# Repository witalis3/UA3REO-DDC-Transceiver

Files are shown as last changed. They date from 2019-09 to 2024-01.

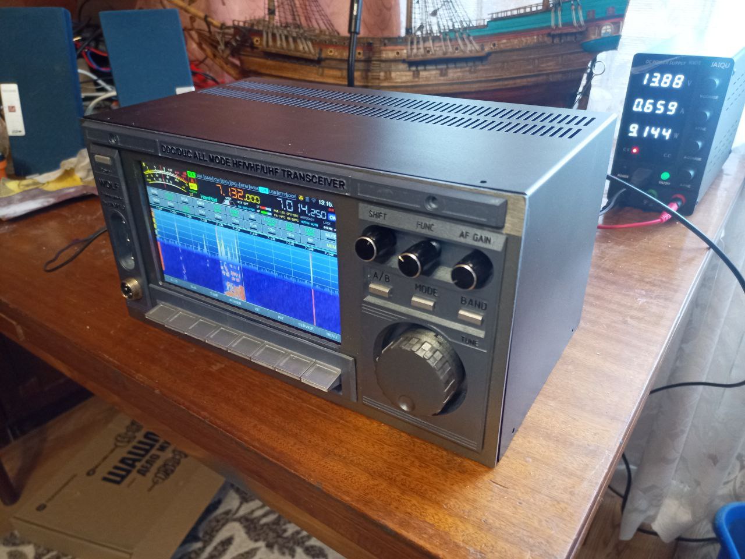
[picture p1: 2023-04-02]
Schematic/Wolf/CASE/7/Panel/photo_2023-04-01_13-19-56.jpg

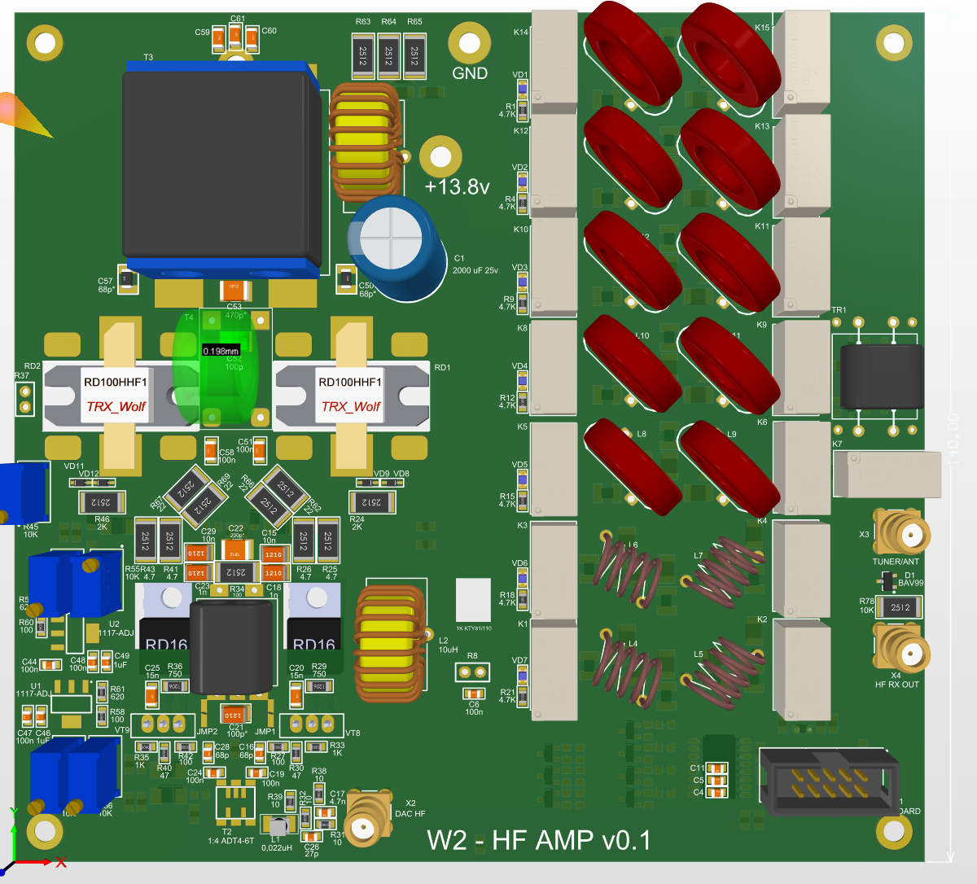
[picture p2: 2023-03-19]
Schematic/Wolf-2/Altium_Designer/W2-HF_AMP/HFAmp_UP_v01.png

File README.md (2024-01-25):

# Transceiver "Wolf"
DDC-DUC SDR Tranceiver project https://ua3reo.ru/tag/transiver-ua3reo/

* Community telegram channel: https://t.me/TRX_Wolf
* На русском https://github.com/XGudron/UA3REO-DDC-Transceiver/blob/master/README.ru-RU.md

## Principle of operation

The RF signal is digitized by a high-speed ADC chip and fed to an FPGA processor. <br>
It performs DDC / DUC conversion (digital frequency shift down or up the spectrum) - by analogy with a direct conversion receiver. <br>
The I and Q quadrature signals from the conversions are fed to the STM32 microprocessor. <br>
It filters, (de) modulates and outputs audio to an audio codec / USB. It also handles the entire user interface. <br>
When transmitting, the process occurs in the opposite order, only at the end of the chain there is a DAC, which converts the digital signal back to analog RF. <br>

## Specifications

* Receiving frequencies: 0 MHz - 750 MHz with fading each 61.44 MHz (above 145 MHz - without input filters)
* Transmission frequencies: 0 MHz - 150 MHz with fading on 110 MHz
* TX power (QRP version): 7W+ (HF), 5W (VHF)
* TX power (QRP++ DB5AT version): 20W (HF), 7W (VHF)
* TX power (RU4PN/WF-100D version): 100W (HF), 50W+ (VHF)
* Two antenna inputs
* Modulation types (TX / RX): CW, LSB, USB, AM, FM, WFM, DIGI
* LNA, Preamplifier
* Adjustable attenuator 0-31dB
* Band pass filters
* ADC dynamic range (16 bit) ~100dB
* Supply voltage: 13.8V (overvoltage and polarity reversal protection)
* Consumption current when receiving: ~0.7А (3'2 QRP), 0.9A (7' BIG)
* Current consumption during transmission: ~2.5А+ (QRP), 15A+ (BIG)
* Support for different displays: RA8875/HX8357B/HX8357C/ST7789/ST7796S/ST7735S/ILI9341/ILI9481/ILI9486

## Transceiver Features

* Panorama (spectrum + waterfall) up to 384 kHz wide
* Panorama tweaks and themes
* Dual receiver (mixing A + B or A&B audio in stereo)
* Adjustable bandwidth: HPF from 0Hz to 2700Hz, LPF from 100Hz to 20kHz
* Integrated SWR/power meter (HF)
* Automatic and manual Notch filter
* Switchable AGC (AGC) with adjustable attack rate
* Range map, with the ability to automatically switch modes
* Digital Noise Reduction (DNR), Pulse Noise Reduction (NB)
* CAT virtual COM port (FT-450 / TS-2000 emulation, RTS - PTT, DTR - CW)
* USB operation (audio transmission, IQ, CAT, KEY, PTT)
* RDS/CW/RTTY decoder, self-control, gauss filter
* SWR Graphs
* Spectrum analyzer
* FT8 receiver/transmitter
* Automatic send FT8 qso to log https://allqso.ru/
* WSPR Beacon
* VOX
* Equalizer TX/RX, reverber
* SSB/FM Scanner mode
* Support SDHC/SDSC/SDXC memory cards up to 16Gb
* WAV files radio recording and playback, fast broadcast recorded CQ message
* AGC takes into account the characteristics of human hearing (K-Weighting)
* TCXO frequency stabilization (it is possible to use an external clock source, such as GPS)
* WiFi operation: Time synchronization, virtual CAT interface (see Scheme/WIFI-CAT-instruction.txt)
* Tangent support Yaesu MH-36 и MH-48
* Hardware self-testing
* Firmware update over USB, SD, WiFi
* Digital pre-distortion
* And other.. (see menu)

### RF Parameters

Sensitivity at 10 dB SNR, LNA enabled:

* <150 MHz | -131 dBm | 63.0 nV
* 435 MHz | -121 dBm | 0.2 uV

Out-of-band emissions:

* 14 MHz -69 dBc
* 28 MHz -63 dBc
* 145 MHz -48 dBc -55 dBc

## Build

I ordered the boards in the Chinese service JLCPCB, they and their schemes are in the Scheme folder. <br>
After assembly, you need to flash FPGA and STM32 chips. <br>
If necessary, calibrate the transceiver through the appropriate menu <br>
WiFi module ESP-01 must have fresh firmware with SDK 3.0.4 and higher, and AT commands 1.7.4 and higher <br>

## Management

* **AF GAIN** - Volume
* **RIT / GAIN** - When the RIT function is active - smooth offset from the selected transceiver frequency. Inactive - IF gain control
* **ENC MAIN** - Main encoder for frequency control and menu settings
* **ENC 2** - Auxiliary encoder for menu operation. In normal mode, quickly switches the frequency, in CW fast change WPM
* **ENC 2[click]** - In CW mode, toggles between fast step and WPM selection, in other modes it opens the bandwidth properties.
* **BAND -** - Switch to the band below
* **BAND +** - Switch to higher band
* **MODE -** - Mode group switching SSB-> CW-> DIGI-> FM-> AM
* **MODE +** - Switching subgroup mod LSB-> USB, CW_L-> CW_U, DIGI_U-> DIGI_L, NFM-> WFM, AM-> IQ-> LOOP
* **FAST** - Mode of fast x10 rewinding of the frequency by the main encoder (configurable)
* **FAST [clamp]** - Frequency step settings
* **PRE** - Turn on the preamplifier (LNA)
* **PRE [clamp]** - Turn on the driver and / or amplifier ADC
* **ATT** - Turn on the attenuator
* **REC** - Save audio to SD card
* **CQ** - Play recorded CQ-message from SD card
* **MUTE** - Mute the sound
* **MUTE [clamp]** - Scanner mode
* **AGC** - Turn on AGC (automatic gain control)
* **AGC [clamp]** - AGC settings
* **A = B** - Setting the second bank of the receiver equal to the current
* **BW** - Switch to bandwidth selection menu (LPF)
* **BW [clamp]** - Switch to bandwidth selection menu (HPF)
* **TUNE** - Turn on the carrier for tuning the antenna
* **RF POWER** - Transmitter power selection
* **RF POWER [clamp]** - Squelch setting
* **A / B** - Switches between VFO-A / VFO-B receiver settings banks
* **A / B [clamp]** - Enable automatic mode change by bendmap
* **DOUBLE** - Turn on the dual receiver
* **DOUBLE [clamp]** - Switching between the modes of the dual receiver A&B (each channel of the headphones has its own path) or A + B (mixing signals of 2 receivers)
* **DNR** - Enable digital noise reduction
* **DNR [clamp]** - Turn on the impulse noise suppressor (NB)
* **NOTCH** - Turn on the automatic Notch filter to eliminate narrowband interference
* **NOTCH [clamp]** - Turn on the manual Notch filter to eliminate narrowband interference
* **SPLIT** - Allows you to split transmission and reception to different VFO banks
* **RIT [clamp]** - Enables RIT control from the front panel
* **WPM** - Switch to key speed selection menu (WPM)
* **WPM [clamp]** - Automatic key enable
* **MENU** - Go to the menu
* **MENU [clamp]** - Enable key lock LOCK
* **MENU [at power on]** - Reset transceiver settings
* **MENU [at power on+PRE]** - Reset transceiver settings and calibration
* **RIT** - Offset of the receiving frequency relative to the current frequency (TX without offset)
* **XIT** - Offset of the transmission frequency relative to the current frequency (RX without offset)

## Settings

### TRX Settings

* **Band Map** - Band Map, automatically switches mode depending on the frequency
* **Beeper** - Beep on key press
* **Callsign** - User callsign
* **Channel Mode** - Channel frequency mode (for LPD/PMR and etc.)
* **Custom Transverter** - Enable external transverter on non-ham band (just offset display frequency)
* **DEBUG Type** - Output of debug and service information to USB / UART ports
* **Encoder Accelerate** - Accelerate encoder on fast rates
* **Fine RIT Tune** - Fine or coarse tuning for RIT/XIT (encoder or resistor)
* **Freq Step xxx** - Frequency step by main encoder in each mode, Hz
* **FAST Step Multiplier** - Frequency step multiplier for FAST mode
* **ENC2 Step Mult** - Frequency step multiplier for ENC2 rotation (for CW/SSB)
* **Notch Step** - Frequency step of manual notch filter
* **Full Duplex** - Full duplex RX+TX mode
* **Locator** - User QTH locator
* **RIT Interval** - Offset range RIT (+ -)
* **XIT Interval** - Offset range XIT (+ -)
* **Split freq sync** - Synchronous VFO frequency change in SPLIT mode
* **Transverter XXcm** - Enable external ham band transverter support
* **URSI Code** - Ionogramm URSI Code https://digisonde.com/index.html#stationmap-section
* **Tropo Region** - Region for tropospheric forecast https://www.dxinfocentre.com/tropo.html 
* **Wolf Cluster** - Display Wolf TRX users on spectrum and send self data

### FILTERS Settings

* **AM/FM/CW/SSB LPF Stages** - Adjusting the slopes of the LPF filters in defferent modes
* **CW LPF Pass** - LPF cutoff frequency when working in CW
* **CW Gauss filter** - Gauss responce LPF filter
* **DIGI LPF Pass** - LPF cutoff frequency when working in DIGI
* **FM LPF Pass** - LPF cutoff frequency when working in FM
* **SSB HPF Pass** - HPF cutoff frequency when operating in SSB
* **SSB LPF Pass** - LPF cutoff frequency when operating in SSB
* **NOTCH Filter width** - Cutting width of Manual Notch filter

### RX Settings

* **ADC Dither** - Enable ADC dither for receiving weak signals
* **ADC Driver** - Turn on the preamplifier-ADC driver
* **ADC Preamp** - Turn on the preamplifier built into the ADC
* **ADC Randomizer** - Enables ADC digital line encryption
* **ADC Shutdown** - Turn off the ADC
* **AGC Gain target, LKFS** - Maximum AGC gain (Maximum volume with AGC on)
* **AGC Spectral** - Enable FFT-based AGC
* **AGC Threshold** - Enabling the AGC opening threshold
* **Att step, dB** - Attenuator tuning step
* **Attenuation, dB** - Current attenuation
* **Auto Snap** - Automaticly track and snap to near signal frequency (CW mode)
* **AutoGainer** - Automatic ATT / PREAMP control depending on the signal level on the ADC
* **A/B Balance** - Channels balance in dual RX modes A+B and A&B
* **CODEC Gain** - Adjusting AF gain in audio codec
* **DNR xxx** - Digital squelch adjustment
* **Squelch** - Enable SSB/AM/CW/FM Squelch
* **FM Squelch level** - FM squelch level
* **IF Gain, dB** - IF gain
* **NB Threshold** - Threshold of Noise blanker
* **Free tune** - Allows you to move the reception frequency across the spectrum without changing the center frequency of the spectrum itself
* **Center After Idle** - Center the spectrum with Free Tune active after 20 seconds of inactivity
* **Noise Blanker** - Activating the Surge Suppressor
* **RX AUDIO Mode** - Audio lines control: Stereo\Left\Right
* **RX AGC Hold time** - Time before release of AGC gain in signal peaks, ms
* **RX AGC Hold limit** - Burst limit for AGC delay time
* **RX AGC Hold step up** - AGC Delay Time Step on Peaks
* **RX AGC Hold step down** - AGC Delay Falloff Step at Peaks
* **RX AGC Max gain** - Limit of AGC gain, dB
* **RX AGC Speed** - AGC (automatic signal level control) response speed for reception (more-faster)
* **RX EQ xxx** - Receiver equalizer levels
* **TRX Samplerate** - Max FFT/samplerate on CW/SSB/NFM/DIGI/etc modes
* **FM Samplerate** - Max FFT/samplerate on NFM/WFM mode
* **VAD Threshold** - VAD voice detector threshold (noise suppressor for SSB mode and SCAN mode)
* **Volume step** - AF gain step by ENC2 (X1, Lite)
* **Volume** - AF gain
* **WFM Stereo** - select WFM stereo or mono decoder
* **WFM Stereo Modulation** - Stereo FM sub-carrier level

### TX Settings

* **ATU Cap** - Tuner Capacitance Combination
* **ATU Enabled** - Turning on the automatic antenna tuner
* **ATU Ind** - Combination of tuner inductances
* **ATU T** - Tuner capacitive arm position
* **ATU Mem step, kHz** - Step of saving tuner values for frequencies into memory
* **Auto Input Switch** - Auto input switch (PTT - mix, CAT - USB)
* **CESSB** - Enable controlled-envelope single-sideband modulation
* **CESSB Compress, dB** - Signal pre-amplification level before compression in CESSB
* **Compressor MaxGain** - Maximum comressor gain
* **Compressor Speed** - TX compressor response speed for transmission (more-faster)
* **CTCSS Frequency** - Transmit FM CTCSS sub-tone frequency
* **FT8 Auto CQ** - Automatic transition to CQ mode after FT8 communication
* **Input Type** - Select audio input (microphone, line in, USB)
* **LINE Gain** - Line input codec gain
* **MIC Boost** - +20db hardware mic amplifier
* **MIC EQ xxx** - Microphone equalizer levels
* **MIC Gain** - Microphone gain
* **MIC Noise Gate** - The level below which the microphone signal is muted, dbFS
* **MIC Reverber** - Microphone reverberator level
* **Power for each band** - Save power settings for each band individually
* **Power for each mode** - Save power settings for each mode individually
* **RF Power** - Transmission power,%
* **Repeater Mode"** -  Operation mode via repeater
* **Repeater offset, kHz"** -  Transmission frequency offset in repeater mode
* **SelfHear Volume** - Self Hearing (CW/DIGI) volume relative to the overall transceiver volume
* **TUNER Enabled** - Turning on the antenna tuner
* **Two Signal tune** - Two-signal generator in TUNE mode (1.0 + 2.2kHz)
* **VOX Threshold, dbFS** - VOX Threshold, dbFS
* **VOX Timeout, ms** - VOX transmission delay after silence, milliseconds
* **VOX** - TX Voice activation

### CW Settings

* **Auto CW Mode** - Automatic transition to CW mode when the key is pressed
* **CW In SSB** - Allow CW TX manipulation in SSB mode
* **DotToDash Rate** - Keyer dash to dot length rate
* **Edges smooth, ms** - Smoothing signal edges
* **Iambic Keyer** - Enable Iambic mode keyer
* **Iambic Type** - Type of Iambic keyer (A/B)
* **Key Invert** - Invert dash/dot on key
* **Key timeout** - Time before stopping the transmission mode after releasing the key
* **Keyer WPM** - Key Speed, WPM
* **Keyer** - Automatic Key
* **One symbol memory** - Keyer memory for one symbol for transmit
* **PTT Type** - RX/TX switch type for CW: by key or external PTT (tangent, etc.)
* **Pitch** - Detuning the receive generator from the transmit frequency
* **Self Hear** - Self-control CW (key press is heard)
* **Macros x** - Setting up macros for CW transmission
* **Macros x name** - Setting the macro name to be displayed in the interface

### SCREEN Settings

* **Bottom navi buttons** - Show bottm menu navigation buttons (for 7 inch displays)
* **Color Theme** - Select colors theme (0 - black, 1 - white, 2 - black with colored frequency)
* **Layout Theme** - Select interface theme (0 - default)
* **DX Cluster Type** - Selecting a Data Source for a DX Cluster
* **FFT 3D Mode** - Enable FFT 3D mode (0 - disabled, 1 - lines, 2 - pixels)
* **FFT Automatic** - Automatic FFT scale
* **FFT Averaging** - FFT burst averaging level. Full - automatic selection of upper and lower boundaries, Half - auto lower and manual upper, No - manual setting of the range of spectrum levels. (Remember to select the correct FFT Scale Type so that your range will fit on the screen)
* **FFT BW Style** - FFT bandwidth style: high opacity, low opacity, lines
* **FFT BW Position** - Position of the receiving band on FFT/WTF (everywhere \ at the top \ at the top + lines \ top + bottom with time delay)
* **FFT Background** - Gradient FFT background
* **FFT Color** - FFT colors: 1(blue -> yellow -> red), 2(black -> yellow -> red), 3(black -> yellow -> green), 4(black -> red), 5(black -> green), 6(black -> blue), 7(black -> white)
* **FFT Compressor** - Enable FFT peak comressor
* **FFT DXCluster Azimuth** - Add azimuth data to DX-cluster
* **FFT DXCluster Timeout** - Timeout of DX-cluser spots in minutes
* **FFT DXCluster** - Show DXCluster info over FFT
* **FFT Enabled** - Enable waterfall and FFT
* **FFT Freq Grid** - FFT and waterfall grids: 1(no grid), 2(fft grid), 3(fft+wtf grids), 4(wtf grid)
* **FFT Height** - FFT and waterfall proportional height
* **FFT Hold Peaks** - Show peaks on FFT spectrum
* **FFT Lens** - Enable FFT lens mode (magnify center of spectrum)
* **FFT Manual Bottom, dBm** - Bottom FFT threshold in manual mode
* **FFT Manual Top, dBm** - Top FFT threshold in manual mode
* **FFT Scale Type** - Y-axis style on FFT between signal amplitude and dBm to fit more dynamic range on screen (Useful when manually adjusting FFT range).
* **FFT Sensitivity** - Top threshold of FFT sensitivity in automatic mode (30 - scale to strongest signal)
* **FFT Speed** - FFT and waterfall speed
* **FFT Style** - FFT style: 1(gradient), 2(fill), 3(dots), 4(contour), 5(gradient + contour)
* **FFT Window** - Select FFT window (1-Dolph–Chebyshev 2-Blackman-Harris 3-Nutall 4-Blackman-Nutall 5-Hann 6-Hamming 7-No window)
* **FFT Zoom CW** - FFT spectrum zooming for CW Mode
* **FFT Zoom** - FFT spectrum zooming
* **FFT dBm Grid** - FFT signal power grid
* **LCD Brightness** - Set LCD brightness (not all lcd support)
* **LCD Sleep Timeout** - Idle time before the screen brightness decreases, sec (0 - disabled)
* **Show Sec VFO** - Show secondary VFO position on spectrum
* **WTF Color** - Waterfall colors: 1(blue -> yellow -> red), 2(black -> yellow -> red), 3(black -> yellow -> green), 4(black -> red), 5(black -> green), 6(black -> blue), 7(black -> white)
* **WTF Moving** - Mowe waterfall with frequency changing

### Decoders
* **CW Decoder** - Software CW receive decoder
* **CW Decoder Threshold** - CW receive decoder sensivity
* **RDS Decoder** - Enable RDS Decoder for WFM mode
* **RTTY Freq** - Central frequency of RTTY decoding
* **RTTY InvertBits** - RTTY invert 0 and 1 bits
* **RTTY Shift** - RTTY carrier shifts
* **RTTY Speed** - Speed of RTTY data
* **RTTY StopBits** - RTTY Stop bits

### WIFI Settings

* **WIFI Enabled** - Enable WiFi module (need restart after enable)
* **WIFI Network** - WiFi hotspot selection
* **WIFI Network Pass** - Set password for WiFi hotspot
* **WIFI Timezone** - Time zone (for updating the time via the Internet)
* **WIFI CAT Server** - Server for receiving CAT commands via WIFI
* **WIFI Update ESP firmware** - Start cloud autoupdate firmware for ESP-01 (if present)
* **ALLQSO.RU Token/LogId** - Token и LogID from https://allqso.ru/ web-log

### SD Card

* **File Manager** - Show SD Card file manager, support WAV playback and deleteing files, listening and broadcasting recordings, as well as updating firmware from a memory card
* **Record CQ message** - Record a short message for quick broadcast
* **USB SD Card Reader** - Enable USB SD Card reader
* **Export Settings** - Export settings and calibration data to SD card
* **Import Settings** - Import settings and calibration data from SD card
* **Format SD card** - Format media drive

### Satellites

* **SAT Mode** - Enable satellite mode
* **Download TLE** - Download current satellite data
* **Select SAT** - Select a satellite from the downloaded TLE file
* **QTH xxx** - Setting the Latitude\Longitude\Altitude of your location

### Calibration [appears by long pressing the MENU button in the settings menu]

* **ALC Port Enabled** - Activation of transceiver power control by an external amplifier via the ALC line: up to 1 volt - ALC is disabled and the power set in the transceiver is used. from 1.0v to 3.0v - power adjustment from 0 to 100%
* **ALC Inverted** - Invert ALC logic (3.0v - 0%, 1.0v - 100%)
* **AM Modulation Index** - Set TX AM Modulation Scale
* **ATU Averaging** - The number of steps of averaging SWR values during measurements in the operation of an automatic tuner
* **BPF x** - Bandpass filter parameters
* **CAT Type** - Type of CAT subsystem (FT-450 / TS-2000)
* **COM CAT DTR/RTS** - Configuring the functions of the DTR/RTS control lines of the CAT port
* **COM DEBUG DTR/RTS** - Configuring the functions of the DTR/RTS control lines of the Debug port
* **CICCOMP Shift** - Bit shift after CIC compensator
* **Calibrate reset** - Reset all calibrations to defaults
* **DAC Driver Mode** - DAC Driver OPA2673 bias mode (2 = 100% bias, 1 = 75% bias, 0 = 50% bias)
* **DAC Shift** - Bit shift of the output to the DAC
* **ENABLE 2200m/60m/6m/4m/FM/2m/AIR/Marine Band/70cm** - Enable hidden bands
* **EXT xxx** - External port control by band (EXT3, EXT2, EXT1, EXT0) - open drain
* **Encoder acceleration** - The encoder acceleration on faster rotation speeds
* **Encoder debounce** - Time of debouncing contacts of the main encoder
* **Encoder invert** - Invert the rotation of the main encoder
* **Encoder on falling** - The encoder is triggered only when level A falls
* **Encoder slow rate** - Deceleration rate of the main encoder
* **Encoder2 debounce** - Time of debouncing contacts of the additional encoder
* **Encoder2 invert** - Invert the rotation of the additional encoder
* **Encoder2 on fall** - Mode of operation of the secondary encoder (some encoders skip a step or make an extra one)
* **FAN Full start** - Temperature of the PA for starting the fan at full speed
* **FAN Medium start** - Temperature of the PA for starting the fan at medium speed
* **FAN Medium stop** - Temperature of the PA for stopping the fan
* **FAN Medium PWM** - Adjusting the duty cycle of a PWM fan in Medium mode
* **FM Deviation Scale** - Set TX FM Deviation Scale
* **Flash GT911** - Starting the touchpad update procedure according to LCD screen resolution
* **HPF START** - HPF filter parameters
* **IF Gain MIN/MAX** - IF Gain adjusting limits
* **INA226** - Activation and calibration of the INA226 voltage/current sensor on the I2C bus
* **KTY81 Calibration** - Calibration of the KTY81 sensor (setting the resistance of the divider arm)
* **LCD Rotate** - Rotate screen at 180 degrees
* **LNA Compensation** - Compensates the S-meter value when the LNA is turned on, dBm
* **ATT Compensation** - Compensates the S-meter value when the ATT is turned on
* **LPF END** - LPF filter parameters
* **Linear Pwr Control** - Sets a linear way to change the signal amplitude when adjusting the power (if disabled - logarithmic)
* **MAX ChargePump, kHz** - Maximum PWM frequency for ChargePump circuit
* **MAX PWR on Meter** - Maximim RF power (for indication)
* **MAX Power in TUNE** - Maximum RF power in Tune mode
* **MAX RF Temp** - Maximum temperature of the PA before the protection operation
* **MAX SWR** - Maximum VSWR before protection operation
* **NOTX xxx** - Disable TX on selected bands
* **OTA Update** - Enable OTA firmware update over WiFi
* **RF GAIN xxx** - Calibration of the maximum TX output power for each range
* **RF-Unit Type** - RF-Unit Type (QRP / BIG)
* **RTC COARSE CALIBR** - Very coarse clock crystal calibration
* **RTC FINE CALIBR** - Clock crystal calibration, one division is 0.954 ppm
* **S METER** - S-meter calibration
* **SSB Power addition** - Addition of RF power in SSB power, %
* **SWR FWD/BWD RATE** - Adjustment of the transformation ratio of the SWR meter (forward / return)
* **Swap USB IQ** - Swap USB IQ output
* **Settings reset** - Reset all settings to defaults
* **TCXO Frequency, kHz** - Frequency adjustment of the reference oscillator
* **VCXO Correction** - Correction for main generator frequency offset
* **Touchpad flip** - Flip the touchpad operation horizontally/vertically
* **Touchpad timeout** - Minimum time between taps (protection against false trigger), ms
* **Touchpad click threshold** - Minimum time for triggering a short click, ms
* **Touchpad click timeout** - Maximum time for triggering a short click, ms
* **Touchpad hold timeout** - Time before a long press is triggered, ms
* **Touchpad swipe threshold** - Minimum distance to trigger a swipe, px
* **TSignal Balance** - Sets the power balance between signals in Two signal tune mode
* **TX CICCOMP Shift** - Bit shift after TX CIC compensator
* **TX Start Delay** - Delay before the RF signal is applied (ms), so that the relay has time to trigger
* **Tangent Type** - Select tangent type
* **Transverter Offset, MHz** - Offset frequency shown on the display (for custom transverters)
* **Transverter xxx IF, MHz** - Setting the IF frequency of the transverter
* **Transverter xxx RF, MHz** - Setting the RF frequency of the transceiver to match the IF

### Memory Channels

* Changing names for transceiver memory channels

### Set Clock Time

* Clock setting

### DFU Mode

* Launch STM32 USB firmware update over DFU mode

### OTA Update

* Launch FPGA/STM32 firmware update over internet

### System info

* Show info about TRX

## Services

### Spectrum Analyzer

* **Spectrum START** - Start the spectrum analyzer
* **Begin, kHz** - Starting frequency of the analyzer with a step of 1 kHz
* **End, kHz** - End frequency of the analyzer in 1 kHz steps
* **Top, dBm** - Upper threshold of the graph
* **Bottom, dBm** - Lower threshold of the graph

### WSPR Beacon

* **WSPR Beacon START** - Start WSPR beacon
* **Freq offset** - Offset from center of WSPR band
* **WSPR Band xxx** - Select bands to WSPR beacon

### DX Cluster 

* Show DX Cluster info by current band (from internet)

### Propagation 

* Show propagation statistics (from internet)

### Tropo 

* Show tropospheric forecast

### DayNight Map 

* Displaying the day/night terminator on the map (from internet)

### Ionogram 

* Displaying the ionogram for the selected URSI Code (from internet)

### SWR Analyser

* Run SWR analizer (Band SWR - on current band, HF SWR - on all HF bands, Custom SWR - in selected range)

### RDA Statistics 

* Print statistics from RDA award (from internet)

### FT8

* FT8 Receiver / transmitter

### Locator Info

* Calculate distance and azimuth from QTH-locator

### Callsign Info

* Show callsign data

### Time Beacons

* List of beacons of the exact time (for adjusting the frequency of reception by carrier)

### Self Test

* Run hardware self diagnostic

### Auto calibration

* **Calibrate SWR** - Assistant in measuring SWR and power meter
* **Calibrate Power** - Assistant in adjusting RF Power output

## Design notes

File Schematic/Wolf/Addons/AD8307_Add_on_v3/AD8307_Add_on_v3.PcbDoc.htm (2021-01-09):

Altium Reporting Options

# File in Newer Format

Date | : | 04-Dec-20
Time | : | 18:56:06
Filename | : | C:\Tisho\MyProjects\SDR_Transciever\UA3REO-DDC\Tisho_Files\Boards\AD8307_Add_on_v2\AD8307_Add_on_v2.PcbDoc

Version | Warning
Release 10 | CAUTION - New Custom Grids and Guides were introduced. Be aware that your design might contain Custom Grids and Guides that cannot be read in previous versions.
Release 10 | CAUTION - New Structured Clusters were introduced. Be aware that your design might contain Structured Clusters that cannot be read in previous versions.
Release 10 | CAUTION - New PCB 3D Movie Manager was introduced. Be aware that your design might contain 3D PCB movie that cannot be read in previous versions.
Release 10 update 1 | CAUTION - New Clearance Rule subscopes targeting differential pairs were introduced. Be aware that your design might contain Clearance Rules using those subscopes that cannot be read in previous versions.
Release 10 update 15 | CAUTION - Support of Solder Mask and Paste Mask expansions for Tracks, Arcs, Fills and Regions was introduced. Be aware that your design might contain Solder Mask and Paste Mask expansions for these types of primitives that cannot be read in the version of Altium Designer you are currently using.
Release 12 | CAUTION - Air Gap Width previously controlled by Clearance rule is now controlled by Polygon Connect Style rule's newly introduced Air Gap Width (set to default value). Suggest reviewing each Polygon Connect Style rule's Air Gap Width attribute for correctness.
Release 13 | CAUTION - Silk To Solder Mask Clearance Rules are converted to Silkscreen Over Component Pads Rules.
Release 14 | CAUTION - The Differential Pairs Routing rule added support for control of the width. Be aware that these widths must be manually entered as Width rules in this version.
Release 15 | CAUTION - Support of separate solder masks for top & bottom of pads added.
Release 15.1 | CAUTION - Support Multi-line PCB Text added.
Release 16.0 | CAUTION - Pad/Via hole size tolerance value added.
Release 17.0 | CAUTION - Component parameters added.
Release 17.0 | CAUTION - Support of backdrilling
Release 17.1 | CAUTION - Support of waived violations
Release 17.1 | CAUTION - Support of object specific keepouts

This file was generated by a later version of the software

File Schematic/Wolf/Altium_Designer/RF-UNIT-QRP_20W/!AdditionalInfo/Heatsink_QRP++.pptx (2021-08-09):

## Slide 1

Used 2 heatsinks:
SK 81/100/SA (https://www.reichelt.de/kuehlkoerper-100-mm-alu-2-2-k-w-sk-81-100-sa-p227984.html?trstct=pos_0&nbc=1) – 100 x 100 mm, Alu, 2,2 K/W
SK 81/75/SA (https://www.reichelt.de/kuehlkoerper-75-mm-alu-2-5-k-w-sk-81-75-sa-p227987.html?&trstct=pos_0&nbc=1) – 100 x 75 mm, Alu, 2,5 K/W

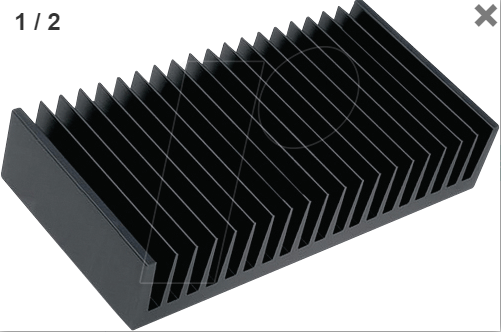
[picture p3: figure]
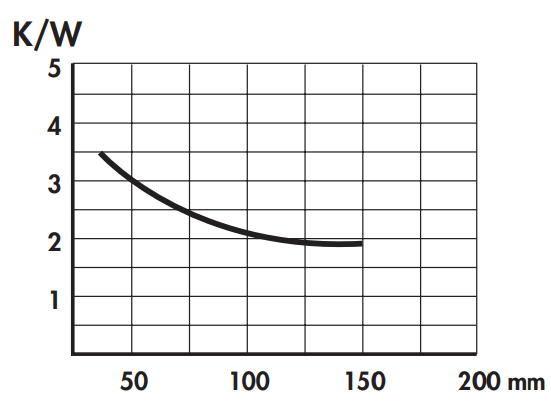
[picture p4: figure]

SK 81/100/SA drill dimensions

100

100

7x M3

9,5

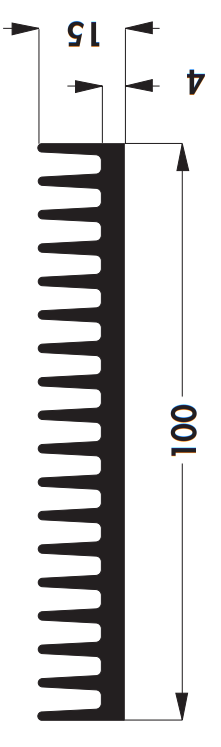
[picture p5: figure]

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
26,5

Dimensions 1

Dimensions 2

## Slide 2

SK 81/75/SA drill dimensions

75

9,5

10

10

100

9,5

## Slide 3

Bottom cover
(Dimensions 1)

11,1

17,6

17,6

103,2

11,1

97,6

117,6

190,2

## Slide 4

Bottom cover
(Dimensions 2)

115

103,2

9,5

62

190,2

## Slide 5

Copper block 1 (TIM)
- Size 39x30x10

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
2 x Ф 3,5

15,4

35

6,1

12

7

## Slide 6

Copper block 1 (TIM)
- Size 39x20x8

8

39

15,4

2 x Ф 3,5

35

6,1

20

12

7

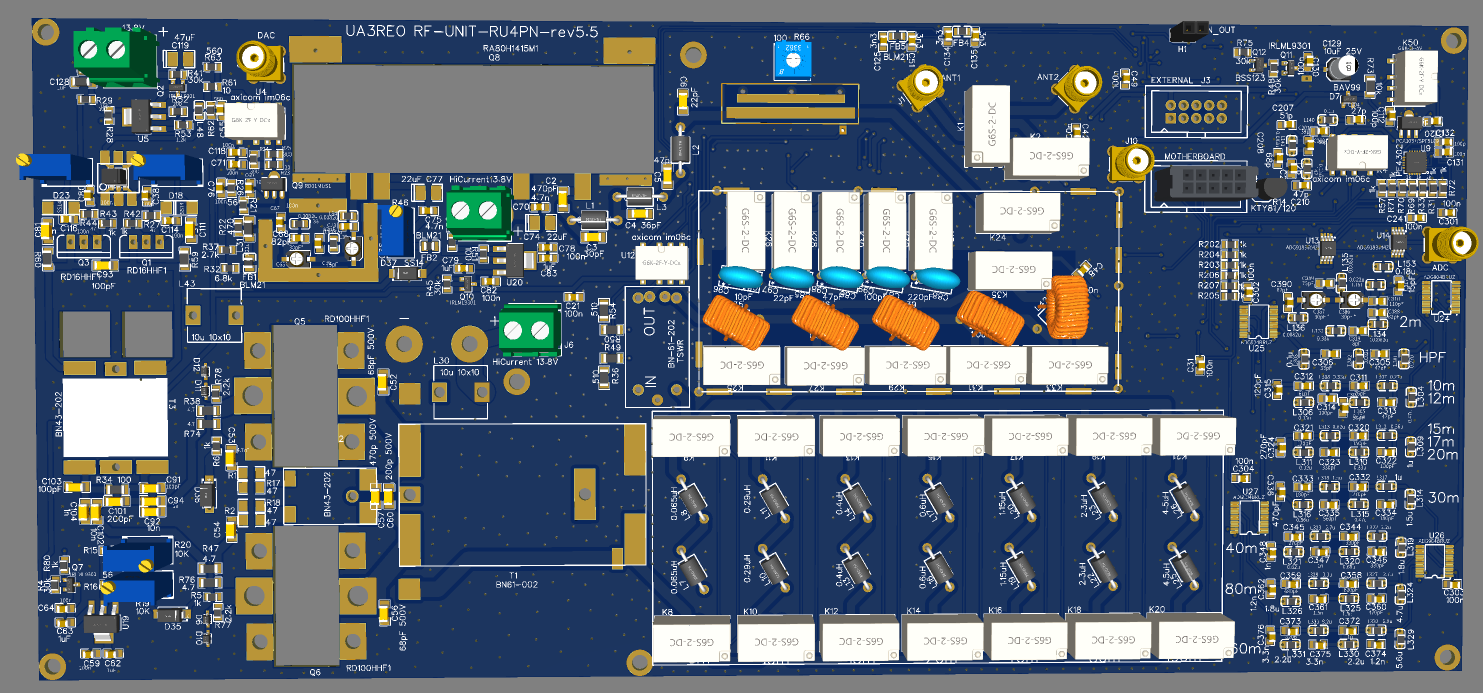
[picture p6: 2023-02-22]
Schematic/Wolf/Assembly/SCHEMATIC-RF-UNIT-BIG-RU4PN-rev5.5_UP.png

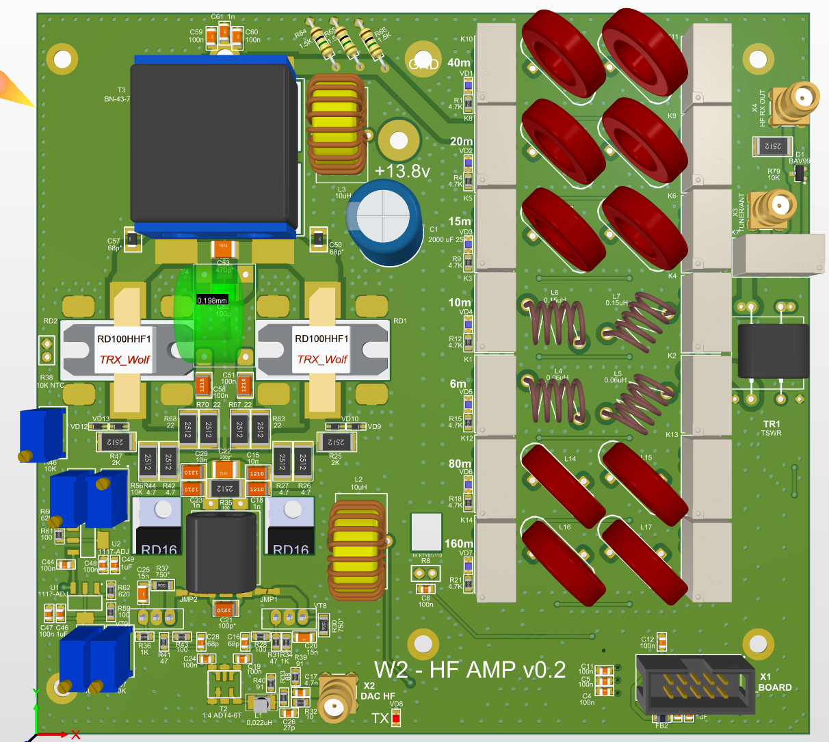
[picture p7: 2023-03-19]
Schematic/Wolf-2/Altium_Designer/W2-HF_AMP/HFAmp_UP_v02.png

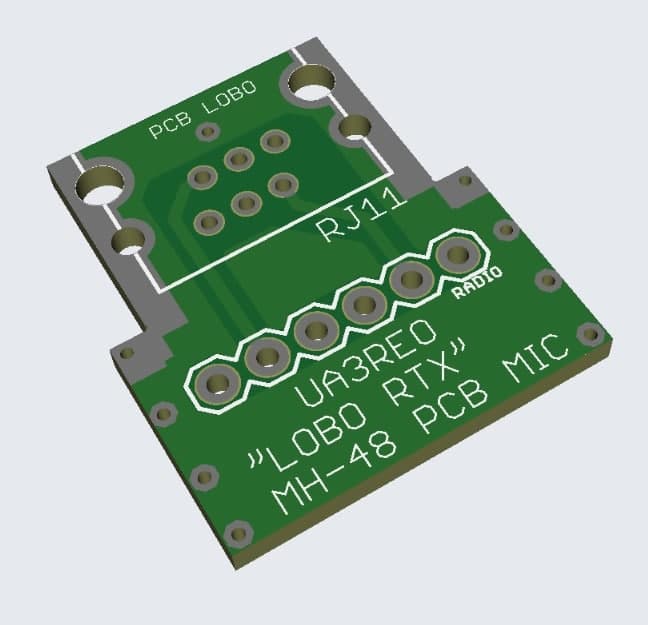
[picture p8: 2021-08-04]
Schematic/Wolf/Addons/PCB MIC MH-48/pcb2.jpg

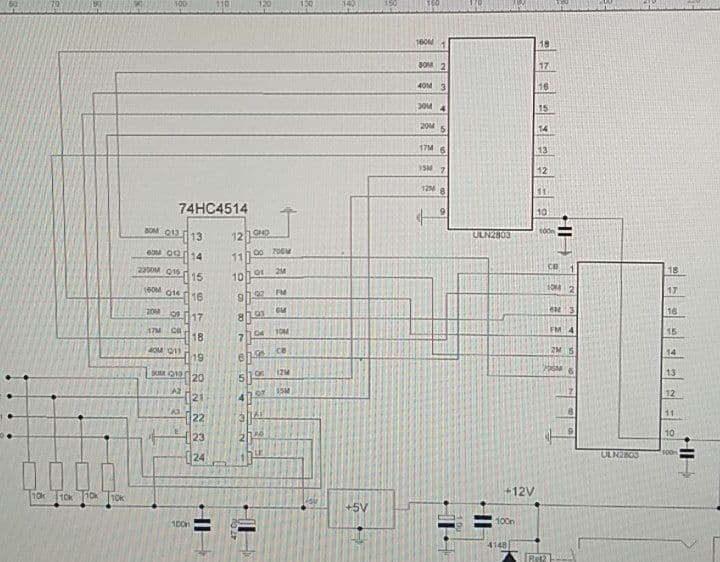
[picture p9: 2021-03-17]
Schematic/Wolf/Addons/LPF_switch.jpg

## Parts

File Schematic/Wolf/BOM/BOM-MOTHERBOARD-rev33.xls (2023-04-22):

Comment | Description | Designator | Footprint | LibRef | Quantity | LCSC Part #
JX2 | JX2 | 13.8V + | JX2 | JX2 | 1
51022-0300_1 | 51022-0300 | A_OUT, MIC_IN2 | 51022-0200 - duplicate | 51022-0300_1 | 2
CR1220 + | BR1632A/FA | B1 | KLS5-CR1220-01 | BR1632A/FA | 1
 | 2 Pin | BOOT | 51022-0200 | 51022-0200 | 1
4.7uF 16V | CAPAE_6.6x6.6h5.4 | C1 | SMC | CAPAE_6.6x6.6h5.4 | 1
22uF 10V | CAPAE_4.3x4.3h5.4 | C2, C125, C126 | CAPAE_4.3x4.3h5.4 | CAPAE_4.3x4.3h5.4 | 3
100n | CAP_0805 | C3, C4, C5, C6, C9, C16, C19, C21, C23, C31, C44, C45, C46, C47, C48, C49, C51, C53, C56, C57, C58, C59, C61, C62, C65, C67, C69, C70, C71, C72, C73, C74, C76, C78, C79, C81, C82, C83, C84, C86, C87, C88, C89, C91, C93, C94, C95, C96, C97, C98, C99, C100, C107, C109, C110, C112, C113, C114, C115, C117, C118, C120, C123, C124, C135 | CAP_0805 | CAP_0805 | 65
1uF | CAP_0805 | C7, C11, C12, C13, C14, C15, C35, C92, C119, C121, C122, C1003, C1004 | CAP_0805 | CAP_0805 | 13
10uF 10V | CAPAE_4.3x4.3h5.4 | C8, C20, C22, C24, C32, C54, C60, C75, C77, C80, C85, C1002 | CAPAE_4.3x4.3h5.4 | CAPAE_4.3x4.3h5.4 | 12
470p | CAP_0805 | C10, C90, C104, C116 | CAP_0805 | CAP_0805 | 4
10uF 10V | CAP_0805 | C17 | CAP_0805 | CAP_0805 | 1
1uF 10V | CAPAE_4.3x4.3h5.4 | C25, C26, C29 | CAPAE_4.3x4.3h5.4 | CAPAE_4.3x4.3h5.4 | 3
220p | CAP_0805 | C27, C28, C30 | CAP_0805 | CAP_0805 | 3
220uF 10V | CAPAE_4.3x4.3h5.4 | C33, C34 | EEEFC_size� | CAPAE_4.3x4.3h5.4 | 2
100pF | CAP_0805 | C36 | CAP_0805 | CAP_0805 | 1
10n | CAP_0805 | C37, C63, C137 | CAP_0805 | CAP_0805 | 3
6pF | CAP_0805 | C38, C39 | CAP_0805 | CAP_0805 | 2
10uF | CAP_0805 | C40, C41, C50, C52, C64, C66, C68 | CAP_0805 | CAP_0805 | 7
22p | CAP_0805 | C42, C43 | CAP_0805 | CAP_0805 | 2
7.5p | CAP_0805 | C55 | CAP_0805 | CAP_0805 | 1
10uF 20V | CAPAE_4.3x4.3h5.4 | C101, C108 | CAPAE_4.3x4.3h5.4 | CAPAE_4.3x4.3h5.4 | 2
1uF | CAP_1206 | C102, C103 | CAP_1206 | CAP_1206 | 2
680p | CAP_1206 | C105, C106 | CAP_1206 | CAP_1206 | 2
10p | CAP_0805 | C127 | CAP_0805 | CAP_0805 | 1
8.2n | CAP_0805 | C136 | CAP_0805 | CAP_0805 | 1
1n | CAP_0805 | C1001 | CAP_0805 | CAP_0805 | 1
SMAJ5.0A-TR | Diode | D1, D3, D29, D30, D31, D34, D35, D36, D37, D38, D39, D40 | SMBJ36CATR | SMLVT3V3 | 12 | [NoParam], test
SS34 | Schottky Diode | D1001 | SMB | D Schottky | 1
Diode | Default Diode | D1002 | C1206 | Diode | 1
SJ1-3525NG | SJ1-3525NG | J1, J2, J3, J5 | SJ1-3525NG | SJ1-3523N | 4
RF-UNIT | 2*5 Pin | J4 | 90131-0126 | 90131-0126 | 1
FPC-45P-0.5mm | Connector | J6 | FH12S45S05SH60 | FH12S-45S-0.5SH_55_ | 1
FAN | 51022-0200 | J7 | 51022-0200 | 51022-0200 | 1
USB | 2-1734035-3 | J8 | 2-1734035-3 | 2-1734035-3 | 1
DAC_OUT | SMA | J9 | 31-5431 | 31-5431 | 1
ADC | SMA | J10 | 31-5431 | 31-5431 | 1
 | 2*5 Pin | JTAG_FPGA, JTAG_STM32 | IDC10 | IDC10 | 2
3.3uH | IND_1812 | L1, L9 | IND_1812 | IND_1812 | 2
BLM21 | BLM21 | L3, L8 | CAP_0805 | IND_FERRITE_BEAD | 2
22uH | IND_1206 | L7 | IND_7x7 | IND_1206 | 1
10uH | Inductor | L37, L1001 | IND_7x7 | IND_FERRITE_CORE | 2
10uH | IND_1812 | L1002 | IND_1812 | IND_1812 | 1
PTT_IN | 51022-0200 | PTT_IN | 51022-0200 | 51022-0200 | 1
2SC5103TLP | Transistor BJT NPN | Q1 | 2SC5103TLQ | 2SC5103TLP | 1
7.5k | RES_0805 | R1 | RES_0805 | RES_0805 | 1
39k | RES_0805 | R2 | RES_0805 | RES_0805 | 1
0/NONE | By used crystal | R3 | RES_0805 | RES_0805 | 1
NONE / 0 | RES_0805 | R4, R1001, R1002 | RES_0805 | RES_0805 | 3
5.6k | RES_0805 | R5, R6, R7, R9, R51 | RES_0805 | RES_0805 | 5
30k | RES_0805 | R8, R55 | RES_0805 | RES_0805 | 2
10k | RES_0805 | R10, R13, R24, R27, R28, R30, R31, R32, R33, R36, R37, R38, R39, R46, R47, R48, R56, R57 | RES_0805 | RES_0805 | 18
680 | RES_0805 | R11 | RES_0805 | RES_0805 | 1
47k | RES_0805 | R12, R14, R15, R45 | RES_0805 | RES_0805 | 4
1.5k | RES_0805 | R16, R66 | RES_0805 | RES_0805 | 2
1k | RES_0805 | R17, R18, R19, R25, R26, R49, R50, R52 | RES_0805 | RES_0805 | 8
130 | RES_0805 | R20, R21 | RES_0805 | RES_0805 | 2
82 | RES_0805 | R22, R23 | RES_0805 | RES_0805 | 2
1m | RES_0805 | R29 | RES_0805 | RES_0805 | 1
100 | RES_0805 | R34, R35 | RES_0805 | RES_0805 | 2
22 | RES_0805 | R40, R53, R54, R58 | RES_0805 | RES_0805 | 4
24 | RES_0805 | R41, R42, R43, R64, R65 | RES_0805 | RES_0805 | 5
200 | RES_0805 | R44 | RES_0805 | RES_0805 | 1
 | RES_0805 | R59, R60 | RES_0805 | RES_0805 | 2
330 | RES_0805 | R61 | RES_0805 | RES_0805 | 1
5.6 | RES_1206 | R62, R63 | RES_1206 | RES_1206 | 2
56 | RES_0805 | R67 | RES_0805 | RES_0805 | 1
10 | RES_0603 | R68, R69 | RES_0603 | RES_0603 | 2
Thermistor 20k | Thermistor | R70 | MF52A103F3950A1 | MF52A103F3950_A1_ | 1
ADJ-5k | 306J | R71 | 306J | 306J | 1
0 | RES_0805 | R1003 | RES_0805 | RES_0805 | 1
1:1+1 | Transformer | T3 | TRANSF_ACORE2 | TRANSF_ACORE2 | 1
1:4 ADT4-6T | Transformer | T4 | TRANSF_ACORE2 | TRANSF_ACORE2 | 1
1:1 | Transformer | T6 | TRANSF_ACORE | TRANSF_ACORE | 1
PAM8406 | PAM8406 | U1 | PAM8403 | PAM8406 | 1
LD3985 | LD3985 | U2 | LD3985 | LD3985 | 1
ST1S10 | ST1S10 | U3 | ST1S10 | ST1S10 | 1
WM8731 | WM8731 | U4 | WM8731 | WM8731 | 1
STM32H743VIT6-rev.V | STM32H743VIT6 | U5 | STM32H743VIT6 | STM32H743VIT6 | 1
LM1084IS-3.3 | LM1084IS-3.3 | U6 | LM1085-3.3 | LM1085-3.3 | 1
W25Q16 | W25Q16 | U7 | W25Q16 | W25Q16 | 1
DAC5674 | Integrated Circuit | U8 | QFP50P900X900X100-49N | DAC5674IPHP | 1
25P80 | 25P80 | U9 | 25P80 | 25P80 | 1
EP4CE22E22C8N | EP4CE22E22C8N | U10 | QFP144-20-2222A | EP4CE22E22C8N | 1
1117DT-2.5 | LD1117DT-2.5 DPAK | U11 | TO228P991X238-3N | LM1117DT-ADJ | 1
1117DT-1.2 | LD1117DT-1.2 DPAK | U12 | TO228P991X238-3N | LM1117DT-ADJ | 1
1117-3.3 | LT1117CST-3.3 | U13 | LT1117CST-3.3 | LT1117CST-3.3 | 1
1117-1.8 | LT1117CST-1.8 | U14 | LT1117CST-3.3 | LT1117CST-3.3 | 1
SPEAKER | 4 pins conn | U15 | speaker conn | speaker conn | 1
LTC2208CUP | LTC2208CUP | U16 | LTC2208CUP | LTC2208CUP | 1
LTC6400IUD | Single Channel, Low Noise, Low Distortion Differential ADC Driver for 300 MHz IF, 1800 MHz Typical GBW, 4500 V/us Typical SR, 2.85 to 3.5 V, 16-Pin QFN (UD-16), Industrial, Pb-Free | U17 | LT-UD-16_N | CMP-0359-03855-2 | 1
1117DT-3.3 | LD1117DT33 DPAK | U18 | TO228P991X238-3N | LM1117DT-ADJ | 1
ADUM4160 | Integrated Circuit | U19 | SOIC127P1032X265-16N | ADUM4160BRWZ | 1
OPA2673 | Integrated Circuit | U20 | QFN65P400X400X100-17N-D | OPA2673IRGVT | 1
LM2940S-12/NOPB | 1-A, 26-V, high-PSRR, low-dropout voltage regulator | U21 | TO254P1524X483-4N | LM2940S-12/NOPB | 1
122.88Mhz | NV7050SA VG-4513CA-122.8800M-GGCT3 | XG1 | NV7050SA | NV7050SA | 1
12.288Mhz TCXO 3.3v TTL/CMOS (set other freq in fpga code) | Crystal or Oscillator | XG2 | 581L200X2ITT | 581L200X2ITT | 1
ABS25-32.768KHZ-6-T | Crystal or Oscillator | Y1 | ABS25 | ABS25-32.768KHZ-6-T | 1
8mhz | ECS-200-20-1 | Y2 | ECS-200-20-1 | ECS-200-20-1 | 1

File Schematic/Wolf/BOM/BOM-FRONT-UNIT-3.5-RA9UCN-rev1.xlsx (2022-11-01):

Comment | Description | Designator | Footprint | LibRef | Quantity
JX2 | JX2 | ACCUM, IN, MOTHERBOARD, RF-UNIT | JX2 | JX2 | 4
100n | CAP_0805 | C1, C2, C9, C14, C15, C16, C17, C18, C19, C20, C21, C22, C23, C24, C25, C26 | CAP_0805 | CAP_0805 | 16
1uF | CAP_1206 | C3 | CAP_1206 | CAP_1206 | 1
100n | CAP_1206 | C4 | CAP_1206 | CAP_1206 | 1
1n | CAP_1206 | C5 | CAP_1206 | CAP_1206 | 1
1000uF | CAP250RP | C6 | CAP250RP | CAP250RP | 1
470pF | CAP_1206 | C7 | CAP_1206 | CAP_1206 | 1
120pF | CAP_1206 | C8 | CAP_1206 | CAP_1206 | 1
22uF | EEEFC_sizeB | C10 | EEEFC_sizeB | EEEFC_sizeB | 1
8.2n | CAP_1206 | C11 | CAPC2013X94X50LL20T25 | CMP-2007-04444-1 | 1
10n | CAP_0805 | C12, C13 | CAP_0805 | CAP_0805 | 2
470uF | 10x7.7, 8.7, 10, 10.5, 12.5 | C1001, C1002 | SMD-G-10X10.2 | _SMD-G-10 | 2
1n4148w | Diode | D25, D27 | SOD3716X135N | 1n4148w | 2
SM6T15A | Diode | D28 | SMBJ36CATR | SM6T15A | 1
PEC12 | PEC12 | ENC2 | PEC12 | PEC12 | 1
OPTICAL ENCODER | OPTICAL ENCODER | ENCODER_MAIN | 644456-4 | 644456-4 | 1
ESP-01 ESP8266 | ESP-01 ESP8266 | ESP-8266 | ESP-01 ESP8266 | ESP-01 ESP8266 | 1
RUEF400 | Fuse | F1 | RUEF400 | RUEF400 | 1
MF-MSMF110_16-2 | Fuse | F2 | FUSC4632X85N | MF-MSMF110_16-2 | 1
PJ-050B | PJ-050B | IN_2 | PJ-050B | PJ-050B | 1
DM3AT-SF-PEJM5 | Connector | J2 | DM3ATSFPEJM5 | DM3AT-SF-PEJM5 | 1
FPC-45P-0.5mm | Connector | J7 | FH12S45S05SH60 | FH12S-45S-0.5SH_55_ | 1
 | LCD-MODULE_3'2_480�320 | LCD-MODULE | LCD-MODULE-3.2-480-320 | LCD-MODULE_3'2_480�320 | 1
ESP-07S |  | M1 | ESP-07S | ESP-07S | 1
IRFR9024NPBF | IRFR9024NPBF | Q1 | ONSC-DPAK-3-369C-01_V | CMP-1058-00387-1 | 1
BSS123 | N-Channel Logic Level Enhancement Mode Field Effect Transistor, 1.7 V, -55 to 150 degC, 3-Pin SOT-23, RoHS, Tape and Reel | Q2 | FAIR-SOT23-3_V | CMP-2000-04934-1 | 1
ptv09a-4225f-b102 | Adjustable Resistor PTV09 | R1, R2 | PTV09 | PTV09 | 2
4.7k | RES_0805 | R3, R4, R5, R6, R7, R8, R9, R10, R11, R12, R13, R14, R15, R16, R17, R18, R19, R29, R30, R31, R32, R33, R34, R35, R36 | RES_0805 | RES_0805 | 25
3.3k | RES_0805 | R20, R21, R22 | RES_0805 | RES_0805 | 3
0 | RES_0805 | R23, R24, R25 | RES_0805 | RES_0805 | 3
30k | RES_0805 | R26, R27, R28 | RESC2013X60X40NL20T25 | CMP-2001-00626-1 | 3
PTS645SK50LFS | PTS645SK50LFS | S1, S2, S3, S4, S5, S6, S7, S8, S9, S10, S11, S12, S13, S14, S15, S16, S17, S18, S19, S20, S21, S22, S23 | PTS645SK50LFS | PTS645SK50LFS | 23
BNX016-01 | BNX016-01 | T1 | TRANSF_ICORE | TRANSF_ICORE | 1
MCP3008-I/SL | MCP3008-I/SL | U1, U2, U3 | MCP3008-I/SL | MCP3008-I/SL | 3

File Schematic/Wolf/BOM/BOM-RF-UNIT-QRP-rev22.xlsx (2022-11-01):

Comment | Description | Designator | Footprint | Quantity
0 | RES_0805 | R49, R50 | RES_0805 | 2
0 | RES_1206 | R34, R38 | RES_1206 | 2
1:1 | 1:1 | T5 | TRANSF_ACORE2 | 1
1k | RES_0805 | R28, R29, R35, R42, R43 | RES_0805 | 5
1k | RES_0805 | R31, R65, R71, R72, R73, R74, R75, R76, R77, R78, R79, R80, R81, R82, R83, R84, R85 | RESC2013X60X40NL20T25 | 17
1n | CAP_0805 | C47, C112, C115, C120 | CAP_0805 | 4
1n | CAP_0805 | C122 | 6-0805_M | 1
1n8 | CAP_1206 | C105 | CAP_1206 | 1
1n8 100V | CAP_1206 | C92, C94 | CAP_1206 | 2
1N4148 | 1N4148 | D4 | 1N4148 | 1
1uF | CAP_0805 | C126, C128 | CAP_0805 | 2
1uH | IND_0805 | L17 | IND_0805 | 1
1.1n | CAP_0805 | C72, C74 | CAP_0805 | 2
1.2k | RES_0805 | R53 | RES_0805 | 1
1.2n | CAP_0805 | C62 | CAP_0805 | 1
1.3n | CAP_0805 | C61 | CAP_0805 | 1
1.3uH | IND_0805 | L18 | IND_0805 | 1
1.5uH | IND_0805 | L14, L25 | IND_0805 | 2
1.6uH | IND_0805 | L26 | IND_0805 | 1
2k | RES_0805 | R13 | RESC2013X60X40NL20T25 | 1
2uH | IND_0805 | L19, L22, L39, L47 | IND_0805 | 4
2.2uF | CAP_1206 | C95 | CAP_1206 | 1
2.2uF 100V | CAP_1206 | C91, C93 | CAP_1206 | 2
2.2uH | IND_0805 | L30 | IND_0805 | 1
2.4uH | IND_0805 | L31 | IND_0805 | 1
2.7uH | IND_0805 | L23, L27 | IND_0805 | 2
3n | CAP_0805 | C76 | CAP_0805 | 1
3.3n | CAP_0805 | C75 | CAP_0805 | 1
3.6uH | IND_0805 | L28 | IND_0805 | 1
4.3uH | IND_0805 | L24 | IND_0805 | 1
6.2uH | IND_0805 | L29 | IND_0805 | 1
6.5-30p | TZC3P300A110 | C86, C87 | 5025[2010] | 2
6.8uH | IND_0805 | L32 | IND_0805 | 1
8p | CAP_0805 | C16, C19 | CAP_0805 | 2
8T M2000HM 10*6*5 | Transformer | T1 | Rutrof 2 | 1
8T M2000HM 10*6*5 | Transformer | T3 | Rutrof | 1
8.2nH | IND_0805 | L34, L35, L36 | IND_0805 | 3
9.1uH | IND_0805 | L33 | IND_0805 | 1
10k | RES_0805 | R37 | RESC2013X60X40NL20T25 | 1
10k | RES_1206 | R1 | RES_1206 | 1
10n | CAP_0805 | C121 | 6-0805_M | 1
10uF 25V | CAPAE_5.3x5.3h6.1 | C129 | CAPAE_5.3x5.3h6.1 | 1
10uH | Inductor | L37, L38, L43 | IND_FERRITE_CORE | 3
11p | CAP_0805 | C103 | CAP_0805 | 1
15p | CAP_0805 | C18 | CAP_0805 | 1
15pF | CAP_0805 | C17 | CAP_0805 | 1
18 | RES_1206 | R39 | RES_1206 | 1
20p | CAP_1206 | C123, C125 | CAP_1206 | 2
22nH | IND_0805 | L48, L49, L51 | IND_0805 | 3
27nH | IND_0805 | L50 | IND_0805 | 1
27p | CAP_0805 | C55, C104 | CAP_0805 | 2
30k | RES_0805 | R33, R45, R70 | RESC2013X60X40NL20T25 | 3
30k | RES_0805 | R41, R57 | RES_0805 | 2
33p | CAP_0805 | C6 | CAP_0805 | 1
36p | CAP_1206 | C124 | CAP_1206 | 1
43p | CAP_0805 | C101 | CAP_0805 | 1
47p | CAP_0805 | C5, C13, C110 | CAP_0805 | 3
47uF 25V | CAPAE_6.6x6.6h5.4 | C119 | CAPAE_6.6x6.6h5.4 | 1
50 | RES_1206 | R55, R56 | RES_1206 | 2
56 | RES_0805 | R27, R44 | RES_0805 | 2
56p | CAP_0805 | C107 | CAP_0805 | 1
62p | CAP_0805 | C12, C102 | CAP_0805 | 2
68nH | Inductor | L44, L45 | IND_FERRITE_CORE_1 | 2
68p | CAP_0805 | C108 | CAP_0805 | 1
82p | CAP_0805 | C11 | CAP_0805 | 1
91nH | IND_0805 | L2, L41 | IND_0805 | 2
100n | CAP_0805 | C1, C2, C3, C4, C38, C80, C113, C114, C116, C117, C118, C130, C133, C134, C135, C136, C137, C139, C140, C141, C142 | CAP_0805 | 21
100n | CAP_0805 | C131 | 6-0805_M | 1
100n | CAP_1206 | C81, C111 | CAP_1206 | 2
100nH | IND_0805 | L3, L40 | IND_0805 | 2
100p | CAP_0805 | C9 | CAP_0805 | 1
100p | CAP_0805 | C127, C132 | 6-0805_M | 2
110p | CAP_0805 | C8, C10, C22, C89 | CAP_0805 | 4
120 | RES_0805 | R32, R46 | RES_0805 | 2
120p | CAP_0805 | C15, C21 | CAP_0805 | 2
130p | CAP_0805 | C14, C88, C90 | CAP_0805 | 3
160nH | IND_0805 | L5, L42 | IND_0805 | 2
160p | CAP_0805 | C20 | CAP_0805 | 1
180nH | IND_0805 | L6, L53, L54 | IND_0805 | 3
180p | CAP_0805 | C33, C34 | CAP_0805 | 2
200 | RES_0805 | R52 | RES_0805 | 1
220nH | IND_1206 | L46 | IND_1206 | 1
240p | CAP_0805 | C32 | CAP_0805 | 1
270nH | IND_0805 | L1, L7 | IND_0805 | 2
270p | CAP_0805 | C24, C45 | CAP_0805 | 2
300 | RES_1206 | R47, R48 | RES_1206 | 2
300p | CAP_0805 | C23 | CAP_0805 | 1
330nH | IND_0805 | L10, L52, L55 | IND_0805 | 3
330p | CAP_0805 | C44 | CAP_0805 | 1
360nH | IND_0805 | L8, L11 | IND_0805 | 2
360p | CAP_0805 | C46 | CAP_0805 | 1
470nH | IND_0805 | L4, L15 | IND_0805 | 2
470p | CAP_0805 | C36, C60 | CAP_0805 | 2
510 | RES_0805 | R36, R54 | RES_0805 | 2
510p | CAP_0805 | C35 | CAP_0805 | 1
560 | RES_0805 | R3, R7, R8, R9, R10, R11, R12 | RES_0805 | 7
560nH | IND_0805 | L16 | IND_0805 | 1
560p | CAP_0805 | C59 | CAP_0805 | 1
620nH | IND_0805 | L12 | IND_0805 | 1
680nH | IND_0805 | L20 | IND_0805 | 1
750nH | IND_0805 | L21 | IND_0805 | 1
750p | CAP_0805 | C58 | CAP_0805 | 1
820nH | IND_0805 | L13 | IND_0805 | 1
820p | CAP_0805 | C73 | CAP_0805 | 1
910nH | IND_0805 | L9 | IND_0805 | 1
910p | CAP_0805 | C48 | CAP_0805 | 1
2027-07-SM-RPLF | 2027-07-SM-RPLF | U18 | 200307SMRPLF | 1
51022-0200 | 51022-0200 | AMP1_PWR, AMP2_PWR, FAN_OUT | 51022-0200 | 3
ADC | SMA | J2 | 31-5431 | 1
ADG904BRUZ-R | Integrated Circuit | U4, U15, U16, U17 | SOP65P640X120-20N | 4
ADG918BRMZ | Integrated Circuit | U8, U10, U11, U12, U13, U14 | SOP65P490X110-8N | 6
ADJ-1k | 306J | R30, R40 | 306J | 2
ANT1 | SMA | J1 | 31-5431 | 1
ANT2 | SMA | J5 | 31-5431 | 1
Axicom V23079 | Axicom V23079 | K1 | V23079 | 1
BAT46JFILM | Diode | D1, D3 | SOD2513X117N | 2
BAV99 | BAV99 | D24 | SOT23 | 1
BSS123 | N-Channel Logic Level Enhancement Mode Field Effect Transistor, 1.7 V, -55 to 150 degC, 3-Pin SOT-23, RoHS, Tape and Reel | Q6, Q7, Q8 | FAIR-SOT23-3_V | 3
DAC | SMA | J9 | 31-5431 | 1
EXTERNAL | 2*5 PIN | J3 | 90131-0126 | 1
IRLML9301 | MOSFET | Q2, Q5 | SOT23 | 2
JX2 | JX2 | J8 | 1986717-2 | 1
KTY81/120 | Integrated Circuit | R14 | TO254P420X460X770-2P | 1
LM1117DT-5.0 | Integrated Circuit | U6 | TO228P991X238-3N | 1
LT1117IST-ADJ | LT1117IST-ADJ | U5 | LT1117IST-ADJ | 1
MOTHERBOARD | 2*5 PIN | J4 | 90131-0126 | 1
PE4312 | Integrated Circuit | U9 | QFN50P400X400X90-21N | 1
PGA-103+ / SPF5189Z | PGA-103+ / SPF5189Z | Q4 | SOT89 | 1
RD07MVS1 | RD07MVS1 | Q1, Q3 | RD07MVS1 | 2
SMAJ5.0A-TR | Diode | D2 | SMBJ36CATR | 1
SN74HC595D | 8-Bit Shift Registers With 3-State Output Registers, D0016A, TUBE | U1, U3, U7 | D0016A_L | 3
SS14 | SS14 | D18, D23 | SS14 | 2
SWR_TANDEM_MATCH | SWR_TANDEM_MATCH | TSWR | SWR_TANDEM_MATCH | 1
TRANSF_OUT | TRANSF_OUT | T4 | TRANSF_OUT | 1
ULN2003BDR | ULN2003BDR | U2 | ULN2003BDR | 1

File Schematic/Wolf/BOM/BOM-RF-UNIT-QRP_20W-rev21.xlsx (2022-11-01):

Comment | Description | Designator | Footprint | Quantity
0 | RES_0805 | R49, R50 | RES_0805 | 2
0 | RES_1206 | R34, R38 | RES_1206 | 2
1:1 | 1:1 | T5 | TRANSF_ACORE2 | 1
1k | RES_0805 | R28, R29, R35, R42, R43 | RES_0805 | 5
1k | RES_0805 | R31, R65, R71, R72, R73, R74, R75, R76, R77, R78, R79, R80, R81, R82, R83, R84, R85 | RESC2013X60X40NL20T25 | 17
1n | CAP_0805 | C47, C48, C72, C112, C115, C120 | CAP_0805 | 6
1n | CAP_0805 | C122 | 6-0805_M | 1
1n8 | CAP_1206 | C105 | CAP_1206 | 1
1n8 100V | CAP_1206 | C92, C94 | CAP_1206 | 2
1N4148 | 1N4148 | D4 | 1N4148 | 1
1uF | CAP_0805 | C126, C128 | CAP_0805 | 2
1uH | IND_0805 | L9, L17 | IND_0805 | 2
1.2k | RES_0805 | R53 | RES_0805 | 1
1.2n | CAP_0805 | C62, C74 | CAP_0805 | 2
1.5n | CAP_0805 | C61 | CAP_0805 | 1
1.5uH | IND_0805 | L14, L18, L25 | IND_0805 | 3
1.8uH | IND_0805 | L19, L26 | IND_0805 | 2
2k | RES_0805 | R13 | RESC2013X60X40NL20T25 | 1
2uH | IND_0805 | L39, L47 | IND_0805 | 2
2.2uF | CAP_1206 | C95 | CAP_1206 | 1
2.2uF 100V | CAP_1206 | C91, C93 | CAP_1206 | 2
2.2uH | IND_0805 | L22, L30, L31 | IND_0805 | 3
2.7uH | IND_0805 | L23, L27 | IND_0805 | 2
3.3n | CAP_0805 | C75, C76 | CAP_0805 | 2
3.3uH | IND_0805 | L28 | IND_0805 | 1
4.7uH | IND_0805 | L24 | IND_0805 | 1
5.6uH | IND_0805 | L29 | IND_0805 | 1
6.5-30p | TZC3P300A110 | C86, C87 | 5025[2010] | 2
6.8uH | IND_0805 | L32 | IND_0805 | 1
8p | CAP_0805 | C16, C19 | CAP_0805 | 2
8T M2000HM 10*6*5 | Transformer | T1 | Rutrof 2 | 1
8T M2000HM 10*6*5 | Transformer | T3 | Rutrof | 1
8.2nH | IND_0805 | L34, L35, L36 | IND_0805 | 3
8.2uH | IND_0805 | L33 | IND_0805 | 1
10k | RES_0805 | R37 | RESC2013X60X40NL20T25 | 1
10k | RES_1206 | R1 | RES_1206 | 1
10n | CAP_0805 | C121 | 6-0805_M | 1
10uF 25V | CAPAE_5.3x5.3h6.1 | C129 | CAPAE_5.3x5.3h6.1 | 1
10uH | Inductor | L37, L38, L43 | IND_FERRITE_CORE | 3
12p | CAP_0805 | C103 | CAP_0805 | 1
15p | CAP_0805 | C18 | CAP_0805 | 1
15pF | CAP_0805 | C17 | CAP_0805 | 1
18 | RES_1206 | R39 | RES_1206 | 1
18p | CAP_1206 | C123, C125 | CAP_1206 | 2
22nH | IND_0805 | L48, L49, L51 | IND_0805 | 3
27nH | IND_0805 | L50 | IND_0805 | 1
27p | CAP_0805 | C55, C104 | CAP_0805 | 2
30k | RES_0805 | R33, R45, R70 | RESC2013X60X40NL20T25 | 3
30k | RES_0805 | R41, R57 | RES_0805 | 2
33p | CAP_0805 | C6 | CAP_0805 | 1
33p | CAP_1206 | C124 | CAP_1206 | 1
39p | CAP_0805 | C7, C101 | CAP_0805 | 2
47p | CAP_0805 | C5, C13, C110 | CAP_0805 | 3
47uF 25V | CAPAE_6.6x6.6h5.4 | C119 | CAPAE_6.6x6.6h5.4 | 1
50 | RES_1206 | R55, R56 | RES_1206 | 2
51p | CAP_0805 | C107 | CAP_0805 | 1
56 | RES_0805 | R27, R44 | RES_0805 | 2
61p | CAP_0805 | C12 | CAP_0805 | 1
68nH | Inductor | L44, L45 | IND_FERRITE_CORE_1 | 2
68p | CAP_0805 | C102, C108 | CAP_0805 | 2
75p | CAP_0805 | C11 | CAP_0805 | 1
82nH | IND_0805 | L2, L41 | IND_0805 | 2
100n | CAP_0805 | C1, C2, C3, C4, C38, C80, C113, C114, C116, C117, C118, C130, C133, C134, C135, C136, C137, C139, C140, C141, C142 | CAP_0805 | 21
100n | CAP_0805 | C131 | 6-0805_M | 1
100n | CAP_1206 | C81, C111 | CAP_1206 | 2
100nH | IND_0805 | L3, L40 | IND_0805 | 2
100p | CAP_0805 | C9, C14, C22, C89 | CAP_0805 | 4
100p | CAP_0805 | C127, C132 | 6-0805_M | 2
110p | CAP_0805 | C8, C10 | CAP_0805 | 2
120p | CAP_0805 | C15, C21, C88, C90 | CAP_0805 | 4
150nH | IND_0805 | L5, L6, L42 | IND_0805 | 3
150p | CAP_0805 | C20 | CAP_0805 | 1
180nH | IND_0805 | L53, L54 | IND_0805 | 2
180p | CAP_0805 | C33, C34 | CAP_0805 | 2
200 | RES_0805 | R52 | RES_0805 | 1
220 | RES_0805 | R32, R46 | RES_0805 | 2
220nH | IND_1206 | L46 | IND_1206 | 1
270nH | IND_0805 | L1, L7 | IND_0805 | 2
270p | CAP_0805 | C24, C32, C45 | CAP_0805 | 3
300 | RES_1206 | R47, R48 | RES_1206 | 2
330nH | IND_0805 | L8, L10, L11, L52, L55 | IND_0805 | 5
330p | CAP_0805 | C23, C44, C46 | CAP_0805 | 3
470nH | IND_0805 | L4, L15 | IND_0805 | 2
470p | CAP_0805 | C36, C60 | CAP_0805 | 2
510 | RES_0805 | R36, R54 | RES_0805 | 2
560 | RES_0805 | R3, R7, R8, R9, R10, R11, R12 | RES_0805 | 7
560nH | IND_0805 | L12, L16 | IND_0805 | 2
560p | CAP_0805 | C35 | CAP_0805 | 1
680nH | IND_0805 | L20 | IND_0805 | 1
680p | CAP_0805 | C59 | CAP_0805 | 1
820nH | IND_0805 | L13, L21 | IND_0805 | 2
820p | CAP_0805 | C58, C73 | CAP_0805 | 2
2027-07-SM-RPLF | 2027-07-SM-RPLF | U18 | 200307SMRPLF | 1
51022-0200 | 51022-0200 | FAN_OUT | 51022-0200 | 1
ADC | SMA | J2 | 31-5431 | 1
ADG904BRUZ-R | Integrated Circuit | U4, U15, U16, U17 | SOP65P640X120-20N | 4
ADG918BRMZ | Integrated Circuit | U8, U10, U11, U12, U13, U14 | SOP65P490X110-8N | 6
ADJ-1k | 306J | R30, R40 | 306J | 2
AFT09MS015NT1 | AFT09MS015NT1 | Q1, Q3 | AFT09MS015NT1 | 2
ANT1 | SMA | J1 | 31-5431 | 1
ANT2 | SMA | J5 | 31-5431 | 1
Axicom V23079 | Axicom V23079 | K1 | V23079 | 1
BAT46JFILM | Diode | D1, D3 | SOD2513X117N | 2
BAV99 | BAV99 | D24 | SOT23 | 1
BSS123 | N-Channel Logic Level Enhancement Mode Field Effect Transistor, 1.7 V, -55 to 150 degC, 3-Pin SOT-23, RoHS, Tape and Reel | Q6, Q7, Q8 | FAIR-SOT23-3_V | 3
DAC | SMA | J9 | 31-5431 | 1
EXTERNAL | 2*5 PIN | J3 | 90131-0126 | 1
IRLML9301 | MOSFET | Q2, Q5 | SOT23 | 2
JX2 | JX2 | J8 | 1986717-2 | 1
KTY81/120 | Integrated Circuit | R14 | TO254P420X460X770-2P | 1
LM1117DT-5.0 | Integrated Circuit | U6 | TO228P991X238-3N | 1
LT1117IST-ADJ | LT1117IST-ADJ | U5 | LT1117IST-ADJ | 1
MOTHERBOARD | 2*5 PIN | J4 | 90131-0126 | 1
PE4312 | Integrated Circuit | U9 | QFN50P400X400X90-21N | 1
PGA-103+ / SPF5189Z | PGA-103+ / SPF5189Z | Q4 | SOT89 | 1
SMAJ5.0A-TR | Diode | D2 | SMBJ36CATR | 1
SN74HC595D | 8-Bit Shift Registers With 3-State Output Registers, D0016A, TUBE | U1, U3, U7 | D0016A_L | 3
SS14 | SS14 | D18, D23 | SS14 | 2
SWR_TANDEM_MATCH | SWR_TANDEM_MATCH | TSWR | SWR_TANDEM_MATCH | 1
TRANSF_OUT | TRANSF_OUT | T4 | TRANSF_OUT | 1
ULN2003BDR | ULN2003BDR | U2 | ULN2003BDR | 1

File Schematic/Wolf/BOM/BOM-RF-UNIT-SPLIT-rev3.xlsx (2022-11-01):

Comment | Description | Designator | Footprint | Quantity
1k | RES_0805 | R31, R33, R57, R69, R70, R71, R72 | RESC2013X60X40NL20T25 | 7
1k | RES_0805 | R35 | RES_0805 | 1
1n | CAP_0805 | C112, C120 | CAP_0805 | 2
1n | CAP_0805 | C122 | 6-0805_M | 1
1N4148 | 1N4148 | D1, D4, D5, D8, D31 | SS14 | 5
2k | RES_0805 | R13 | RES_0805 | 1
10k | RES_1206 | R73 | RES_1206 | 1
10n | CAP_0805 | C121 | 6-0805_M | 1
10uF 25V | CAPAE_5.3x5.3h6.1 | C129 | CAPAE_5.3x5.3h6.1 | 1
18 | RES_1206 | R39 | RES_1206 | 1
30k | RES_0805 | R48, R75 | RES_0805 | 2
100n | CAP_0805 | C1, C107, C108, C109, C110, C130, C133, C134, C135 | CAP_0805 | 9
100n | CAP_0805 | C131 | 6-0805_M | 1
100p | CAP_0805 | C127, C132 | 6-0805_M | 2
220nH | IND_1206 | L46 | IND_1206 | 1
560 | RES_0805 | R3, R7, R8, R9, R10, R11, R12 | RES_0805 | 7
51022-0200 | 51022-0200 | FAN_OUT | 51022-0200 | 1
ADC | SMA | J2 | 31-5431 | 1
ADG918BRMZ | Integrated Circuit | U8, U10 | SOP65P490X110-8N | 2
ANT1 | SMA | J1 | 31-5431 | 1
ANT2 | SMA | J5 | 31-5431 | 1
Axicom IM06 | Axicom IM06 | U4, U12 | IM06GR | 2
BAV99 | BAV99 | D7 | SOT23 | 1
BPF_IN | SMA | J16 | 31-5431 | 1
BPF_OUT | SMA | J18 | 31-5431 | 1
BSS123 | N-Channel Logic Level Enhancement Mode Field Effect Transistor, 1.7 V, -55 to 150 degC, 3-Pin SOT-23, RoHS, Tape and Reel | Q12 | FAIR-SOT23-3_V | 1
DAC | SMA | J9 | 31-5431 | 1
EXTERNAL | 2*5 PIN | J3 | 90131-0126 | 1
G6S-2-DC12 | Relay or Contactor | K1, K2, K3 | G6S2DC12 | 3
HF_AMP_IN | SMA | J7 | 31-5431 | 1
HF_LPF_OUT | SMA | J10 | 31-5431 | 1
IRLML9301 | MOSFET | Q11 | SOT23 | 1
KTY81/120 | Integrated Circuit | R14 | TO254P420X460X770-2P | 1
LM1117DT-5.0 | Integrated Circuit | U6 | TO228P991X238-3N | 1
MOTHERBOARD | 2*5 PIN | J4 | 90131-0126 | 1
OUT_AMPS | 2*5 PIN | J11 | 90131-0126 | 1
OUT_BPF | 2*5 PIN | J14 | 90131-0126 | 1
OUT_EXT | 2*5 PIN | J20 | 90131-0126 | 1
OUT_LPF | 2*5 PIN | J15 | 90131-0126 | 1
OUT_TUNER_C | 2*5 PIN | J13 | 90131-0126 | 1
OUT_TUNER_I | 2*5 PIN | J12 | 90131-0126 | 1
PE4312 | Integrated Circuit | U9 | QFN50P400X400X90-21N | 1
PGA-103+ / SPF5189Z | PGA-103+ / SPF5189Z | Q4 | SOT89 | 1
SMAJ5.0A-TR | Diode | D2 | SMBJ36CATR | 1
STPIC6C595TTR | Integrated Circuit | U1, U2, U3, U5, U7, U11 | SOP65P640X120-16N | 6
TUNER_IN | SMA | J17 | 31-5431 | 1
TUNER_OUT | SMA | J19 | 31-5431 | 1
VHF_AMP_IN | SMA | J6 | 31-5431 | 1
VHF_LPF_OUT | SMA | J8 | 31-5431 | 1

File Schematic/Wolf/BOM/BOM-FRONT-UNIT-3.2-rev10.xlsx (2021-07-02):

Comment | Description | Designator | Footprint | Quantity
0 | RES_0805 | R23, R24, R25 | RES_0805 | 3
1n | CAP_1206 | C5 | CAP_1206 | 1
1n4148w | Diode | D25, D27 | SOD3716X135N | 2
1uF | CAP_1206 | C3 | CAP_1206 | 1
3.3k | RES_0805 | R20, R21, R22 | RES_0805 | 3
4.7k | RES_0805 | R3, R4, R5, R6, R7, R8, R9, R10, R11, R12, R13, R14, R15, R16, R17, R18, R19, R29, R30, R31, R32, R33, R34, R35, R36 | RES_0805 | 25
8.2n | CAP_1206 | C11 | CAPC2013X94X50LL20T25 | 1
10n | CAP_0805 | C12, C13 | CAP_0805 | 2
22uF 10V | EEEFC_sizeB | C10 | EEEFC_sizeB | 1
30k | RES_0805 | R26, R27, R28 | RESC2013X60X40NL20T25 | 3
100n | CAP_0805 | C1, C2, C9 | CAP_0805 | 3
100n | CAP_1206 | C4 | CAP_1206 | 1
120p | CAP_1206 | C8 | CAP_1206 | 1
470p | CAP_1206 | C7 | CAP_1206 | 1
1000uF | CAP250RP | C6 | CAP250RP | 1
BNX016-01 | BNX016-01 | T1 | TRANSF_ICORE | 1
BSS123 | N-Channel Logic Level Enhancement Mode Field Effect Transistor, 1.7 V, -55 to 150 degC, 3-Pin SOT-23, RoHS, Tape and Reel | Q2 | FAIR-SOT23-3_V | 1
DM3AT-SF-PEJM5 | Connector | J2 | DM3ATSFPEJM5 | 1
ESP-01 ESP8266 | ESP-01 ESP8266 | ESP-8266 | ESP-01 ESP8266 | 1
FPC-45P-0.5mm | Connector | J7 | FH12S45S05SH60 | 1
ILI9481 480*320 3'2 | LCD-MODULE_3'2_480х320 | LCD-MODULE | LCD-MODULE-3.2-480-320 | 1
IRFR9024NPBF | IRFR9024NPBF, Транзистор, Р-канал 55В 11А | Q1 | ONSC-DPAK-3-369C-01_V | 1
JX2 | JX2 | ACCUM, IN, MOTHERBOARD, RF-UNIT | JX2 | 4
MCP3008-I/SL | MCP3008-I/SL | U1, U2, U3 | MCP3008-I/SL | 3
MF-MSMF110_16-2 | Fuse | F2 | FUSC4632X85N | 1
OPTICAL ENCODER | OPTICAL ENCODER | ENCODER_MAIN | 644456-4 | 1
PEC12 | PEC12 | ENC2 | PEC12 | 1
PJ-050B | PJ-050B | IN_2 | PJ-050B | 1
PTS645SK50LFS | PTS645SK50LFS | S1, S2, S3, S4, S5, S6, S7, S8, S9, S10, S11, S12, S13, S14, S15, S16, S17, S18, S19, S20, S21, S22, S23 | PTS645SK50LFS | 23
ptv09a-4225f-b102 | Adjustable Resistor PTV09 | R1, R2 | PTV09 | 2
RUEF400 | Fuse | F1 | RUEF400 | 1
SM6T15A | Diode | D28 | SMBJ36CATR | 1

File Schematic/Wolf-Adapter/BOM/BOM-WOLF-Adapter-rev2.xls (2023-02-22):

Comment | Description | Designator | Footprint | Quantity
"1.2Ghz" | RF | J8 | CON: SMA | 1
"5.6Ghz" | RF | J9 | CON: SMA | 1
"10Ghz" | RF | J10 | CON: SMA | 1
"144Mhz" | RF | J6 | CON: SMA | 1
"430Mhz" | RF | J7 | CON: SMA | 1
"OUTPUTS_1" |  | J3 | CON: PLD-10 | 1
"OUTPUTS_2" |  | J4 | CON: PLD-10 | 1
"PTT" |  | J5 | CON: PLD-10 | 1
"PTT" |  | X1 | CON: PLS-5 | 1
"TRX" |  | J1 | CON: PLD-10 | 1
"TRX_VHF" | RF | J2 | CON: SMA | 1
0.1u |  | C2, C4 | CH0805C | 2
1k |  | R1, R2, R3, R4 | CH0805R | 4
1N4148 |  | VD1, VD2, VD3, VD4, VD5, VD6, VD7, VD8, VD9, VD10, VD11, VD12, VD13, VD14, VD15, VD16, VD17, VD18, VD19, VD20 | 1N4148 | 20
10k |  | R6 | CH0805R | 1
10uF |  | C1, C3 | TANTAL_B | 2
30k |  | R5 | CH0805R | 1
74HC4514D |  | IC1 | 24-SOIC (W) | 1
100n |  | C5, C6, C7, C8, C9, C10, C11, C12, C13, C14 | CH0805C | 10
BSS123 |  | VT2 | SOT23_132 | 1
G6S-2-D?12 |  | K1, K2, K3, K4, K5, K6, K7, K8, K9, K10 | G6S-2-DC12 | 10
IRLML9301 |  | VT1 | SOT23_132 | 1
LM1117DT-5-5.0 |  | U1 | SOT223 | 1
ULN2803AFWG |  | IC2, IC3 | 18-SOIC (W) | 2

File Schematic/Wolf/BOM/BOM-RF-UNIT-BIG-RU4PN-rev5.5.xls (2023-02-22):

ID | Name | Designator | Footprint | Quantity | Manufacturer Part | Manufacturer | Supplier | Supplier Part | Price
1 | 100n | C1,C7,C8,C9,C10,C11,C16,C21,C26,C31,C36,C38,C42,C47,C48,C49,C50,C59,C64,C67,C71,C76,C78,C80,C82,C89,C90,C113,C114,C116,C117,C118,C130,C131,C136,C137,C138,C139,C167,C170,C171,C241,C301,C302,C303,C304 | C0805 | 46
2 | 470pF | C2 | C1206 | 1
3 | 30pF | C3 | C1206 | 1
4 | 36pF | C4 | C1206 | 1
5 | 47pF | C5,C86 | C1206 | 2
6 | 22pF | C6,C85 | C1206 | 2
7 | 27pF | C12,C15 | C1210 | 2
8 | 20pF | C13 | C1210 | 1
9 | 100pF | C14,C17,C19,C20 | C1210 | 4
10 | 120pF | C18 | C1210 | 1
11 | 150pF | C22,C23,C25,C28 | C1210 | 4
12 | 220pF | C24,C27,C30 | C1210 | 3
13 | 330pF | C29 | C1210 | 1
14 | 470pF | C32,C33,C34,C35 | C1210 | 4
15 | 470+330pF | C37,C41 | C1210 | 2
16 | 1000pF | C39,C45 | C1210 | 2
17 | 560pF | C40 | C1210 | 1
18 | 1000+220pF | C43,C46 | C1210 | 2
19 | 1000+470pF | C44 | C1210 | 1
20 | 3n3 | C51,C125,C134,C135 | C0805 | 4
21 | 68pF 500V | C52,C56 | C1206 | 2
22 | 4.7n* | C53,C54 | C1206 | 2
23 | 27pF | C55 | C0805 | 1
24 | 470p 500V | C57 | C1206 | 1
25 | 100n | C58,C61,C106 | C1206 | 3
26 | 200p 500V | C60 | C1206 | 1
27 | 1uF | C62,C63,C79,C83,C126 | C0805 | 5
28 | 30pF* | C65,C66 | CAP-ADJ-SMD_L4.5-W3.2-L | 2 | TZC3P300A110R00 | Murata Electronics | LCSC | C107707
29 | 82pF | C68,C73,C388,C390 | C0805 | 4
30 | 10n | C69,C107,C108,C109,C110,C121,C123,C124,C133,C141,C142,C143,C144,C145,C146,C147,C148,C149,C150,C151,C152,C153,C154,C157,C158,C159,C160,C161,C162,C163,C164,C165,C166 | C0805 | 33
31 | 4.7n | C70,C75 | C0805 | 2
32 | 75pF | C72,C311,C389 | C0805 | 3
33 | 22uF | C74,C77 | CASE-B_3528 | 2
34 | 15n | C81,C111 | C1206 | 2
35 | 10pF | C84 | C1206 | 1
36 | 100pF | C87,C91,C93,C103 | C1206 | 4
37 | 220pF | C88 | C1206 | 1
38 | 10n | C92,C102 | C1206 | 2
39 | 1n | C94,C104 | C1206 | 2
40 | 2.2uF | C95 | C1206 | 1
41 | * | C96,C97,C98,C99,C100 | CAP-TH_L8.0-W4.0-P7.50-D0.6 | 5 | CC45SL3AD101JYSNA | TDK | LCSC | C2835349 | 0.006
42 | 200pF | C101 | C1206 | 1
43 | 1n8 | C105 | C1206 | 1
44 | 100p | C112,C127,C132 | C0805 | 3
45 | 1n | C115,C122,C347,C348,C372 | C0805 | 5
46 | 47uF | C119 | CASE-B_3528 | 1
47 | 68p | C120,C202,C208 | C0805 | 3
48 | 1uF | C128 | C1206 | 1
49 | 10uF 25V | C129 | CAP-D4.0×H5.5 | 1
50 | 39p | C201 | C0805 | 1
51 | 12p | C203 | C0805 | 1
52 | 27p | C204 | C0805 | 1
53 | 51p | C207 | C0805 | 1
54 | 47p | C210 | C0805 | 1
55 | 47pF | C305,C313 | C0805 | 2
56 | 33pF | C306 | C0805 | 1
57 | 39pF | C307 | C0805 | 1
58 | 110pF | C310 | C0805 | 1
59 | 61pF | C312 | C0805 | 1
60 | 100pF | C314,C322 | C0805 | 2
61 | 120pF | C315,C321 | C0805 | 2
62 | 15pF | C317 | C0805 | 1
63 | 8pF | C319 | C0805 | 1
64 | 150pF | C320 | C0805 | 1
65 | 330pF | C323,C344,C346 | C0805 | 3
66 | 270pF | C324,C332,C345 | C0805 | 3
67 | 180pF | C333,C334 | C0805 | 2
68 | 560pF | C335 | C0805 | 1
69 | 470pF | C336,C360 | C0805 | 2
70 | 820pF | C358,C373 | C0805 | 2
71 | 680pF | C359 | C0805 | 1
72 | 1.5n | C361 | C0805 | 1
73 | 1.2n | C362,C374 | C0805 | 2
74 | 3.3n | C375,C376 | C0805 | 2
75 | 30pF * | C386,C387 | CAP-ADJ-SMD_L4.5-W3.2-L | 2 | TZC3P300A110R00 | Murata Electronics | LCSC | C107707
76 | BAT46JFILM | D1,D3,D49,D50 | SOD-323_L1.8-W1.3-LS2.5-RD | 4 | BAT46JFILM | STMicroelectronics | LCSC | C111205
77 | SMAJ5.0A-TR | D2 | SMA_L4.3-W2.6-LS5.2-RD | 1 | SMAJ5.0A-TR | STMicroelectronics | LCSC | C98802 | 0.037
78 | 1N4148W | D4,D5,D8,D9,D13,D15,D17,D20,D22,D25,D27,D31,D32,D38,D39,D40,D41,D42,D43,D44,D45,D46,D47,D48,D51 | SOD-123FL_L2.6-W1.6-LS3.4-RD | 25 | 1N4148W | Tak Cheong | LCSC | C129216 | 0.003
79 | CDSOD323-T05C | D6,D10,D11,D12 | SOD-323_L1.8-W1.3-LS2.5-BI | 4 | CDSOD323-T05C | BOURNS | LCSC | C711706 | 0.048
80 | BAV99 | D7 | SOT-23-3_L2.9-W1.3-P1.90-LS2.4-BR | 1 | BAV99-7-F | DIODES | LCSC | C106919 | 0.005
81 | SS14 | D18,D23 | SS14 | 2 | SS14 | MDD | LCSC | C2480 | 0.002
82 | SS14 | D35,D36,D37 | SMA_L4.4-W2.8-LS5.4-RD | 3 | SS14 | MDD | LCSC | C2480 | 0.002
83 | BLM21 | FB1,FB2 | L0806 | 2
84 | BLM21 | FB4,FB5 | L0805 | 2 | BLM21PG300SN1D | MuRata | LCSC | C16903 | 0.004
85 | FAN_OUT | H1 | HDR-F-2.54_1X2 | 1 |  |  | LCSC | C49661 | 0.006
86 | ANT1 | J1 | SMA-TH_BWSMA-KE-Z001 | 1 | SMA-KE-P901 | DreamLNK | LCSC | C914556 | 0.109
87 | ADC | J2,J10 | SMA-TH_BWSMA-KE-Z001 | 2 | SMA-KE-P901 | DreamLNK | LCSC | C914556 | 0.109
88 | EXTERNAL | J3 | IDC-10 | 1
89 | MOTHERBOARD | J4 | IDC-10 | 1
90 | ANT2 | J5 | SMA-TH_BWSMA-KE-Z001 | 1 | SMA-KE-P901 | DreamLNK | LCSC | C914556 | 0.109
91 | HiCurrent 13.8V | J6 | CONN-TH_TY500-5.08-02P-14-00AH | 1 | TY500-5.08-02P-14-00AH | Toponelec(拓宜) | LCSC | C2828268 | 0.032
92 | HiCurrent13.8V | J7 | CONN-TH_TY500-5.08-02P-14-00AH | 1 | TY500-5.08-02P-14-00AH | Toponelec(拓宜) | LCSC | C2828268 | 0.032
93 | 13.8V | J8 | CONN-TH_TY500-5.08-02P-14-00AH | 1 | TY500-5.08-02P-14-00AH | Toponelec(拓宜) | LCSC | C2828268 | 0.032
94 | DAC | J9 | SMA-TH_BWSMA-KE-Z001 | 1 | SMA-KE-P901 | DreamLNK | LCSC | C914556 | 0.109
95 | G6S-2-12V | K1,K2,K8,K9,K10,K11,K12,K13,K14,K15,K16,K17,K18,K19,K20,K21,K24,K25,K26,K27,K28,K29,K30,K31,K32,K33,K34,K35 | RELAY-TH_G6S-2-X | 28 | G6S-2-12V | OMRON | LCSC | C28410 | 0.145
96 | axicom im06c | K4,U4,U12 | IM06C | 3 | axicom im06c |  | axicom
97 | G6K-2F-5V | K50 | RELAY-TH_G6K-2F-Y | 1 | 0 | Omron Electronics | LCSC | C231389 | 0.201
98 | 0,047uH | L1 | BEAD-TH_BD3.5-L4.7-P8.70-D0.7 | 1 | BL02RN2R1M2 | China |  | C84974
99 | 0.047uH | L2,L3 | BEAD-TH_BD3.5-L4.7-P8.70-D0.7 | 2 | BL02RN2R1M2 | China |  | C84974
100 | 0.065uH | L7,L8 | BEAD-TH_BD3.5-L4.7-P8.70-D0.7 | 2 | BL02RN2R1M2 | China |  | C84974
101 | 0.29uH | L10,L11 | BEAD-TH_BD3.5-L4.7-P8.70-D0.7 | 2 | BL02RN2R1M2 | China |  | C84974
102 | 0.4uH | L13,L14 | BEAD-TH_BD3.5-L4.7-P8.70-D0.7 | 2 | BL02RN2R1M2 | China |  | C84974
103 | 0.6uH | L16,L17 | BEAD-TH_BD3.5-L4.7-P8.70-D0.7 | 2 | BL02RN2R1M2 | China |  | C84974
104 | 1.15uH | L19,L20 | BEAD-TH_BD3.5-L4.7-P8.70-D0.7 | 2 | BL02RN2R1M2 | China |  | C84974
105 | 2.3uH | L22,L23 | BEAD-TH_BD3.5-L4.7-P8.70-D0.7 | 2 | BL02RN2R1M2 | China |  | C84974
106 | 4.5uH | L25,L26 | BEAD-TH_BD3.5-L4.7-P8.70-D0.7 | 2 | BL02RN2R1M2 | China |  | C84974
107 | 10u 10x10 | L30,L43 | B82464Z4 | 2
108 | 0.22u | L31 | L1206 | 1
109 | 0.0082u | L32,L33,L34 | L0805 | 3
110 | 0.1uH | L35 | BEAD-TH_BD3.5-L4.7-P8.70-D0.7 | 1 | BL02RN2R1M2 | China |  | C84974
111 | 0.22uH | L36 | BEAD-TH_BD3.5-L4.7-P8.70-D0.7 | 1 | BL02RN2R1M2 | China |  | C84974
112 | 0.45uH | L39 | BEAD-TH_BD3.5-L4.7-P8.70-D0.7 | 1 | BL02RN2R1M2 | China |  | C84974
113 | 1.0uH | L41 | BEAD-TH_BD3.5-L4.7-P8.70-D0.7 | 1 | BL02RN2R1M2 | China |  | C84974
114 | 2.2uH | L42 | BEAD-TH_BD3.5-L4.7-P8.70-D0.7 | 1 | BL02RN2R1M2 | China |  | C84974
115 | 0.22u | L46 | L0805 | 1
116 | 0.022u | L48 | L0805 | 1
117 | 0.0082u | L134,L135,L136 | L0805-WOLF | 3 | L0805C100MDWIT | KEMET | LCSC | C696787 | 0.037
118 | 0.1u | L140 | L0805-WOLF | 1
119 | 0.082u | L141 | L0805-WOLF | 1
120 | 0.15u | L142 | L0805-WOLF | 1
121 | 0.022u | L151 | L0805-WOLF | 1 | L0805C100MDWIT | KEMET | LCSC | C696787 | 0.037
122 | 0.18u | L153 | L0805-WOLF | 1 | L0805C100MDWIT | KEMET | LCSC | C696787 | 0.037
123 | 0.33u | L155,L308,L310,L311 | L0805-WOLF | 4 | L0805C100MDWIT | KEMET | LCSC | C696787 | 0.037
124 | 0.27u | L301,L307 | L0805-WOLF | 2 | L0805C100MDWIT | KEMET | LCSC | C696787 | 0.037
125 | 0.082u | L302 | L0805-WOLF | 1 | L0805C100MDWIT | KEMET | LCSC | C696787 | 0.037
126 | 0.1u | L303 | L0805-WOLF | 1 | L0805C100MDWIT | KEMET | LCSC | C696787 | 0.037
127 | 0.47u | L304,L315 | L0805-WOLF | 2 | L0805C100MDWIT | KEMET | LCSC | C696787 | 0.037
128 | 0.15u | L305,L306 | L0805-WOLF | 2 | L0805C100MDWIT | KEMET | LCSC | C696787 | 0.037
129 | 1u | L309,L317 | L0805-WOLF | 2 | L0805C100MDWIT | KEMET | LCSC | C696787 | 0.037
130 | 0.56u | L312,L316 | L0805-WOLF | 2 | L0805C100MDWIT | KEMET | LCSC | C696787 | 0.037
131 | 0.82u | L313,L321 | L0805-WOLF | 2 | L0805C100MDWIT | KEMET | LCSC | C696787 | 0.037
132 | 1.5u | L314,L318,L325 | L0805-WOLF | 3 | L0805C100MDWIT | KEMET | LCSC | C696787 | 0.037
133 | 1.8u | L319,L326 | L0805-WOLF | 2 | L0805C100MDWIT | KEMET | LCSC | C696787 | 0.037
134 | 0.68u | L320 | L0805-WOLF | 1 | L0805C100MDWIT | KEMET | LCSC | C696787 | 0.037
135 | 2.2u | L322,L330,L331 | L0805-WOLF | 3 | L0805C100MDWIT | KEMET | LCSC | C696787 | 0.037
136 | 2.7u | L323,L327 | L0805-WOLF | 2 | L0805C100MDWIT | KEMET | LCSC | C696787 | 0.037
137 | 4.7u | L324 | L0805-WOLF | 1 | L0805C100MDWIT | KEMET | LCSC | C696787 | 0.037
138 | 3.3u | L328 | L0805-WOLF | 1 | L0805C100MDWIT | KEMET | LCSC | C696787 | 0.037
139 | 5.6u | L329 | L0805-WOLF | 1 | L0805C100MDWIT | KEMET | LCSC | C696787 | 0.037
140 | 6.8u | L332 | L0805-WOLF | 1 | L0805C100MDWIT | KEMET | LCSC | C696787 | 0.037
141 | 8.2u | L333 | L0805-WOLF | 1 | L0805C100MDWIT | KEMET | LCSC | C696787 | 0.037
142 | RD16HHF1 | Q1,Q3 | TO220V | 2
143 | IRLML9301 | Q2,Q7,Q10 | SOT-23-3_L2.9-W1.3-P1.90-LS2.4-BR | 3 | IRLML9301TR | VBsemi Elec | LCSC | C710004 | 0.018
144 | PGA103+/SPF5189Z | Q4 | SOT-89-3_L4.5-W2.5-P1.50-LS4.2-TL | 1
145 | RD100HHF1 | Q5,Q6 | RD100HHF WOLF | 2
146 | RA80H1415M1 | Q8 | RA80H1415M1 | 1 | RA80H1415M1
147 | RD01MUS1 | Q9 | RD01MUS1 | 1
148 | IRLML9301 | Q11 | SOT-23_L2.9-W1.3-P1.90-LS2.4-BR | 1 | IRLML9301TRPBF | IR | LCSC | C82056 | 0.051
149 | BSS123 | Q12 | SOT-23-3_L2.9-W1.6-P1.90-LS2.8-BR | 1 | BSS123 | CJ | LCSC | C79015 | 0.005
150 | A022-145M2 | QF1 | A022-145M2 | 1
151 | 47 | R1,R2,R17,R18 | R1206_1 | 4 | 0 | Chian Chia Elec | LCSC | C122207 | 0.012
152 | 560 | R3,R7,R8,R9,R10,R11,R12,R62,R63 | R0805 | 9
153 | 30k | R4,R41,R45,R48,R75 | R0805 | 5
154 | 1k | R5,R6,R31,R33,R35,R42,R43,R57,R69,R70,R71,R72,R79,R80,R81,R201,R202,R203,R204,R205,R206,R207 | R0805 | 22
155 | 2k | R13 | R0805 | 1
156 | KTY81/120 | R14 | RES-TH_KTY81 | 1 | KTY81/110,112 | NXP(恩智浦) | LCSC | C1527155 | 0.201
157 | 56 | R15,R16,R26 | R0805 | 3
158 | 0 | R17*,R49,R50,R65,R67 | R1206 | 5
159 | * | R18* | R1206 | 1
160 | 10K | R19,R20 | RES-ADJ-TH_3296W | 2 | 3296W-1-102LF | BOURNS | LCSC | C57089 | 0.12
161 | 750 | R21 | R0805 | 1
162 | 470 | R22 | R0805 | 1
163 | 20 | R23 | R0805 | 1
164 | 300 | R24,R25 | R0805 | 2
165 | 47 | R27,R44 | R0805 | 2
166 | 100 | R28,R29,R51 | R0805 | 3
167 | 1K | R30,R40,R46 | RES-ADJ-TH_3296W | 3 | 3296W-1-102LF | BOURNS | LCSC | C57089 | 0.12
168 | 6.8k | R32 | R0805 | 1
169 | 100 | R34 | R1206 | 1
170 | 510 | R36,R54 | R1206 | 2
171 | 2.7k | R37 | R0805 | 1
172 | 4.7 | R38,R47,R74,R76 | R1206 | 4
173 | 18 | R39 | R1206 | 1
174 | 200 | R52 | R0805 | 1
175 | 1.2k | R53 | R0805 | 1
176 | 50 | R55,R56 | R1206 | 2
177 | 620 | R58 | R0805 | 1
178 | 430 | R59,R60 | R1206 | 2
179 | 10 | R61 | R0805 | 1
180 | 1K | R64,R68 | R1206 | 2
181 | 100 | R66 | RES-ADJ-TH_3362P | 1 | 3362P-1-105 | ReliaPro | LCSC | C20063
182 | 10k | R73 | R1206 | 1
183 | 2.2k | R77,R78 | R0805 | 2
184 | BN61-002 | T1 | BN61-002 WOLF | 1 | BN61-002
185 | BN43-202 | T2 | BN43-202 WOLF SHORT | 1
186 | BN43-202 | T3 | BN43-202_RD16 WOLF | 1
187 | 1:1 | T5 | ATD1+TC1 | 1 | TC1-1T+ | Mini-Circuits | LCSC | C879831 | 0.44
188 | VHF Tandem Meter | T6 | VHF SWR METER | 1 | VHF Tandem Meter
189 | BN-61-202 | TSWR | BN43-202_TANDEM | 1 | 2843010302 | Fair-Rite |  | 2843010302
190 | STPIC6C595TTR | U1,U2,U3,U7,U11,U21 | TSSOP-16_L5.0-W4.4-P0.65-LS6.4-BL | 6 | STPIC6C595TTR | STMicroelectronics | LCSC | C222081 | 0.391
191 | LT1117-ADJ | U5,U20 | SOT-223-3_L6.5-W3.4-P2.30-LS7.0-BR | 2 | LT1117IST#PBF | Analog Devices | LCSC | C661269 | 0.689
192 | LM1117DT-5.0 | U6 | TD03B | 1
193 | PE4302 | U9 | QFN-20L_L4.0-W4.0-P0.50-BL-EP2.0 | 1 | PE4302-EK | null | LCSC | C2763949
194 | ADG918BRMZ | U13,U14 | MSOP-8_L3.0-W3.0-P0.65-LS4.9-BL | 2 | ADG918BRMZ-500RL7 | Analog Devices | LCSC | C207406 | 0.452
195 | LT1117IST-5.0 | U19 | SOT-223-3_L6.5-W3.4-P2.30-LS7.0-BR | 1 | LT1117IST-5#TRPBF | Analog Devices | LCSC | C661276 | 1.412
196 | ADG904BRUZ | U24,U25,U26,U27 | TSSOP-20 | 4

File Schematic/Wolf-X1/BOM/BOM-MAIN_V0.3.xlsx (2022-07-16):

Посадочное место | Номинал | Количество | Footprint
MicroSD1 | DM3AT-SF-PEJM5 | 1 | Micro SD - M
B1 батарейка | CR1220 | 1 | CR1220
C1 | 7.5p | 1 | CH0603C
C2, C3 | 22p | 2 | CH0603C
C4, C7, C30, C33, C38, C39, C40, C44, C45, C46, C47, C62, C63, C64, C66, C118, C154, C176, C177, C181, C182, C184, C190, C193 | 0.1u | 24 | CH0603C
C5, C6 | 2u2 | 2 | CH0603C
C8, C37, C85, C155, C157, C164 | 10u | 6 | CH0603C
C9, C10 | 6p | 2 | CH0603C
C11, C12, C13, C14, C15, C16, C17, C18, C19, C20, C21, C22, C23, C24, C25, C26, C27, C28, C29, C54, C55, C56, C67, C76, C79, C80, C82, C83, C84, C86, C88, C89, C90, C91, C92, C93, C94, C95, C96, C97, C98, C101, C102, C103, C105, C108, C110, C112, C114, C115, C116, C117, C120, C122, C123, C124, C125, C126, C127, C128, C129, C130, C131, C132, C133, C183, C187, C207, C208 | 0.1 | 69 | CH0603C
C31, C32, C178, C179, C180 | 10uF10V | 5 | TANTAL_A
C34, C36, C41, C42, C73, C74, C191, C195, C198 | 1u | 9 | CH0603C
C35, C77, C185, C189 | 470p | 4 | CH0603C
C43 | 10p | 1 | CH0603C
C48, C49, C99 | 1n | 3 | CH0603C
C50, C51, C52 | 1uF | 3 | CH0603C
C53, C57, C58 | 220uF | 3 | POLIMER-E
C59, C60, C61, C65 | 10uF10V | 4 | TANTAL_A
C68, C70, C71 | 1uF 10V | 3 | TANTAL_A
C69, C78 | 10n | 2 | CH0603C
C72, C140, C148 | 220p | 3 | CH0603C
C75 | 10uF 10V | 1 | TANTAL_A
C81, C111 | 8.2n | 2 | CH0603C
C87, C221 | 8p | 2 | CH0603C
C100, C107 | 10uF 10V | 2 | TANTAL_B
C104, C137, C153, C220 | 110p | 4 | CH0603C
C106, C212 | 15p | 2 | CH0603C
C109 | 4.7uF 47V | 1 | POLIMER-E
C113 | 22uF 10V | 1 | POLIMER-E
C119, C204 | 120p | 2 | CH0603C
C121, C145, C201, C211 | 100p | 4 | CH0603C
C134, C138, C142, C146, C150 | 180p | 5 | CH0603C
C135, C151 | 51p | 2 | CH0603C
C136, C152 | 390p | 2 | CH0603C
C139, C147 | 43p | 2 | CH0603C
C141, C149 | 91p | 2 | CH0603C
C143, C199 | 47p | 2 | CH0603C
C144 | 330p | 1 | CH0603C
C156, C165, C172, C202 | 33p | 4 | CH0603C
C158, C174 | 39p | 2 | CH0603C
C159, C168 | 20p | 2 | CH0603C
C160, C162, C166, C214 | 22uf | 4 | CH1206C
C161, C170 | 24p | 2 | CH0603C
C163 | 27p | 1 | CH0603C
C167, C169, C171 | 4.7uF | 3 | TANTAL_A
C173, C175, C192, C194 | 6.8n | 4 | CH0603C
C186 | 10n/none | 1 | CH0603C
C188 | 2.7n | 1 | CH0603C
C196, C197 | 680p | 2 | CH0603C
C200, C203 | 6.5-30pF | 2 | C_trimer
FB1, FB2, FB3 | Ferrite_Bead | 3 | CH0805L
FB4, FB5, L2 | BLM21 | 3 | CH0805L
J1 | BOOT | 1 | CON: PLS-2
J2, J4, J5 | PJ-307 | 3 | PJ-307
L1 | 22uH | 1 | 4020
L3, L44 | 330nH | 2 | L1210
L4, L43 | 22nH | 2 | L1210
L5 | 3.3uH | 1 | IND: CDRH74
L6 | 10uH | 1 | IND: CDRH74
L7, L11, L15 | 6.2uH | 3 | L1210
L8, L12, L16 | 2.2uH | 3 | L1210
L9, L13, L17 | 12uH | 3 | L1210
L10, L14, L18 | 3.3uH | 3 | L1210
L19, L24, L28 | 0.68uH | 3 | L1210
L20, L22, L23, L37 | 2.2uH | 4 | 4020
L21, L26, L30 | 1.2uH | 3 | L1210
L31 | 270nH | 1 | L1210
L32, L34, L36 | 8.2nH | 3 | L1210
L33 | 82nH | 1 | L1210
L35 | 100nH | 1 | L1210
L40, L42 | 180nH | 2 | L1210
L41 | 27nH | 1 | L1210
R1, R2, R3, R7, R11, R13, R14, R15, R16, R23, R24, R25, R33, R42, R65, R70, R73, R87, R88 | 10k | 19 | CH0603R
R4, R48 | 11k | 2 | CH0603R
R5, R6, R9, R51, R75, R77 | 22 | 6 | CH0603R
R8, R27, R28 | 3.3К | 3 | CH0603R
R10, R12, R32, R66, R67, R68, R69, R71, R74 | 1k | 9 | CH0603R
R17 | 1.5k | 1 | CH0603R
R18, R78 | 56 | 2 | CH0603R
R19, R20 | 10 | 2 | CH0603R
R21, R22, R54, R80, R81 | 100 | 5 | CH0603R
R26 | 680 | 1 | CH0603R
R29, R30, R31, R36, R55, R56 | 47K | 6 | CH0603R
R34, R35 | none | 2 | CH0603R
R37 | 5.6k | 1 | CH0603R
R38, R39 | 82 | 2 | CH0603R
R40, R41 | 130 | 2 | CH0603R
R43 | 120k +100k parallel | 1 | CH0603R
R44, R45, R46 | 30k | 3 | CH0603R
R47, R49 | 2K | 2 | CH0603R
R50, R53 | 0 | 2 | CH0603R
R52 | 18k | 1 | CH0603R
R57, R58 |  | 2 | CH0603R
R72 | 1k5 | 1 | CH0603R
R82, R83, R84 | 330 | 3 | CH0603R
R85, R86 | 5.6 | 2 | CH0603R
T1 | 1:4 ADT4-6T | 1 | TC4-1-ADT4-6
T2 | 1:1 T1-6T | 1 | TC4-1-ADT4-6
T3 | 1:1 ADT1-1 | 1 | TC4-1-ADT4-6
U1 | W25Q16 | 1 | SOIC-8-1
U2 | STM32H743 | 1 | 100-LQFP
U3 | M25P80 | 1 | SOIC-8-1
U4 | EP4CE22E22C8N | 1 | 144-QFN
U5, U13 | LM1085-3.3 | 2 | DPAK_132
U6 | LTC6400IUD | 1 | 16-QFN 3x3
U7 | LTC2208CUP | 1 | 64-QFN 9x9
U8 | PAM8406 | 1 | SOP-16
U9 | WM8731 | 1 | 28-SSOP
U10 | LD3985M33R | 1 | SOT23-5
U11 | ACS712-20 | 1 | 8-SOIC
U12, U18 | ADG918BRMZ | 2 | 8-MSOP (NO PAD)
U14 | ST1S10 | 1 | 8-SOIC (PAD)
U15, U16 | MCP6001UT | 2 | SOT23-5
U17 | USBLC6-2SC6 | 1 | SOT23-6-ASM
U19 | SC189CSKTRT | 1 | SOT23-5
U20 | PE4302 | 1 | 20-QFN (4x4)
U21, U22, U23, U24 | FST3253 | 4 | 16-SSOP
U25 | AMS1117-1.8 | 1 | SOT223
U26 | AMS1117-3.3 | 1 | SOT223
U27 | DAC5674IPHP | 1 | 48-TQFP
U28 | OPA2673IRGVT | 1 | 16-QFN 4x4 PAD17
U29, U30, U31 | SC189 | 3 | SOT23-5
D2 | BAV-99 | 1 | SOT23_132
VD1, VD2 | 1N4108 | 2 | 1N4148
VD3 | BZT52-C5V1 | 1 | SOD123
VT1 | BSS123 | 1 | SOT23_132
VT2 | IRFR9024NPBF | 1 | D2PAK_132
X1 | USB-B | 1 | CON: USB-B
X2 | PLS-5 | 1 | CON: PLS-5
X3, X4 | PLD-10 | 2 | CON: PLD-10
X5 | CWF-3 | 1 | CON: CWF-3
X6 | Разъем DC005 | 1 | CON: PJ-102AH
X7 | PLD-10 | 1 | CON: PLD-10
X9 | PLS-3 | 1 | CON: PLS-3
X10 | ENCODER_MAIN1 | 1 | CON: PLS-4
X12, X14 | U.FL-R-SMT U FL IPEX | 2 | CON: u.Fl
X13 | "PTT" | 1 | RJ25-6pin
XG1 | 12.288Mhz TCXO 3.3v TTL/CMOS (set other freq in fpga code) | 1 | OSC: 5032
XG2 | 122.88Mhz | 1 | OCS: GENA
Y1 | 8 мГц | 1 | OSC: Hz
Y2 | ABS 32.768khz | 1 | ABS-25

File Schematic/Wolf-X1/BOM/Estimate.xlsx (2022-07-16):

№ | Название | Количество | Цена | доставка | штук | Ссылка | Чип и дип | Общая цена | Доставка
MAIN |  |  |  |  |  |  |  | 346.32 | 39.12
 | DM3AT-SF-PEJM5 | 1 | 2.94 | 0.74 | 10 | Aliexpress (https://s.click.aliexpress.com/e/_9isgm1)
 | Индуктивность SMD 0630 3.3uH | 1 | 0.63 | 0.24 | 10 | Aliexpress (https://aliexpress.ru/item/4000557059726.html?item_id=4000557059726&sku_id=10000002922152209) |  | 385.44
 | Индуктивность SMD 0630 10uH | 1 | 0.63 | 0.24 | 10 | Aliexpress (https://aliexpress.ru/item/4000557059726.html?item_id=4000557059726&sku_id=10000002922152209)
 | Индуктивность SMD 0420 2,2uH | 4 | 1.60 | 1.29 | 10 | Aliexpress (https://aliexpress.ru/item/1005001648530241.html?spm=a2g2w.productlist.0.0.7b42d5be3thNsw) | ChipDip (https://www.chipdip.ru/product/ha72l-04202r2lftr?from=suggest_product)
 | Индуктивность SMD 0530 10uH | 1 | 0.70 | 0.18 | 10 | Aliexpress (https://aliexpress.ru/item/4001035691825.html?item_id=4001035691825&sku_id=10000013672787789)
 | SC189CSKTRT | 4 | 2.75 | 1.23 | 10 | Aliexpress (https://s.click.aliexpress.com/e/_97KRnB) | ChipDip (https://www.chipdip.ru/product0/8001051325?from=suggest_product)
 | LM1085-3.3 | 2 | 0.79 | 0.75 | 1 | Aliexpress (https://s.click.aliexpress.com/e/_A281Oz)
 | ST1S10PHR | 1 | 4.85 | 2.53 | 5 | Aliexpress (https://s.click.aliexpress.com/e/_9g82VX)
 | ACS712-20 | 1 | 4.36 | 2.53 | 5 | Aliexpress (https://s.click.aliexpress.com/e/_ADbq7F)
 | LD3985M33R | 1 | 0.94 |  | 10 | Aliexpress (https://s.click.aliexpress.com/e/_AMh9kh)
 | AMS1117-3.3 | 2 | 0.92 |  | 20 | Aliexpress (https://s.click.aliexpress.com/e/_AeJeaD)
 | AMS1117-1.8 | 1 | 1.18 |  | 20 | Aliexpress (https://s.click.aliexpress.com/e/_AeJeaD)
 | MCP6001UT | 2 | 1.96 |  | 10 | Aliexpress (https://s.click.aliexpress.com/e/_9ihxe9)
 | PE4302 | 1 | 2.31 | 0.65 | 5 | Aliexpress (https://s.click.aliexpress.com/e/_AfZ1iz)
 | NV7050SA 122.88Mhz | 1 | 5.00 | 3.79 | 1 | Aliexpress (https://s.click.aliexpress.com/e/_A5JA5P)
 | 12.288Mhz | 1 | 20.00 | 3.47 | 2 | Aliexpress (https://aliexpress.ru/item/4000577979227.html?sku_id=10000003324946109)
 | PAM8406DR | 1 | 3.00 | 0.74 | 10 | Aliexpress (https://s.click.aliexpress.com/e/_A8j981)
 | M25P80-VMW6G | 1 | 1.45 |  | 10 | Aliexpress (https://s.click.aliexpress.com/e/_A6hL4Z)
 | EP4CE22E22C8N | 1 | 59.85 | 2.11 | 1 | Aliexpress (https://s.click.aliexpress.com/e/_9iUwY9)
 | STM32H743VIT6 | 1 | 17.78 |  | 1 | Aliexpress (https://aliexpress.ru/item/1005003007981742.html?mp=1&sku_id=12000023197731242)
 | 25Q16BVSIG | 1 | 1.37 |  | 5 | Aliexpress (https://s.click.aliexpress.com/e/_AqCio9)
 | WM8731 | 1 | 4.68 | 2.53 | 2 | Aliexpress (https://s.click.aliexpress.com/e/_Akey6D)
 | LTC6400IUD | 1 | 2.85 | 1.24 | 1 | Aliexpress (https://s.click.aliexpress.com/e/_AseOOZ)
 | LTC2208CUP | 1 | 11.05 | 3.16 | 1 | Aliexpress (https://s.click.aliexpress.com/e/_ADIvIz)
 | OPA2673IRGVT | 1 | 4.95 |  | 5 | Aliexpress (https://s.click.aliexpress.com/e/_AAqwKp)
 | DAC5674IPHP | 1 | 14.00 | 3.04 | 1 | Aliexpress (https://s.click.aliexpress.com/e/_9y3KyN)
 | MC306 32,768 кГц | 1 | 1.08 | 0.41 | 10 | Aliexpress (https://aliexpress.ru/item/1994878414.html?sku_id=52635197667)
 | USBLC6-2SC6 | 1 | 1.01 |  | 10 | Aliexpress (https://s.click.aliexpress.com/e/_9xdO4z)
 | hc-49s 8 МГц | 1 | 1.14 | 0.20 | 20 | Aliexpress (https://s.click.aliexpress.com/e/_9QtdNT)
 | USB B типа «мама» | 1 | 1.01 | 0.37 | 10 | Aliexpress (https://s.click.aliexpress.com/e/_A1iVsh)
 | PJ-307 | 3 | 0.73 |  | 10 | Aliexpress (https://s.click.aliexpress.com/e/_AUoOZf)
 | ADG918BRMZ | 2 | 1.17 | 0.20 | 1 | Aliexpress (https://s.click.aliexpress.com/e/_989xMD)
 | FST3253MTCX | 4 | 1.68 |  | 5 | Aliexpress (https://s.click.aliexpress.com/e/_AFJSln)
 |  |  | 180.36 | 31.64
PA UNIT
 | STPIC6C595TTR | 1 | 2.42 | 0.74 | 5 | Aliexpress (https://aliexpress.ru/item/1005001359582377.html?sku_id=12000015804019376)
 | Реле | 4 | 2.73 |  | 5 | Aliexpress (https://aliexpress.ru/item/4000017778928.html?item_id=4000017778928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)
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

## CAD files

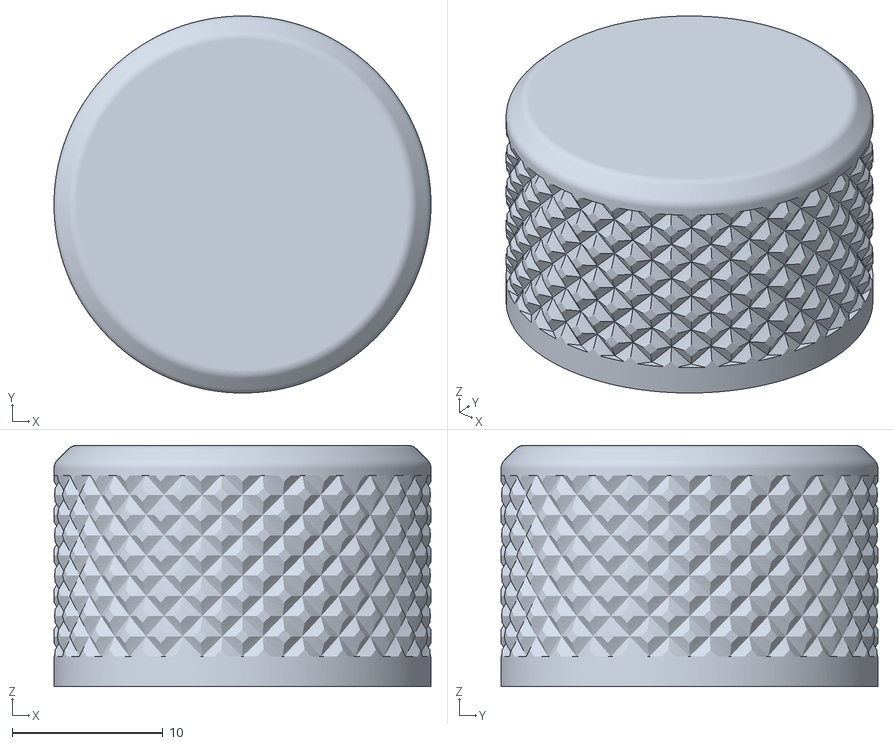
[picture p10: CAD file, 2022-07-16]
Schematic/Wolf-X1/Addons/20mm_Main_Encoder.stl
25.0 x 25.0 x 16.0

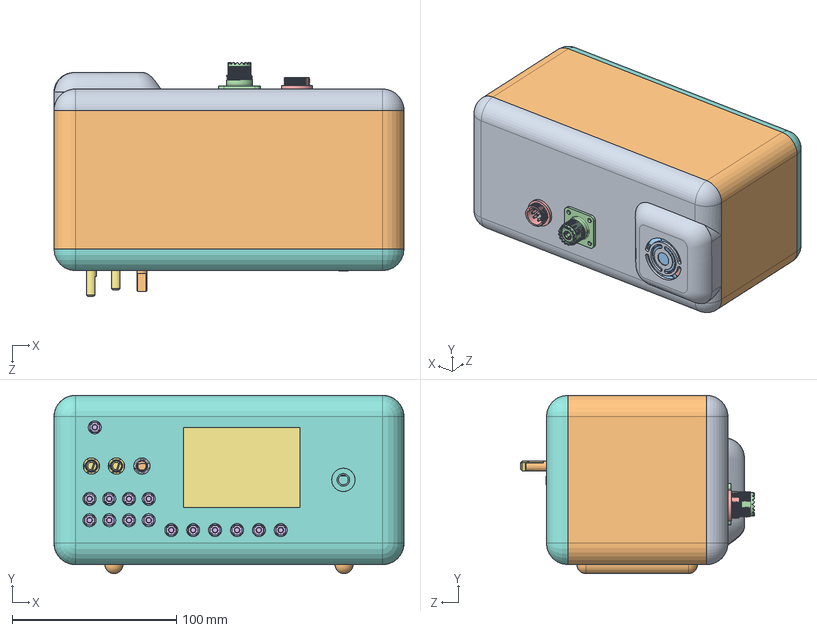
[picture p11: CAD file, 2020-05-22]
Scheme/CASE/construct.SLDASM
213.0 x 108.5 x 142.1 mm
beam_long x 4
beam_short x 4
FRONT
MB
RF
tactileswitch-long x 15
Fusion001.step
Rotary Encoder
Rotary_Encoder
D-handle
40x40x10 DC Fan
pl-259_jack
GX16-8
speaker
RotaryPotencimetr x 2
case_front
case_back
case_shell

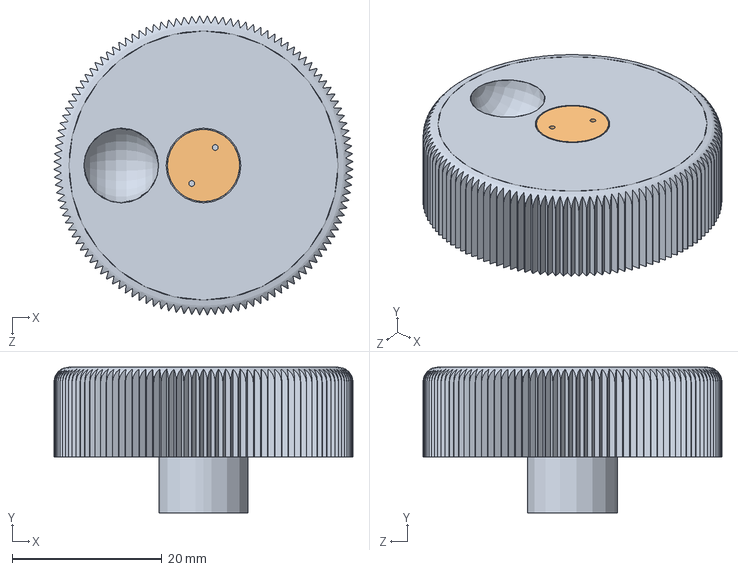
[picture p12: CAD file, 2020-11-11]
Schematic/Wolf/CASE/3'2/3DPrinter/case/shuttle_knob_construct.SLDASM
40.0 x 19.5 x 40.0 mm
shuttle_knob
shuttle_knob_cap

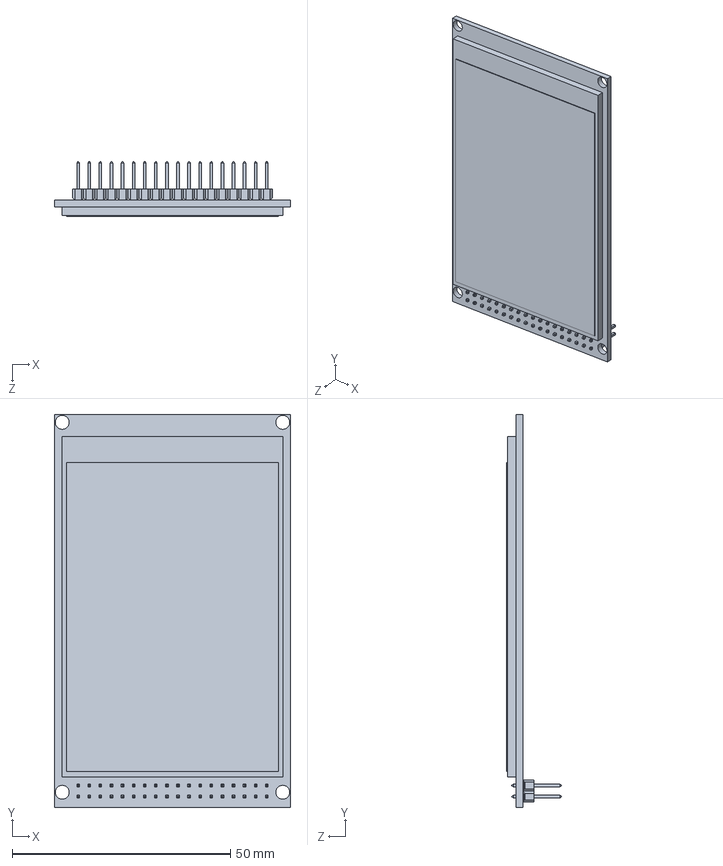
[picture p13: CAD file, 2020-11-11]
Schematic/Wolf/CASE/3'2/3DPrinter/Display480x320.SLDASM
54.1 x 90.0 x 12.6 mm

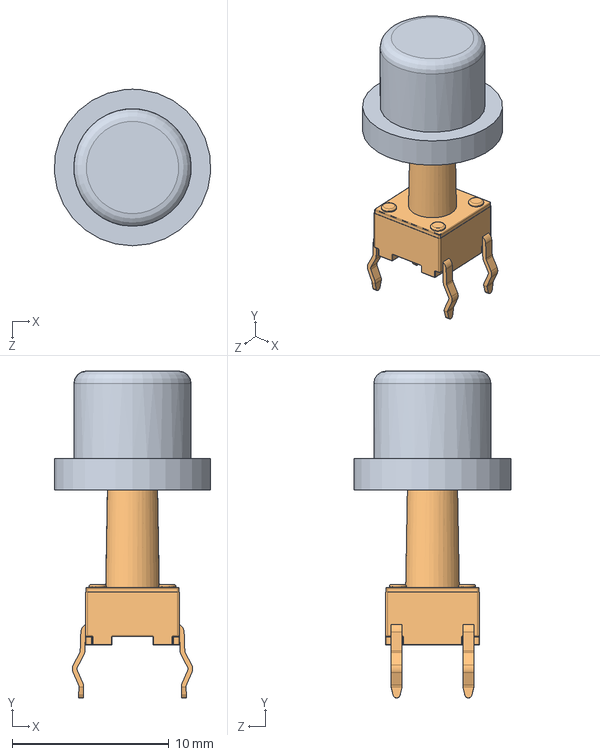
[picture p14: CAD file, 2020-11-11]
Schematic/Wolf/CASE/3'2/3DPrinter/case/button_construct.SLDASM
9.99 x 20.9 x 10.0 mm
button
tactileswitch-long

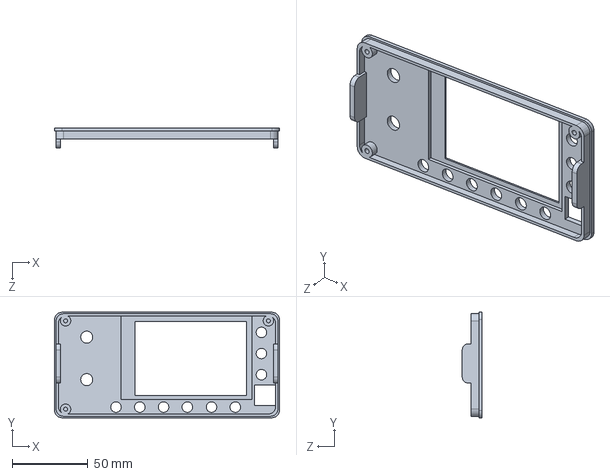
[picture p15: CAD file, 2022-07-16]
Schematic/Wolf-Lite/Case/Front Lite V2.SLDPRT
149.0 x 70.0 x 13.0 mm

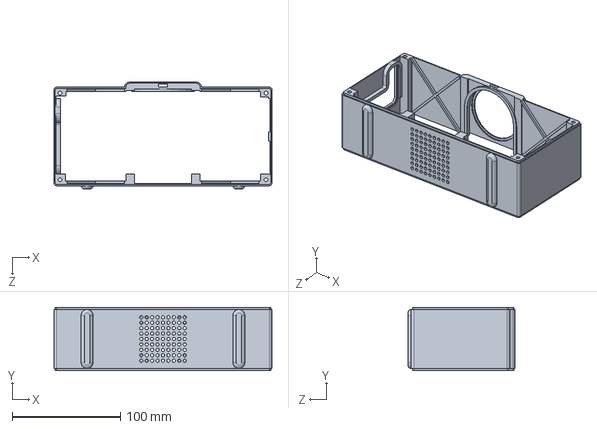
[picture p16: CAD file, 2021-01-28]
Schematic/Wolf/CASE/3'2/3DPrinter/case/case_shell.SLDPRT
201.0 x 58.4 x 98.7 mm

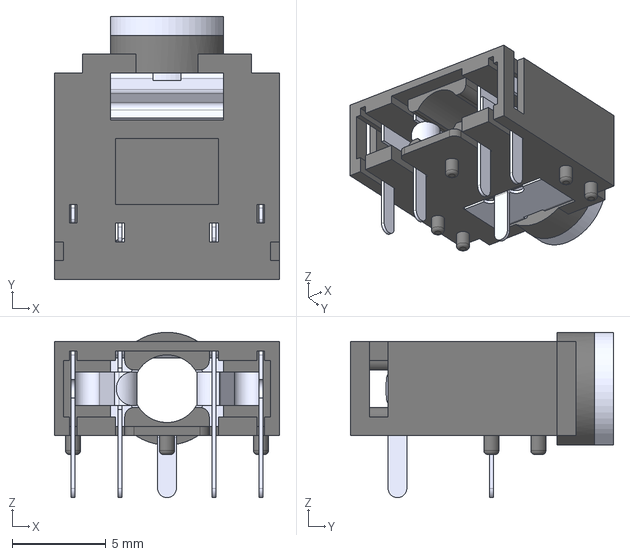
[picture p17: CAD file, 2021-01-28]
Schematic/Wolf/CASE/3'2/3DPrinter/ST-212.step
12.0 x 14.0 x 8.80 mm

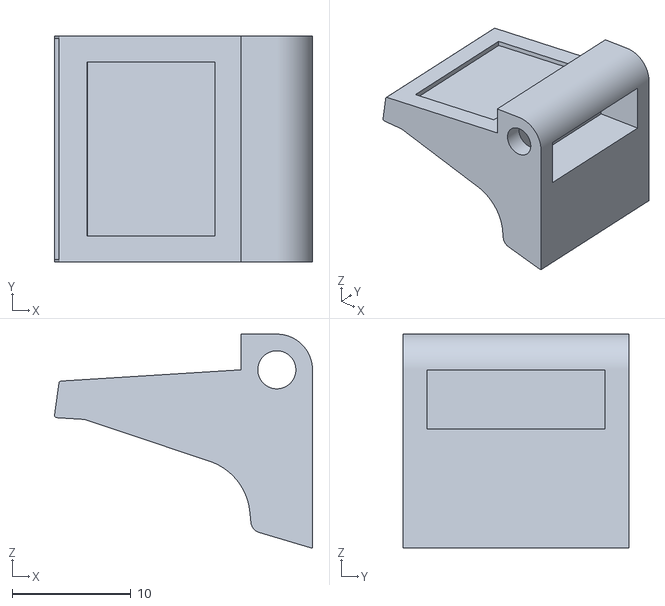
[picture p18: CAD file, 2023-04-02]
Schematic/Wolf/CASE/7/Panel/кнопка_низ_7.stl
21.7 x 19.0 x 18.0

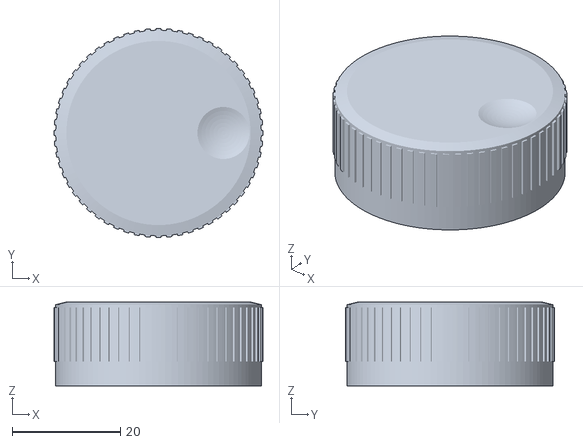
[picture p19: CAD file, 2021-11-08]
Schematic/Wolf/CASE/VFO/VFO_38mm.stl
38.6 x 38.6 x 15.5

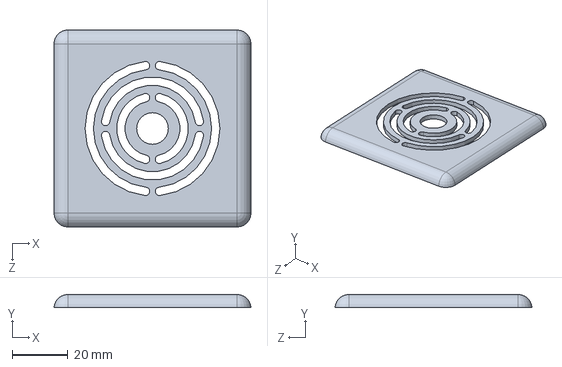
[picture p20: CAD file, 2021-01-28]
Schematic/Wolf/CASE/3'2/3DPrinter/case/case_speaker_cap.SLDPRT
71.0 x 4.70 x 71.0 mm

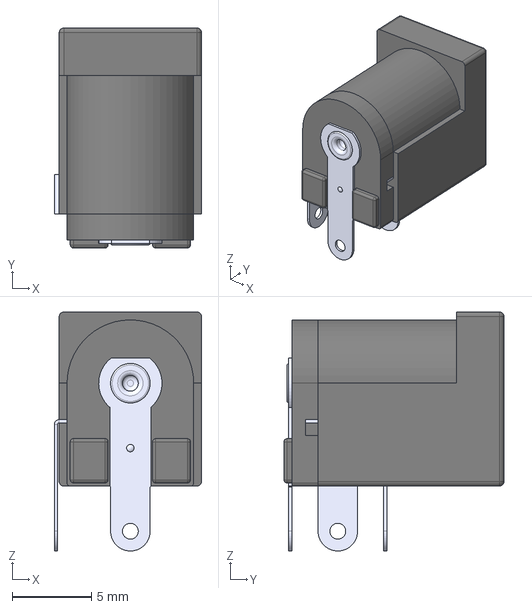
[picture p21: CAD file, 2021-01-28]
Schematic/Wolf/CASE/3'2/3DPrinter/DS-261A.step
9.30 x 13.9 x 15.1 mm

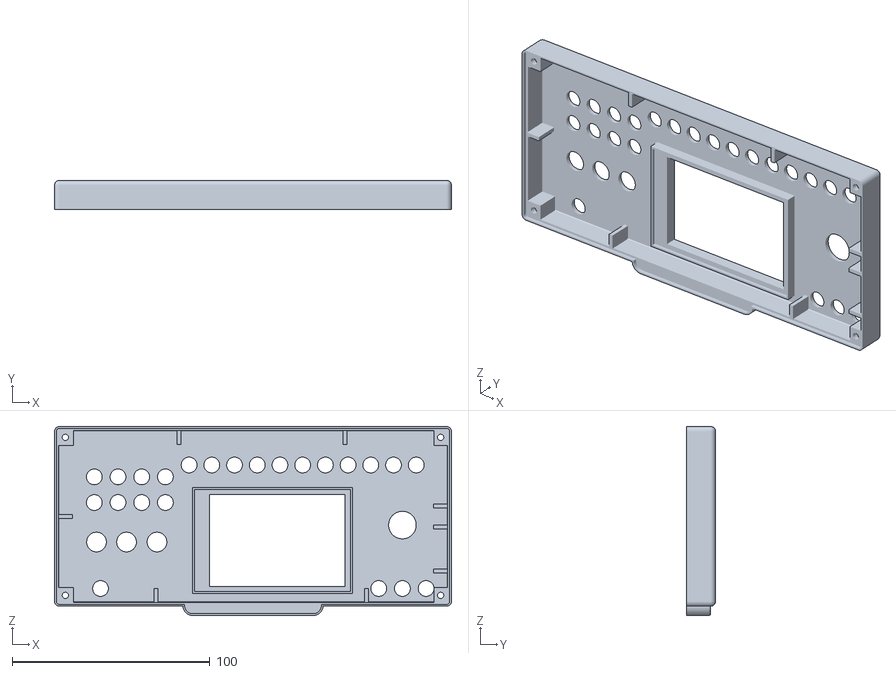
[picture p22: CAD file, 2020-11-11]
Schematic/Wolf/CASE/3'2/3DPrinter/STL/case_front.STL
201.0 x 14.8 x 95.7

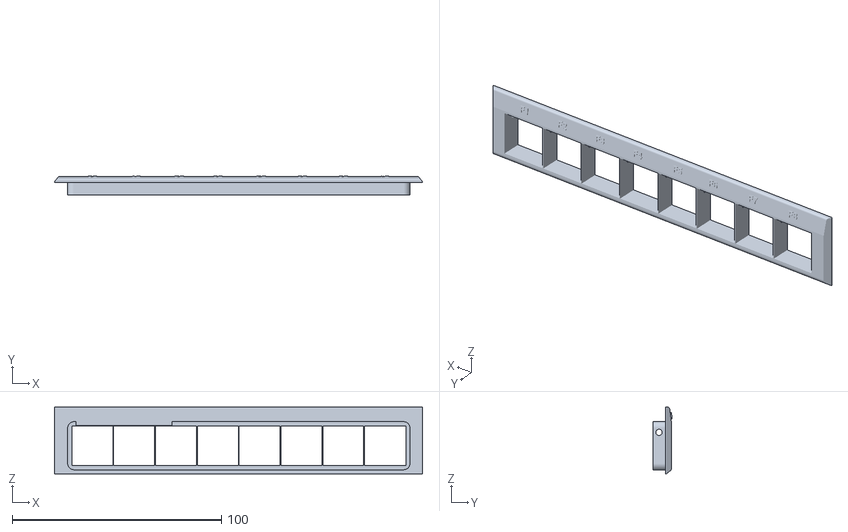
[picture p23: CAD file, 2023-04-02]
Schematic/Wolf/CASE/7/Panel/рамка_низ_7.stl
176.0 x 9.31 x 32.0

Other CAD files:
Schematic/Wolf/CASE/3'2/3DPrinter/KY-040 Rotary Encoder.SLDASM
Schematic/Wolf/CASE/3'2/3DPrinter/STL/case_shell.STL
Schematic/Wolf-Lite/Case/BOT-LITE.SLDPRT
Schematic/Wolf-X1/Addons/Milling_Top.DWG
Schematic/Wolf-Lite/Altium_Designer/Front-Unit/Wl-FRONT-EDM/16-SOIC_MCP3008-I_SL.x_t
Schematic/Wolf-Lite/Altium_Designer/Front-Unit/Wl-FRONT-EDM/BAT__CH224-2032_POWER_BAT.x_t
Schematic/Wolf-Lite/Altium_Designer/Front-Unit/Wl-FRONT-EDM/BUT__6x6_SMD_Tactile_switches.x_t
Schematic/Wolf-Lite/Altium_Designer/Front-Unit/Wl-FRONT-EDM/BUT__6x6_Tactile_switches.x_t
Schematic/Wolf-Lite/Altium_Designer/Front-Unit/Wl-FRONT-EDM/CH0805C_Capacitor.x_t
Schematic/Wolf-Lite/Altium_Designer/Front-Unit/Wl-FRONT-EDM/CH0805R_Resistor.x_t
Schematic/Wolf-Lite/Altium_Designer/Front-Unit/Wl-FRONT-EDM/CON__PLS-5_5-Connector.x_t
Schematic/Wolf-Lite/Altium_Designer/Front-Unit/Wl-FRONT-EDM/IPS_3.5_ILI9481_LCD-IPS_3.5.x_t
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

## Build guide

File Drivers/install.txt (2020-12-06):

This driver uses windows USB Virtual com port driver files
If it;s dont work, please update system drivers from https://my.st.com/content/my_st_com/en/products/development-tools/software-development-tools/stm32-software-development-tools/stm32-utilities/stsw-stm32102.html

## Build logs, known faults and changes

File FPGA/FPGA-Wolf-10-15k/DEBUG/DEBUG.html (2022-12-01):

DEBUG

2022.11.27.12:52:08 | Datasheet

Overview

Memory Map

## in_system_sources_probes_0

altera_in_system_sources_probes v18.1

Parameters

device_family | CYCLONEIVE
gui_use_auto_index | true
sld_auto_instance_index | YES
sld_instance_index | 0
instance_id | DBG1
probe_width | 32
source_width | 0
source_initial_value | 0
create_source_clock | false
create_source_clock_enable | false
enable_metastability | NO
deviceFamily | UNKNOWN
generateLegacySim | false

Software Assignments
(none)

generation took 0,02 seconds | rendering took 0,02 seconds

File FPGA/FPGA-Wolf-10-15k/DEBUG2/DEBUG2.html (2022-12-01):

DEBUG2

2022.11.27.13:36:10 | Datasheet

Overview

Memory Map

## in_system_sources_probes_0

altera_in_system_sources_probes v18.1

Parameters

device_family | CYCLONEIVE
gui_use_auto_index | true
sld_auto_instance_index | YES
sld_instance_index | 0
instance_id | DBG2
probe_width | 3
source_width | 0
source_initial_value | 0
create_source_clock | false
create_source_clock_enable | false
enable_metastability | NO
deviceFamily | UNKNOWN
generateLegacySim | false

Software Assignments
(none)

generation took 0,02 seconds | rendering took 0,02 seconds

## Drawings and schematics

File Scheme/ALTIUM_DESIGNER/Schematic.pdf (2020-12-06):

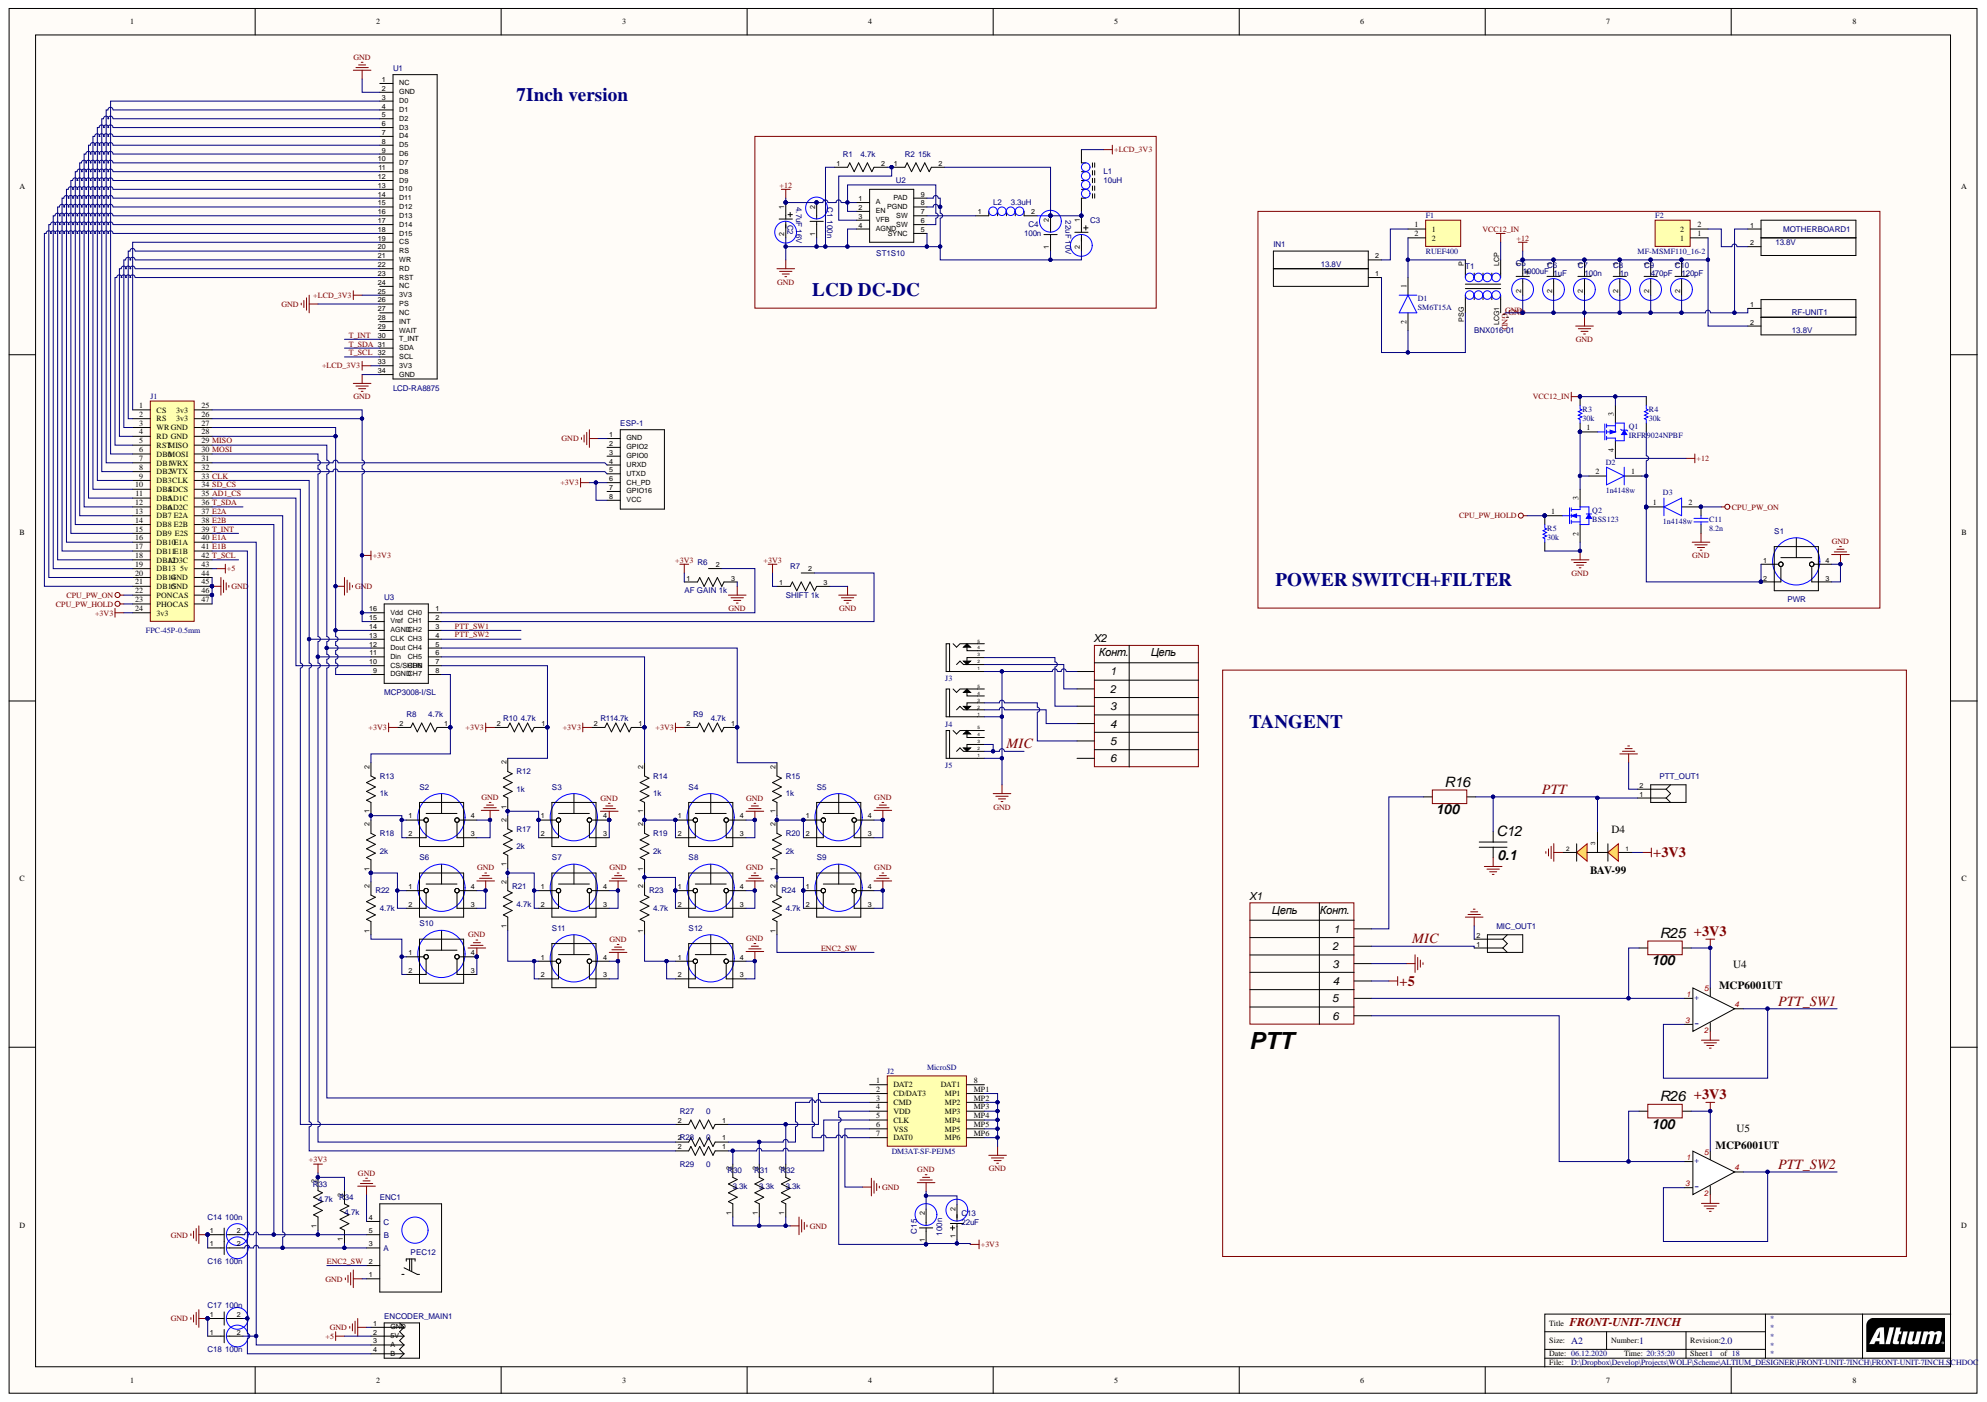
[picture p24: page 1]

DB3 9 | CLK

+3V3 | ENC1 | 2 1 | DM3AT-SF-PEJM5 GND

DAT0 7

Size: A2 | Number: 1 | Revision: 2.0

Date: 06.12.2020 Time: 20:35:20 | | Sheet of

D:\Dropbox\Develop\Projects\WOLF\Scheme\ALTIUM_DESIGNER\FRONT-UNIT-7INCH\FRONT-UNIT-7INCH.SCHDOC

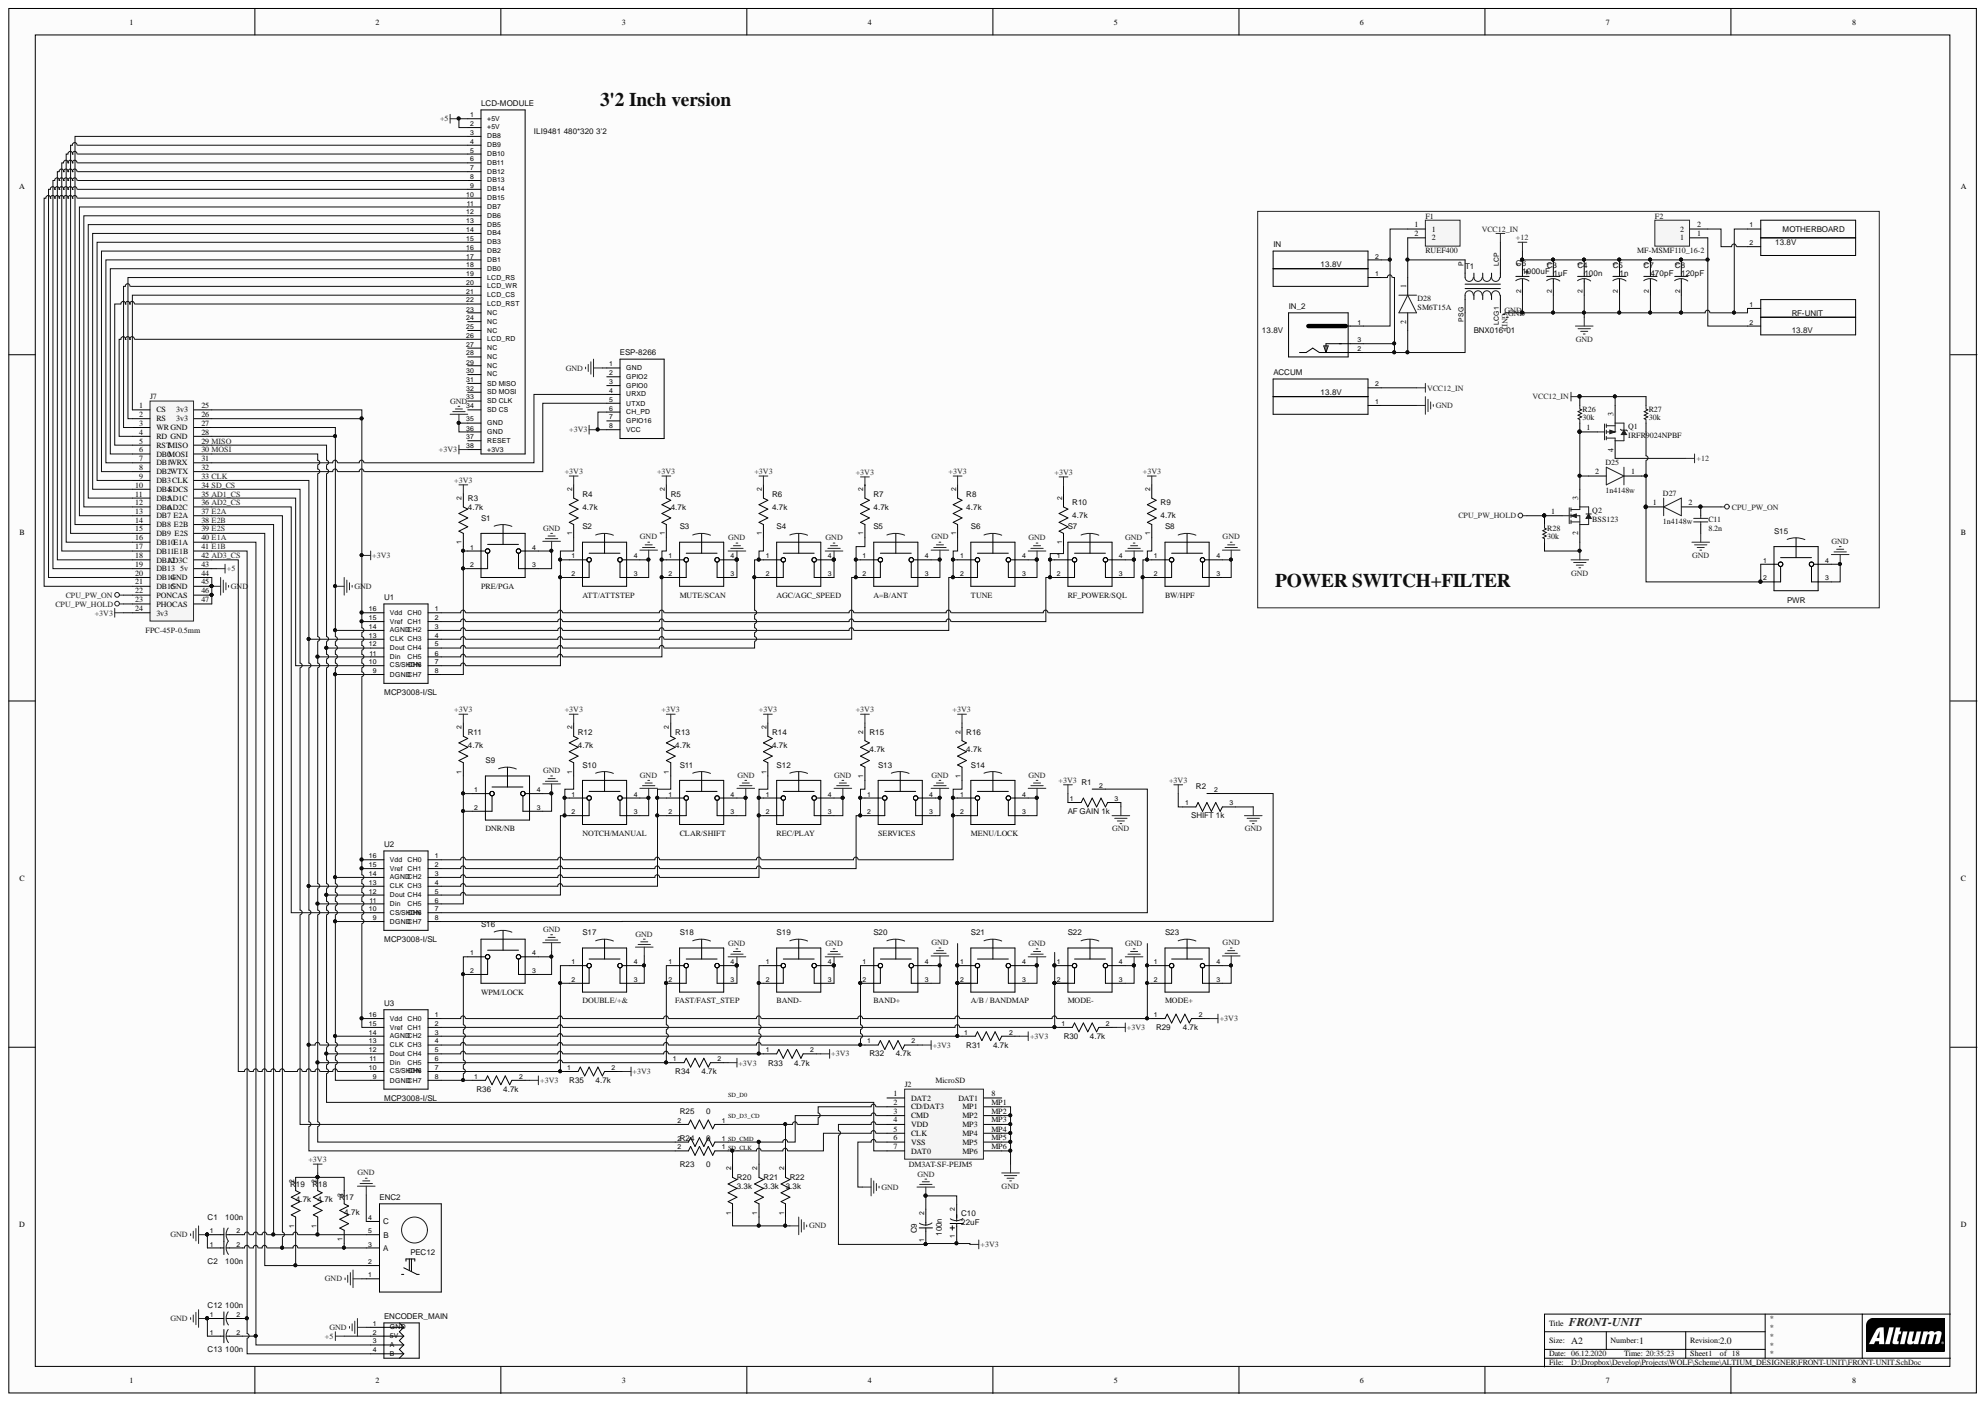
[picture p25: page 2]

GND

RS 2 | GND 35

DB3 9 | CLK
DB4 10 SDCS | 34 | SD_CS | +3V3

DB5 11 AD1C | 35 | AD1_CS
DB6 12 AD2C | 36 | AD2_CS
DB7 13 E2A | 37 | E2A
DB8 14 E2B | 38 | E2B

Dout 12
Din 11

CS/SHDN 10

CS/SHDN 10 | | 1 2 +3V3

VDD 4

2 1 SD_CLK | DAT0 7

VSS 6

D:\Dropbox\Develop\Projects\WOLF\Scheme\ALTIUM_DESIGNER\FRONT-UNIT\FRONT-UNIT.SchDoc

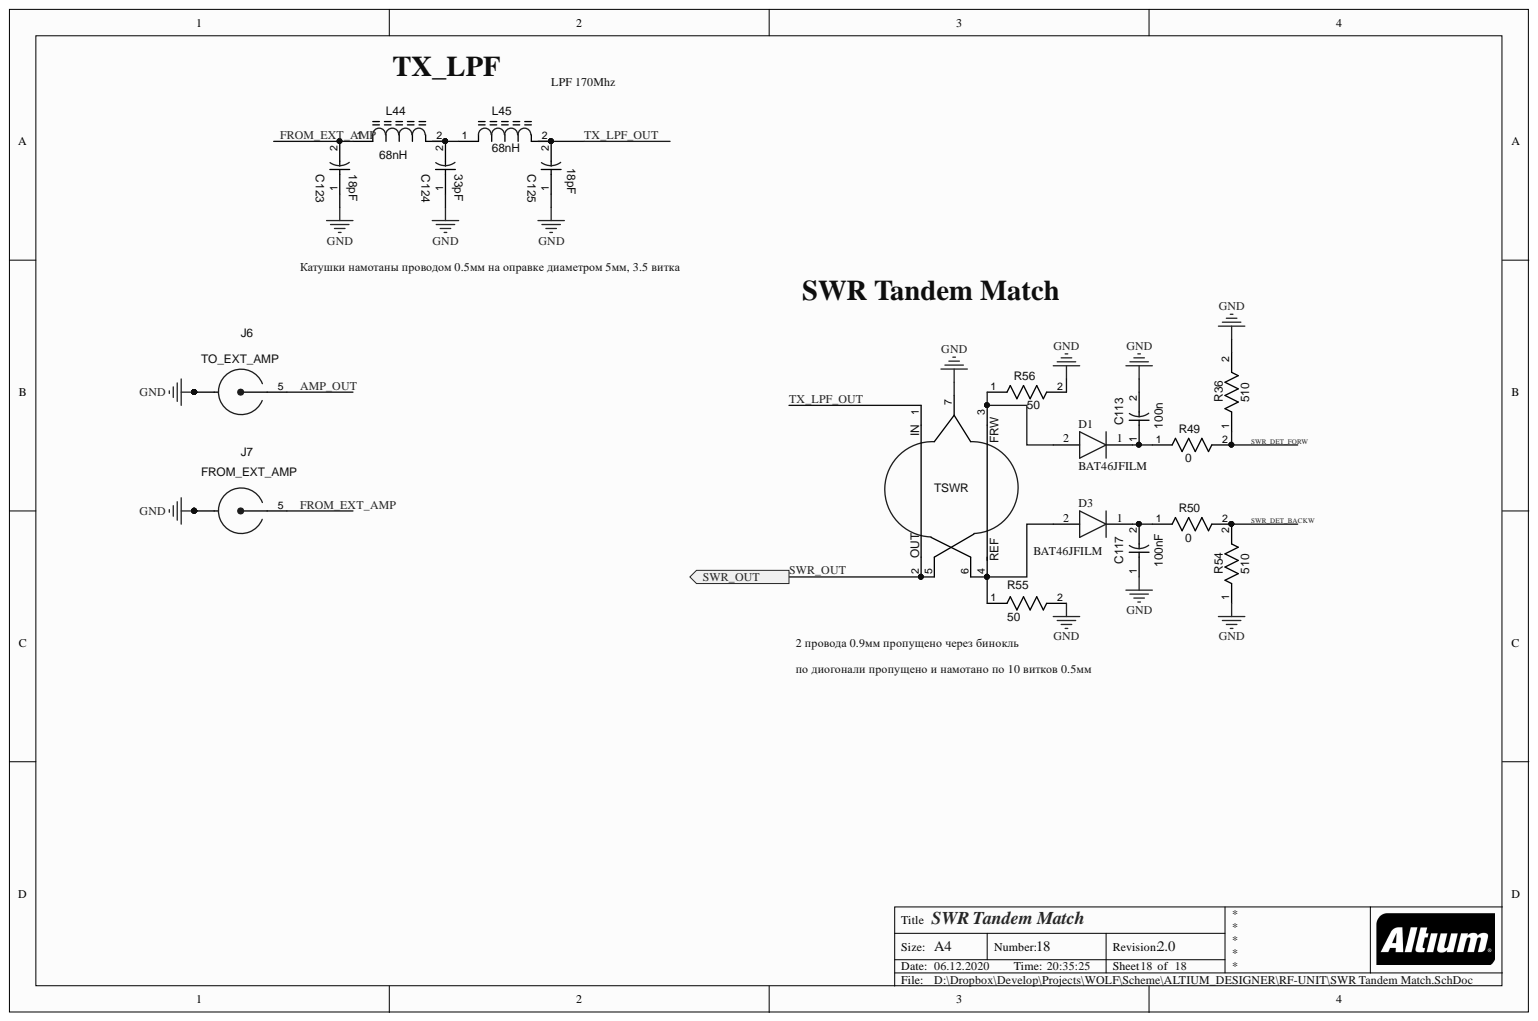
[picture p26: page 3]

Катушки намотаны проводом 0.5мм на оправке диаметром 5мм, 3.5 витка

2 провода 0.9мм пропущено через бинокль

по диогонали пропущено и намотано по 10 витков 0.5мм

SWR Tandem Match Title | * *

Size: A4 | Number: 18 | Revision: 2.0

D:\Dropbox\Develop\Projects\WOLF\Scheme\ALTIUM_DESIGNER\RF-UNIT\SWR Tandem Match.SchDoc

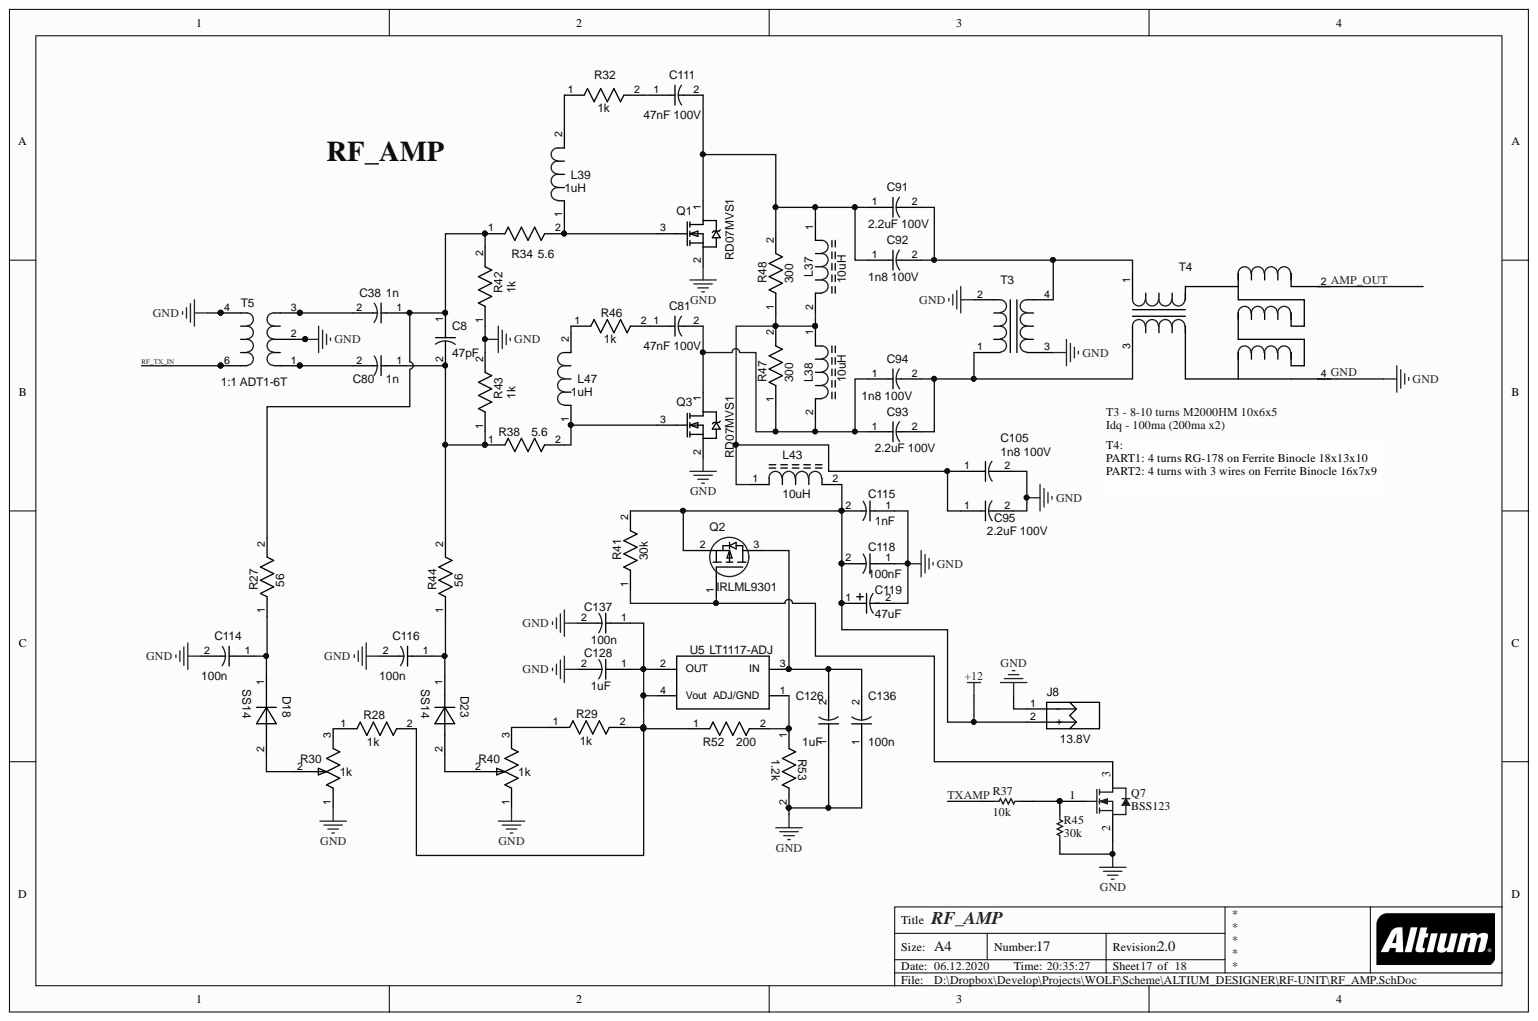
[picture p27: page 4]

RF_AMP T i t l e | ****

Size: A4 | N umber: 1 7 | Rev i s i o n : 2.0

6.1 2.2 T ime: : : | | Sheet o f

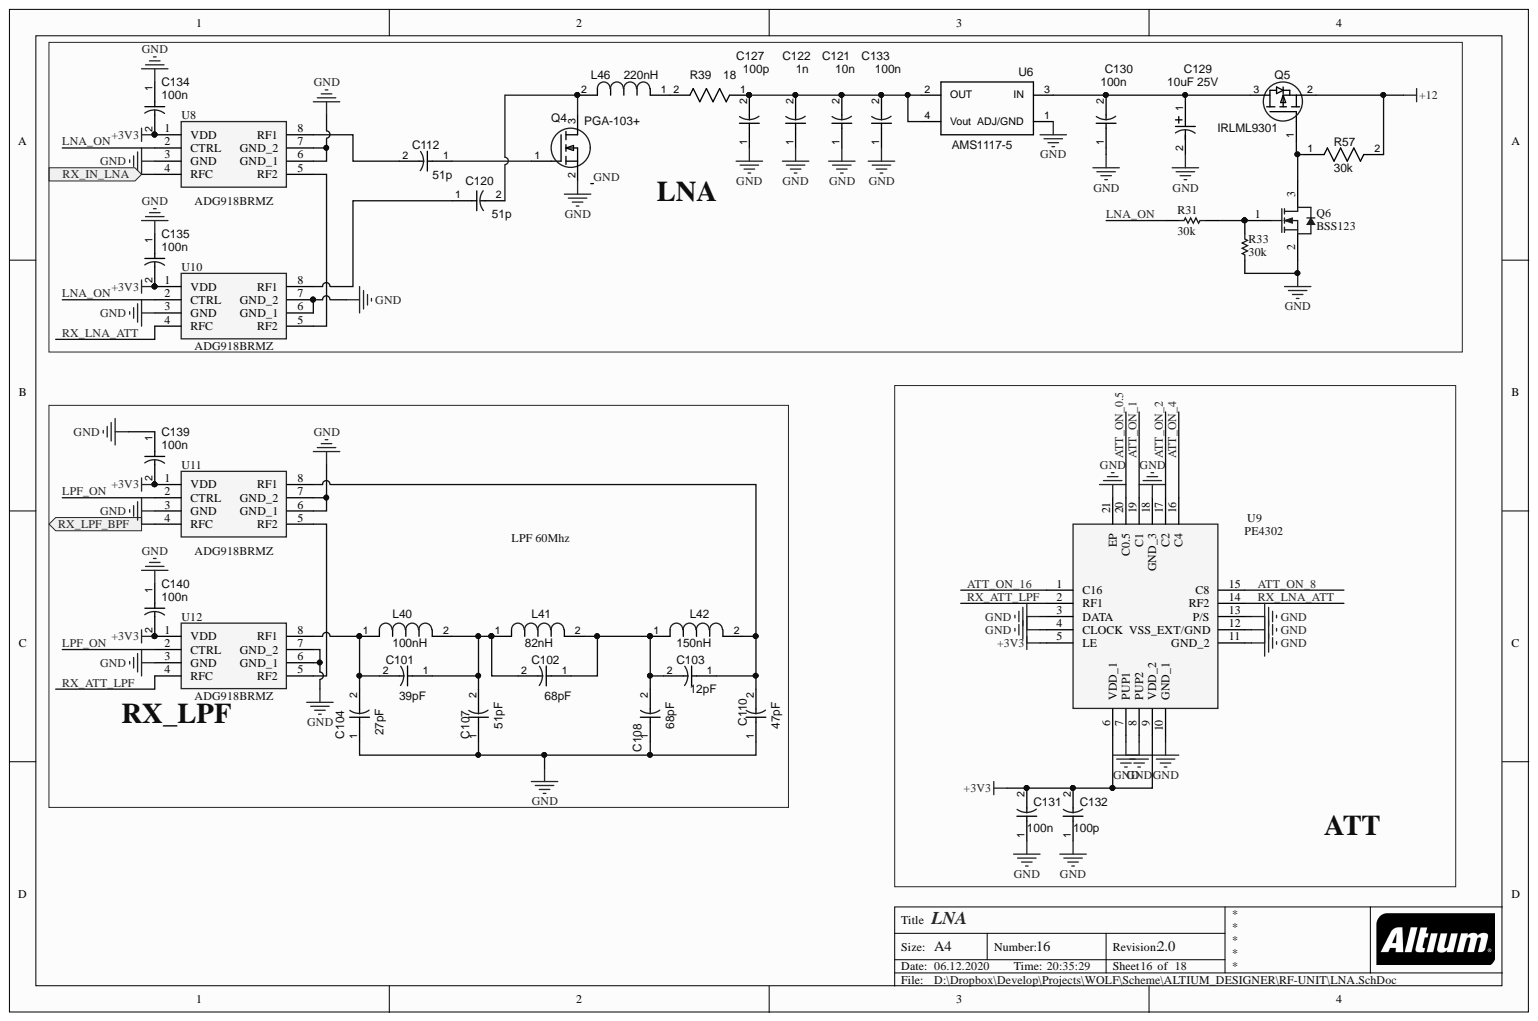
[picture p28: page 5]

LNA Title | * *

Size: A4 | Number: 16 | Revision: 2.0

D:\Dropbox\Develop\Projects\WOLF\Scheme\ALTIUM_DESIGNER\RF-UNIT\LNA.SchDoc

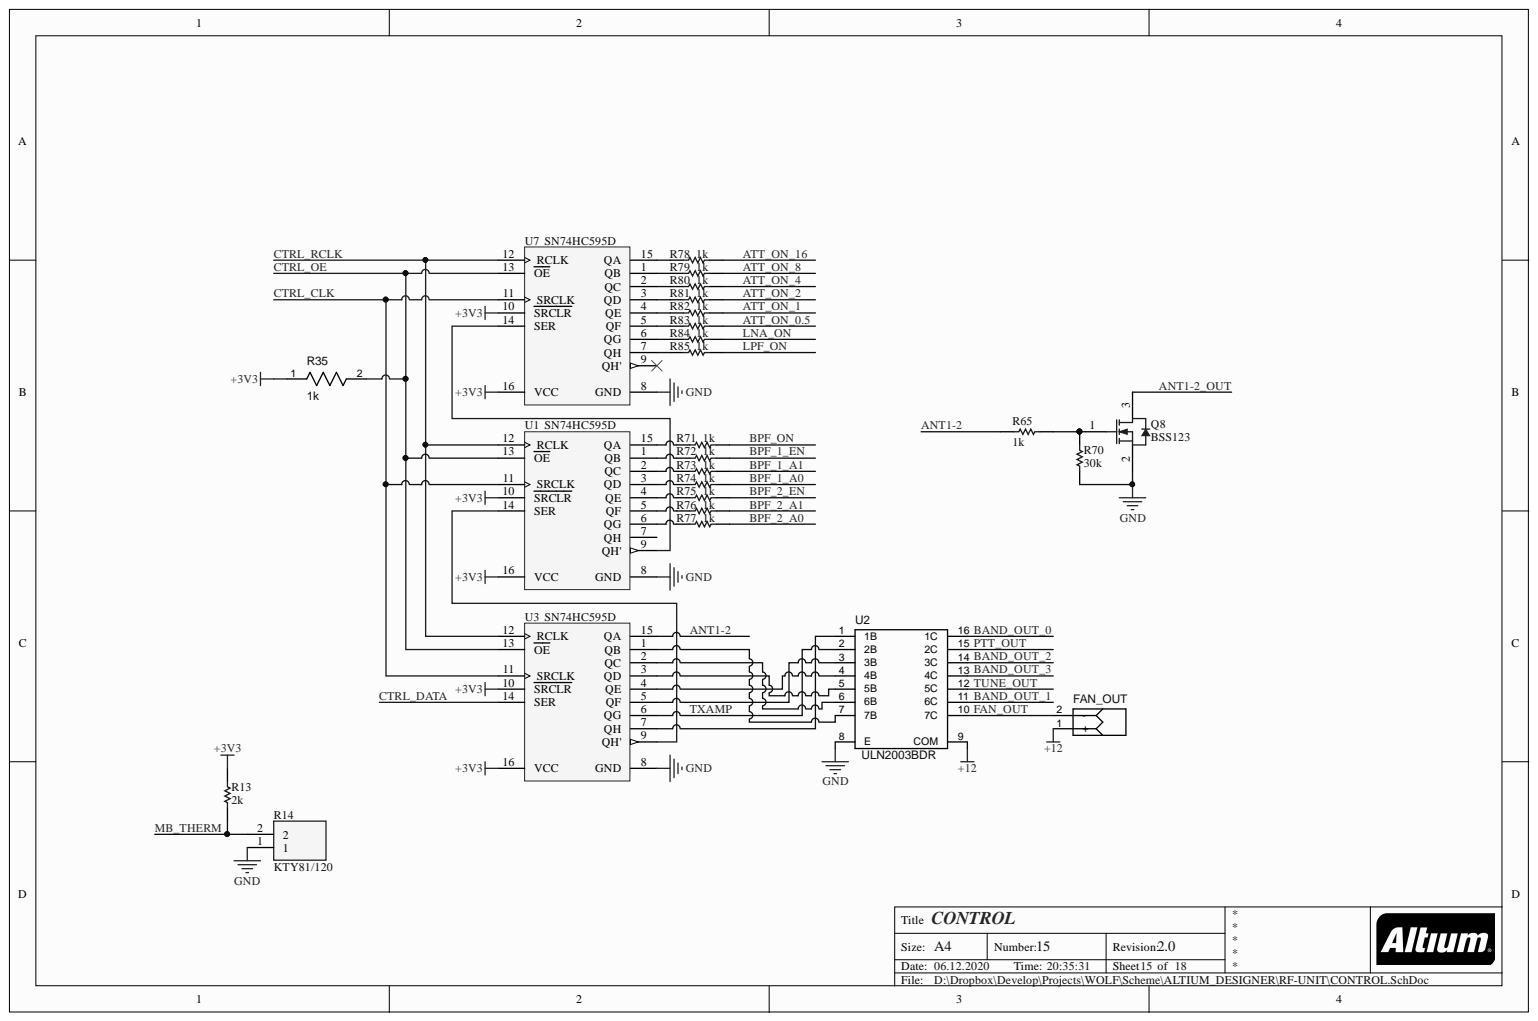
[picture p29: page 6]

CONTROL Title | * *

Size: A4 | Number: 15 | Revision: 2.0

D:\Dropbox\Develop\Projects\WOLF\Scheme\ALTIUM_DESIGNER\RF-UNIT\CONTROL.SchDoc

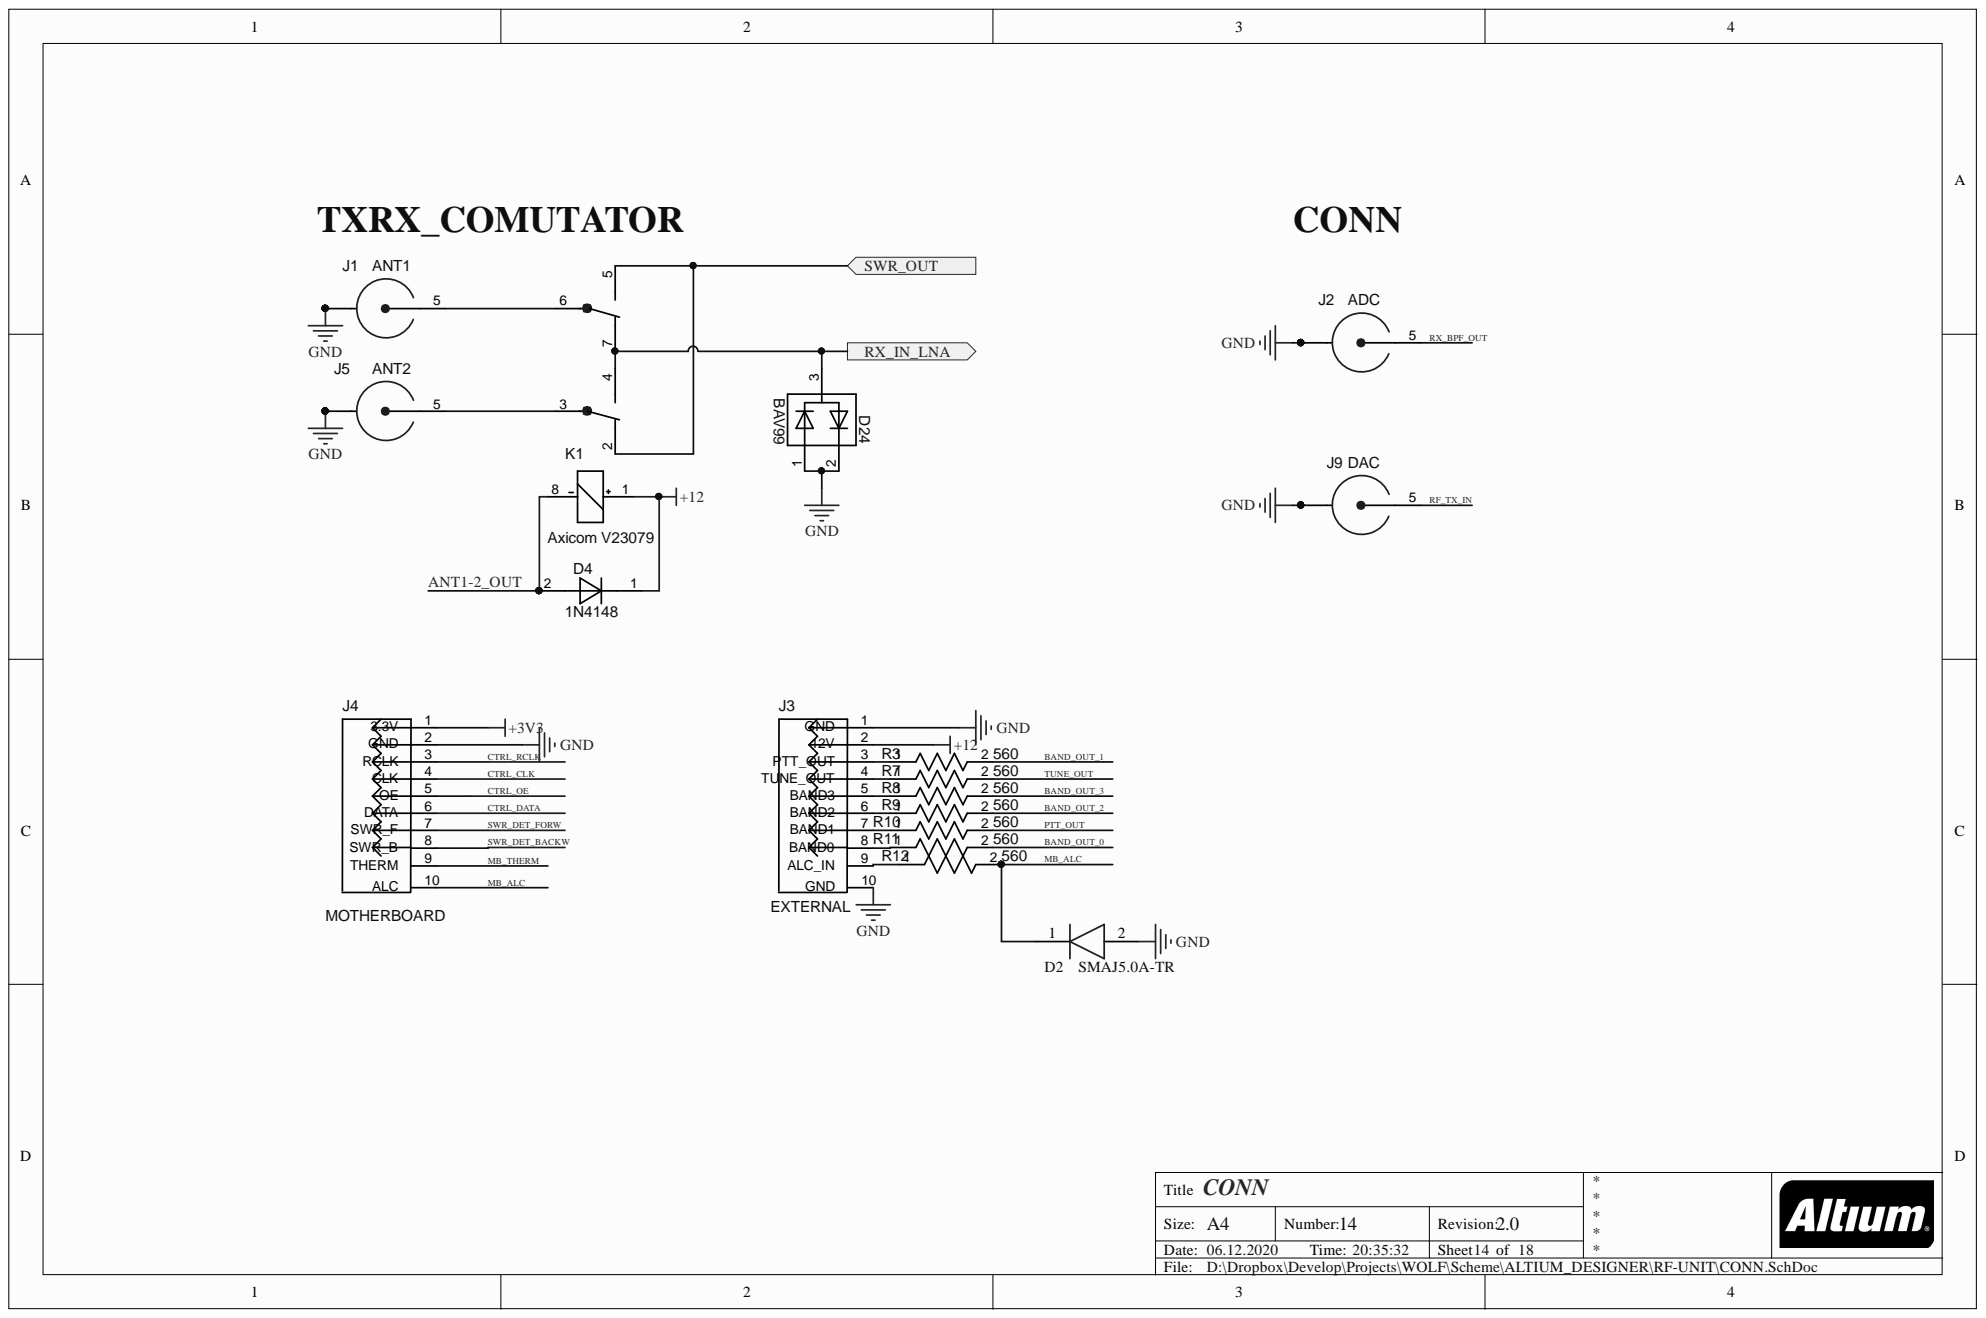
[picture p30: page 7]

CONN Title | * *

Size: A4 | Number: 14 | Revision: 2.0

D:\Dropbox\Develop\Projects\WOLF\Scheme\ALTIUM_DESIGNER\RF-UNIT\CONN.SchDoc

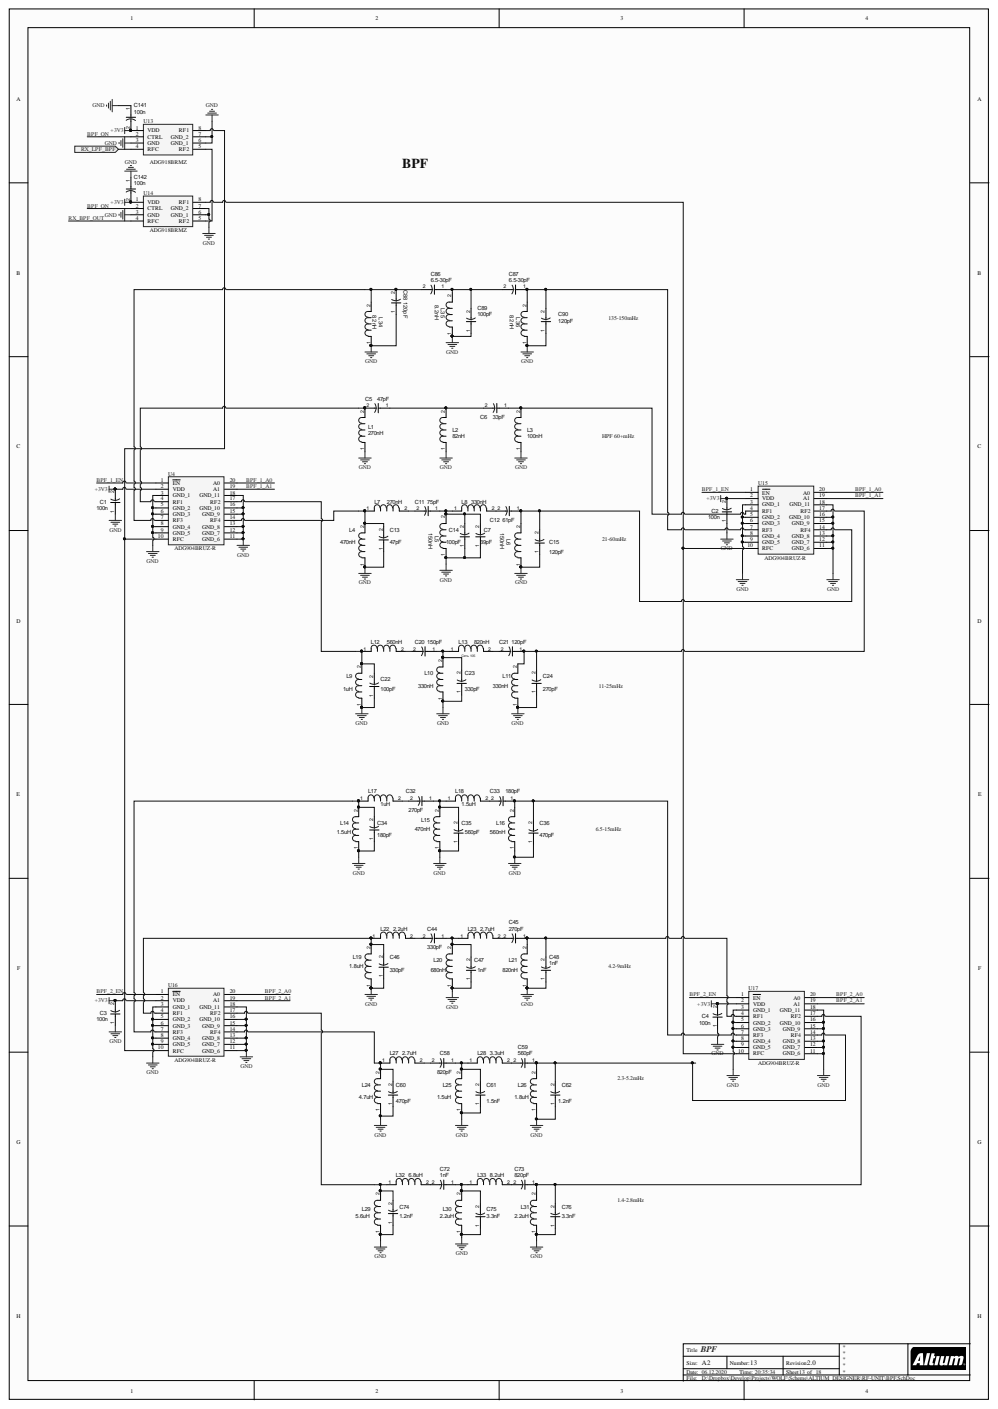
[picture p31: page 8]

Title BPF

Size: A2 | Number: 13 | Revision: 2.0

D:\Dropbox\Develop\Projects\WOLF\Scheme\ALTIUM_DESIGNER\RF-UNIT\BPF.SchDoc

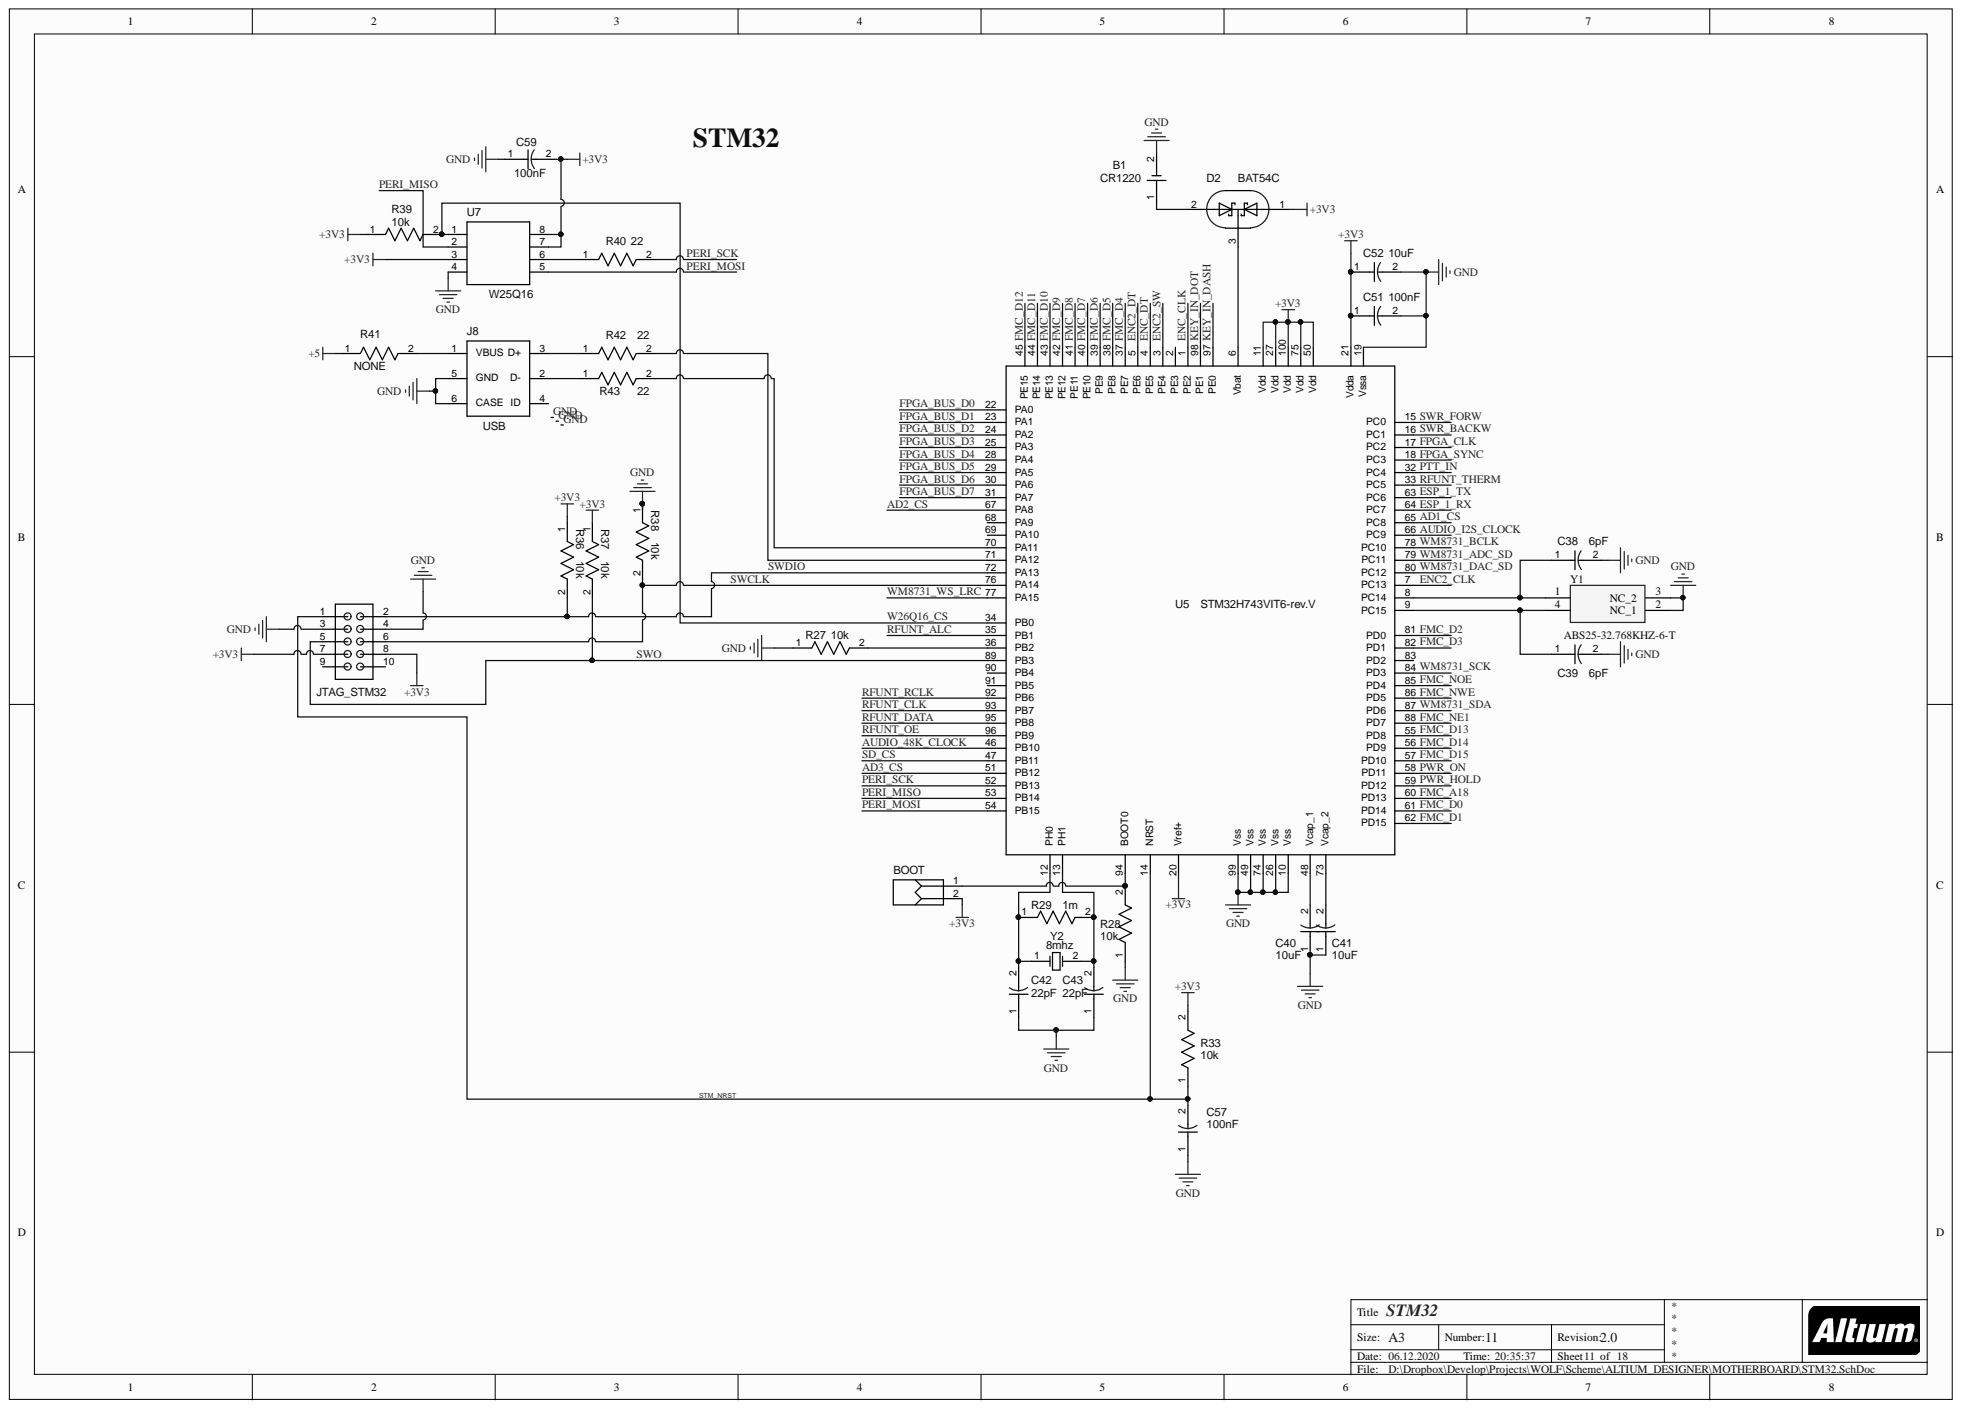
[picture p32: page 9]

STM32 Title

Size: A3 | Number: 11 | Revision: 2.0

D:\Dropbox\Develop\Projects\WOLF\Scheme\ALTIUM_DESIGNER\MOTHERBOARD\STM32.SchDoc

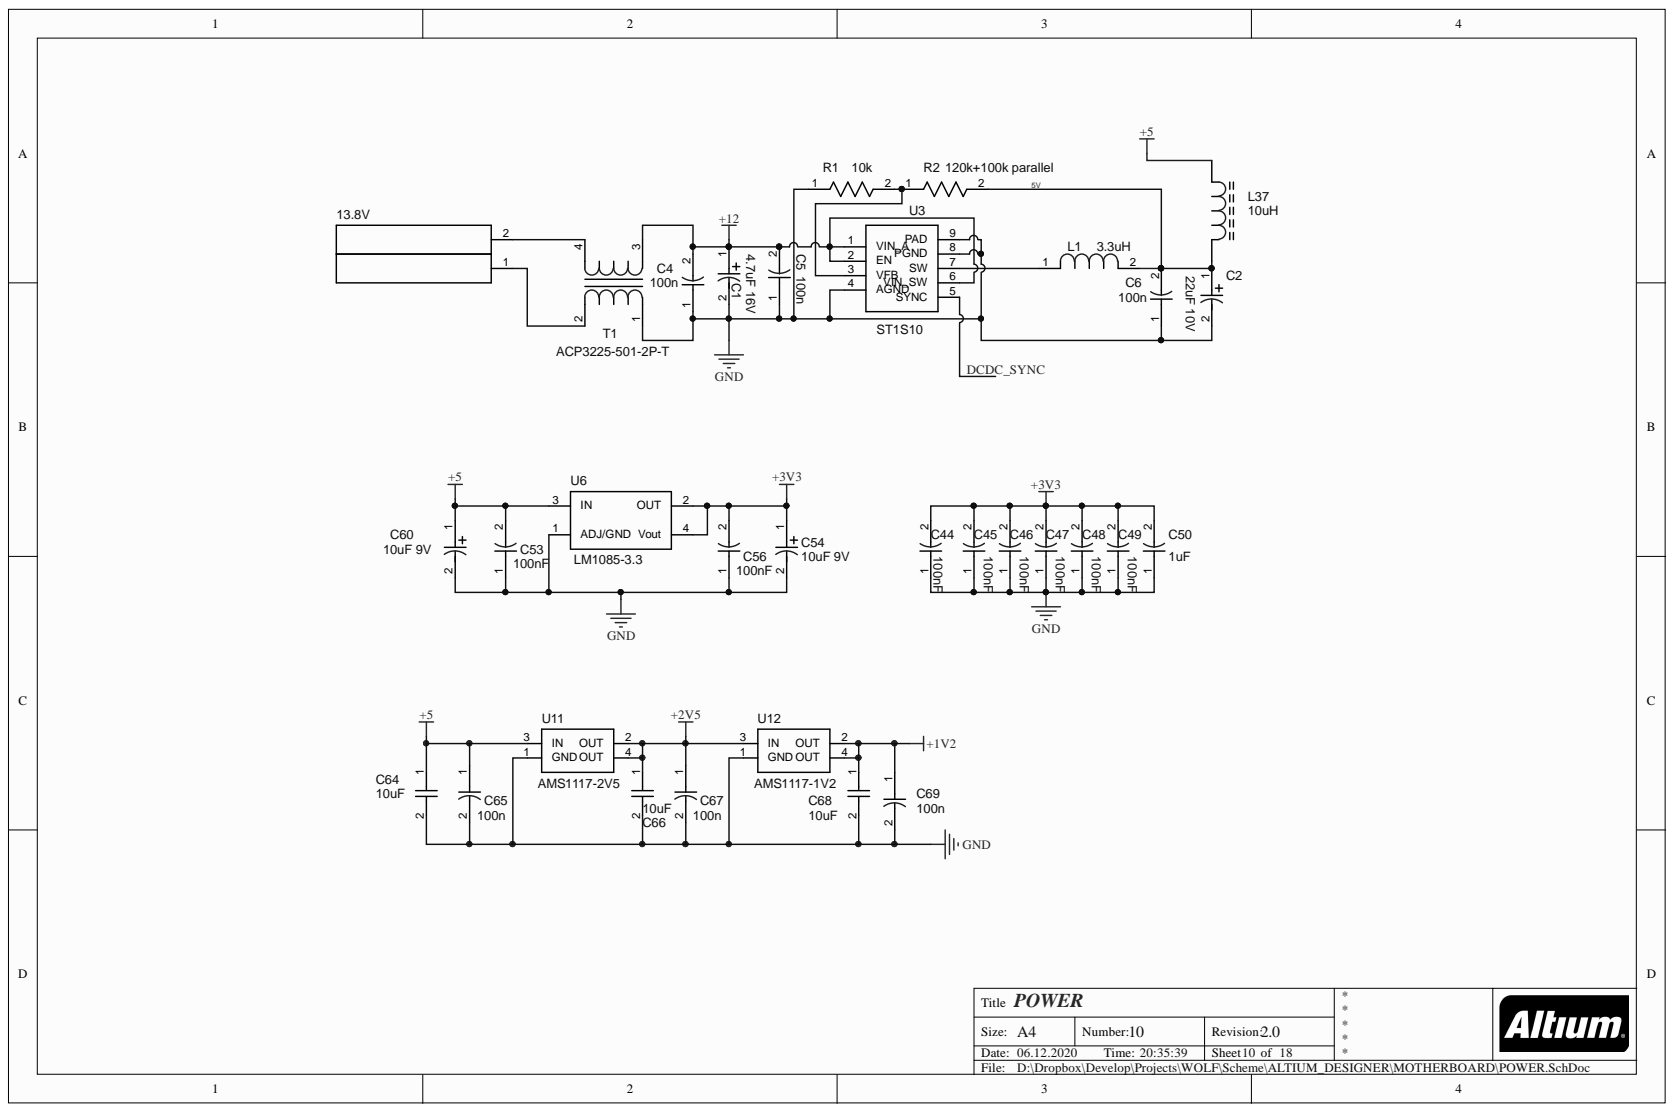
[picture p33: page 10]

POWER Title | * *

Size: A4 | Number: 10 | Revision: 2.0

D:\Dropbox\Develop\Projects\WOLF\Scheme\ALTIUM_DESIGNER\MOTHERBOARD\POWER.SchDoc

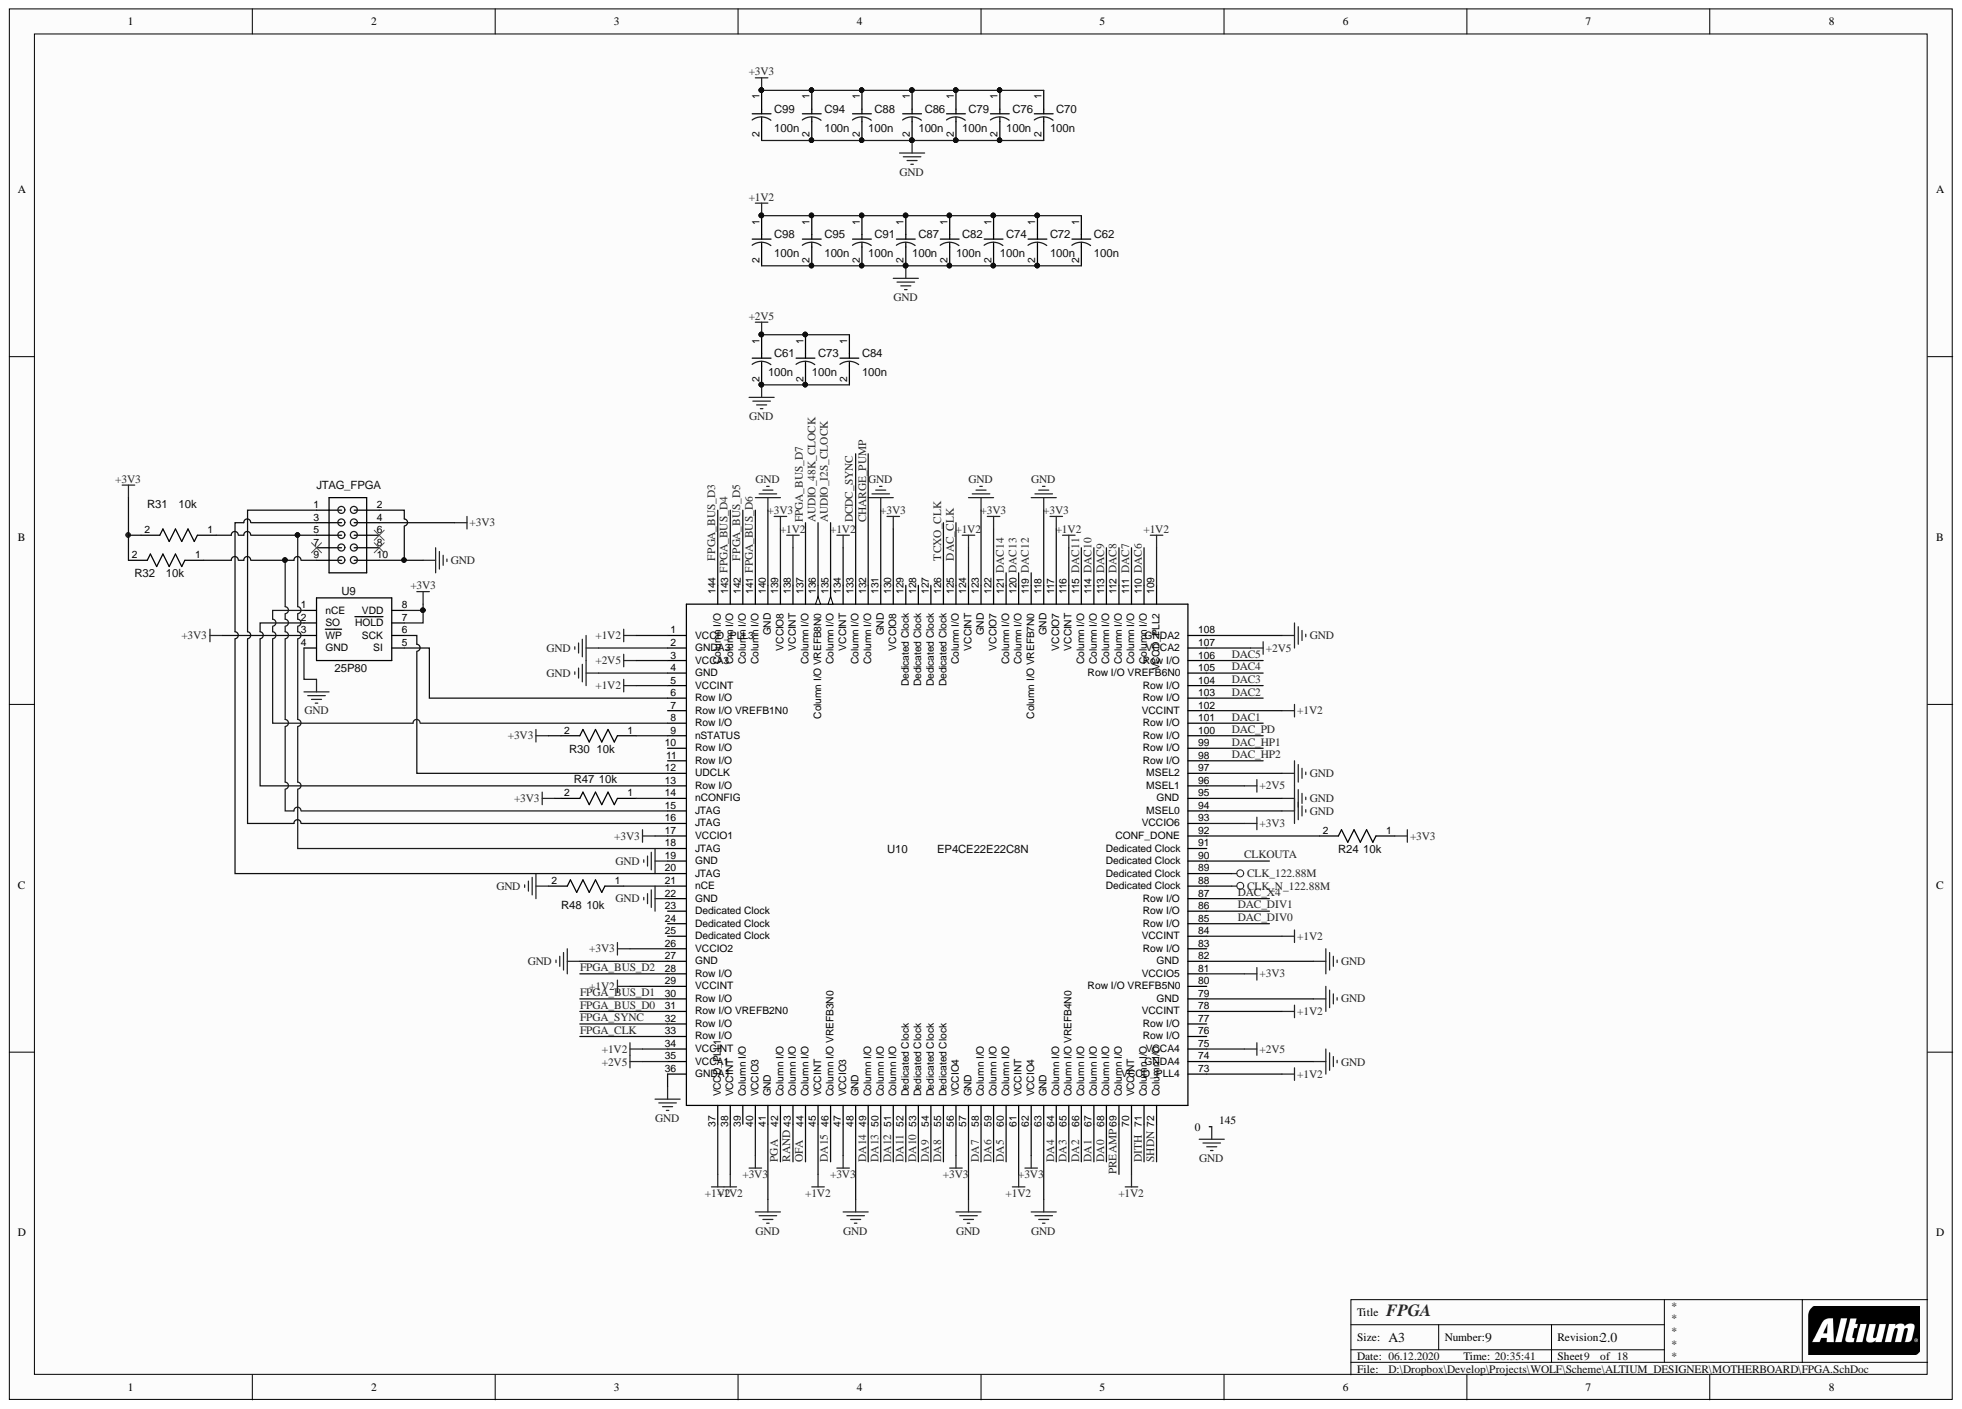
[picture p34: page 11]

GND

+2V5 | DAC5

Column I/O 72 Column I/O 71 VCCINT 70 Column I/O 69 Column I/O 68 Column I/O 67 Column I/O 66 Column I/O VREFB4N0 65 Column I/O 64 GND 63 VCCIO4 62 VCCINT 61 Column I/O 60 Column I/O 59 Column I/O 58 GND 57 VCCIO4 56 Dedicated Clock 55 Dedicated Clock 54 Dedicated Clock 53 Dedicated Clock 52 Column I/O 51 Column I/O 50 Column I/O 49 GND 48 VCCIO3 47 Column I/O VREFB3N0 46 VCCINT 45 Column I/O 44 Column I/O 43 Column I/O 42 GND 41 VCCIO3 40 Column I/O 39 VCCINT 38 VCCD_PLL1 37

FPGA Title

Size: A3 | Number: 9 | Revision: 2.0

D:\Dropbox\Develop\Projects\WOLF\Scheme\ALTIUM_DESIGNER\MOTHERBOARD\FPGA.SchDoc

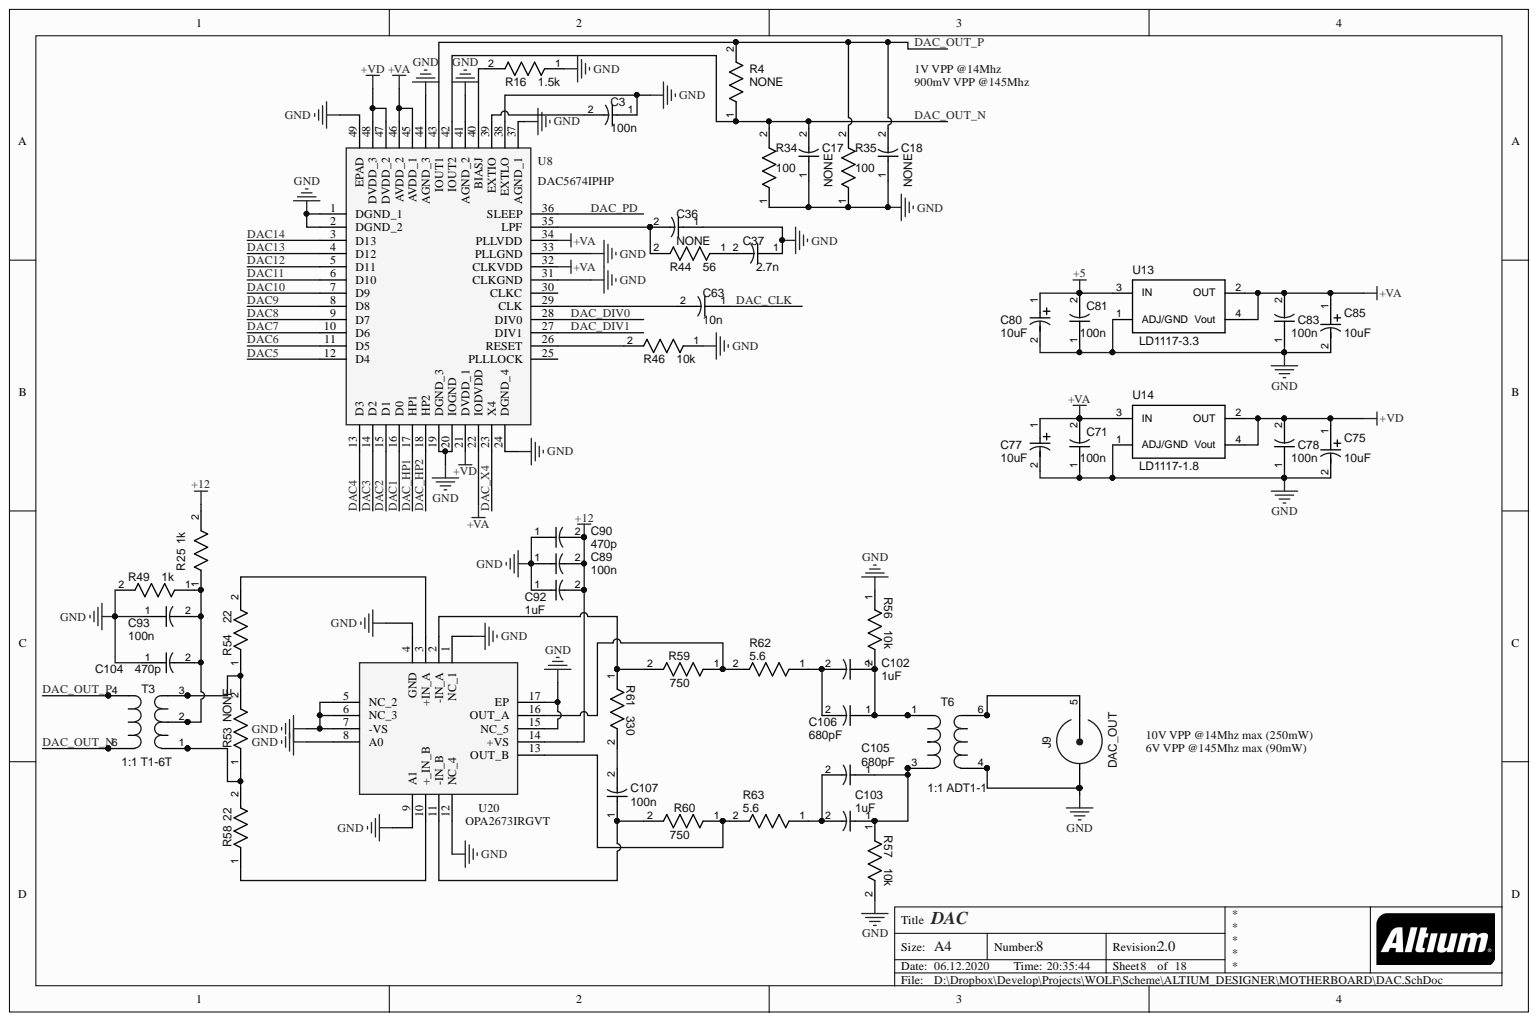
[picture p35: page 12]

6 | | 1 6
7 | | 1 5
8 | | 1 4

DAC T i t l e | ****

Size: A4 | N umber: 8 | Rev i s i o n : 2.0

6.1 2.2 T ime: : : | | Sheet o f


4 5
4 6
4 7

Size: A4 | N umber: | Rev i s i o n : 2.0

6.1 2.2 T ime: : : | | Sheet o f


EN 2
GND 3

12.288Mhz TCXO 3.3v TTL/CMOS (set other freq in fpga code)

CLOCK_GENERATOR Title | * *

Size: A4 | Number: 6 | Revision: 2.0

D:\Dropbox\Develop\Projects\WOLF\Scheme\ALTIUM_DESIGNER\MOTHERBOARD\CLOCK_GENERATOR.SchDoc


DACLRC 5

ADCLRC 7

LHPOUT 9

RHPOUT 10

NC -OUT_R PVDD | 9 VREF 8 14

INL 7 VDD 6 MUTE 5 PVDD 4 -OUT_L 3 PGND 2 +OUT_L 1 | 13

SHND GND | 12 | C15
11
INR | 10

AUDIO CODEC Title | * *

Size: A4 | Number: 5 | Revision: 2.0

D:\Dropbox\Develop\Projects\WOLF\Scheme\ALTIUM_DESIGNER\MOTHERBOARD\AUDIO CODEC.SchDoc

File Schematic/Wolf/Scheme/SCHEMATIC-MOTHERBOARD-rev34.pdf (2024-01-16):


C:\Dropbox\Develop\Projects\WOLF\Schematic\Wolf\Altium_Designer\MOTHERBOARD\MOTHERBOARD.SCHDOC


V-V + V + V-V + E P | 4

3 | 1 2
1 0 | 1 7


ADCLRC 7

LHPOUT 9

RHPOUT 10

HPGND 11 MICBIAS VMID AGND | 15 AVDD 14

LOUT 12 | 17

ROUT 13 | 16

MODE PGND -OUT_R | 9 VREF 8 15

INL 7 VDD 6 MUTE 5 PVDD 4 -OUT_L 3 PGND 2 +OUT_L 1 | 14

PVDD SHND | 13 12

C:\Dropbox\Develop\Projects\WOLF\Schematic\Wolf\Altium_Designer\MOTHERBOARD\AUDIO CODEC.SchDoc


Vcont 1
GND 3 EN 2

12.288Mhz TCXO 3.3v TTL/CMOS (set other freq in fpga code)

C:\Dropbox\Develop\Projects\WOLF\Schematic\Wolf\Altium_Designer\MOTHERBOARD\CLOCK_GENERATOR.SchDoc


C:\Dropbox\Develop\Projects\WOLF\Schematic\Wolf\Altium_Designer\MOTHERBOARD\CONNECTIONS.SchDoc


C:\Dropbox\Develop\Projects\WOLF\Schematic\Wolf\Altium_Designer\MOTHERBOARD\DAC.SchDoc


Column I/O 72 Column I/O 71 VCCINT 70 Column I/O 69 Column I/O 68 Column I/O 67 Column I/O 66 Column I/O VREFB4N0 65 Column I/O 64 GND 63 VCCIO4 62 VCCINT 61 Column I/O 60 Column I/O 59 Column I/O 58 GND 57 VCCIO4 56 Dedicated Clock 55 Dedicated Clock 54 Dedicated Clock 53 Dedicated Clock 52 Column I/O 51 Column I/O 50 Column I/O 49 GND 48 VCCIO3 47 Column I/O VREFB3N0 46 VCCINT 45 Column I/O 44 Column I/O 43 Column I/O 42 GND 41 VCCIO3 40 Column I/O 39 VCCINT 38 VCCD_PLL1 37

C:\Dropbox\Develop\Projects\WOLF\Schematic\Wolf\Altium_Designer\MOTHERBOARD\FPGA.SchDoc


C:\Dropbox\Develop\Projects\WOLF\Schematic\Wolf\Altium_Designer\MOTHERBOARD\POWER.SchDoc


Цепь | Конт.

C:\Dropbox\Develop\Projects\WOLF\Schematic\Wolf\Altium_Designer\MOTHERBOARD\STM32.SchDoc

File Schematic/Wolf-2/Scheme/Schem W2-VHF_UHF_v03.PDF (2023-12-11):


C9 100n | ATT4 | ATT8 | ATT16

Инв. № подл. Инв. № дубл. Подп. и дата Взам. инв. № Подп. и дата

Wolf-2 VHF/UHF Connector


Конт. | Цепь

Инв. № подл. Инв. № дубл. Подп. и дата Взам. инв. № Подп. и дата


Конт. | Цепь

OUT 4 GND 5 RA1 VHF Module

Инв. № подл. Инв. № дубл. Подп. и дата Взам. инв. № Подп. и дата

Comment | Description | Designator | Footprint | LibRef | Quantity
10n | | C1, C8, C11, C12, C25, C39, C41, C43, C48, C61, C71, C80, C86, C104 | CH0805C | Capacitor | 14
100n | | C2, C3, C4, C5, C7, C9, C10, C14, C20, C21, C37, C38, C40, C42, C46, C47, C62, C64, C65, C67, C70, C72, C75, C76, C100, C105, C106, C109, C111 | CH0805C | Capacitor | 29
1uF | | C6, C44 | CH0805C | Capacitor | 2
2.2uF | | C13, C55 | CH0805C | Capacitor | 2
100p | | C15, C22, C28, C36, C49, C66, C79, C110 | CH0805C | Capacitor | 8
1n | | C16, C54 | CH0805C | Capacitor | 2
10uF | | C17, C73 | CH0805C | Capacitor | 2
220p | | C18, C56, C57, C58, C59 | CH0805C | Capacitor | 5
4.7uF | | C19, C45, C74 | CH0805C | Capacitor | 3
330p | | C23, C24 | CH0805C | Capacitor | 2
110p | | C26, C85 | CH0805C | Capacitor | 2
4.7n | | C27, C50, C68, C81, C107 | CH0805C | Capacitor | 5
15p | | C29, C30, C90, C91 | CH0805C | Capacitor | 4
56p | | C31, C87 | CH0805C | Capacitor | 2
39p | | C32, C33 | CH0805C | Capacitor | 2
68p | | C34, C88 | CH0805C | Capacitor | 2
3p | | C35, C53, C89 | CH0805C | Capacitor | 3
18p | | C51 | CH0805C | Capacitor | 1
27p | | C52 | CH0805C | Capacitor | 1
270pF | | C60 | CH1206ATC | Capacitor | 1
10uF | | C63, C99 | CH1206C | Capacitor | 2
0,47uF 16v | | C69, C108 | TANTAL_B | TantalCap | 2
20p | | C77, C78, C93, C94 | CH0805C | Capacitor | 4
82p | | C82, C83, C84, C101, C102, C103 | CH0805C | Capacitor | 6
470pF | | C92 | CH1206ATC | Capacitor | 1
30pF | | C95 | CH1206ATC | Capacitor | 1
36pF | | C96 | CH1206ATC | Capacitor | 1
47pF | | C97 | CH1206ATC | Capacitor | 1
22pF | | C98 | CH1206ATC | Capacitor | 1
PE4312 / PE4302 | | D1 | 20-QFN (4x4) | PE4312-№1 | 1
BAV99 | | D2, D3, D4 | SOT23_132 | BAV99 | 3
SN74LS145DR | | DA1 | 16-SOIC | SN74LS145N | 1
BLM21 | | FB1, FB2 | CH0805L | FB-1 | 2
IM06 | | K1, K2, K3, K5, K6, K7, K9, K10, K11 | IM06 | IM06-V1 | 9
IM06-12v | | K4 | IM06 | IM06-V1 | 1
G6S-2-DC12 | | K8, K12 | G6S-2-DC12 | G6S-2-12VDC | 2
150nH | | L1 | CH1210L | Inductor | 1
1uH | | L2, L11 | CH1210L | Inductor | 2
18 nH | | L3 | CH1210L | Inductor | 1
22nH | | L4, L18 | CH1206L | Inductor | 2
180nH | | L5, L6, L7, L9, L19, L20 | CH1206L | Inductor | 6
82nH | | L8 | CH1206L | Inductor | 1
12 nH | | L10 | CH1210L | Inductor | 1
82nH | | L12 | CH1210L | Inductor | 1
12nH | | L13, L15, L24, L26 | CH1206L | Inductor | 4
10nH | | L14, L25 | CH1206L | Inductor | 2
22 nH | | L16 | CH1210L | Inductor | 1
10uH | | L17 | CH1210L | Inductor | 1
0.047uH | | L21, L22, L23 | T50-6 | Inductor ring | 3
LP3878MR-ADJ | LP3878-ADJ HSOP-8 | LP1, LP2, LP3 | SOP-8 gnd | LP3878-ADJ | 3
PAW-145M2 | PAW-A022-145M2 | PAW-1 | PAW-145M2 | PAW-145M2 | 1
10k | | R1, R12, R19, R22, R37, R53 | CH0805R | Resistor | 6
4.7k | | R2, R13, R18, R23, R26, R30, R38, R48, R49, R54, R69, R70 | CH0805R | Resistor | 12
620 | | R3, R39, R50, R55, R73 | CH0805R | Resistor | 5
33 | | R4 | CH0805R | Resistor | 1
18 | | R5, R56 | CH2010R | Resistor | 2
180 | | R6, R7 | CH0805R | Resistor | 2
10K | | R8, R41, R57 | CH2010R | Resistor | 3
18 | | R9, R42, R58 | CH0805R | Resistor | 3
300 | | R10, R11, R43, R44, R59, R60 | CH0805R | Resistor | 6
3.3K | | R14, R15, R29 | CH0805R | Resistor | 3
3K | | R16, R20, R24, R27, R31 | CH0805R | Resistor | 5
30k | | R17, R21, R25, R28, R32 | CH0805R | Resistor | 5
0 | | R33, R34, R35, R36, R61, R62, R63, R64, R65 | CH1206R | Resistor | 9
12 | | R40 | CH2010R | Resistor | 1
51R | | R45, R66 | CH1206R | Resistor | 2
5.1k | | R46, R47, R67, R68 | CH0805R | Resistor | 4
100 | | R51, R71 | CH0805R | Resistor | 2
10k | | R52, R72 | RES: 3296W | ADJ resistor | 2
VHF Module | RA80H | RA1 | RA80H | RA80H | 1
VHF RA60H1317 | RA80H | RA2 | RA80H | RA80H | 1
SWR | SWR_VHF | SWR1, SWR2 | SWR_VHF | SWR_VHF | 2
TAU692 433MHz | TAU692 433MHz | TAU1, TAU2 | TAU-692 433 MHz | TAU692 433MHz | 2
1117-5.0 | LT1117CST-5.0 | U1, U3 | LT1117CST-3.3 | LT1117CST-3.3 | 2
1117-ADJ | LT1117CST-ADJ | U2, U4 | LT1117CST-3.3 | LT1117CST-3.3 | 2
SS14 | | VD1, VD2, VD3, VD4, VD5, VD6, VD7 | SMA | Diod Schottky | 7
LED BLUE | | VD8, VD9, VD10, VD11, VD12 | LED: 0805B | LED_single | 5
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

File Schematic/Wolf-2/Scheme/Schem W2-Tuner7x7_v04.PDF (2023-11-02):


Инв. № подл. Инв. № дубл. Подп. и дата Взам. инв. № Подп. и дата

W2-Tuner_Con t r o l | Лист1

Изм . | Лист | № докум . | Подп . | Да т а


Инв. № подл. Инв. № дубл. Подп. и дата Взам. инв. № Подп. и дата Перв. примен. Справ. №


Comment | Description | Designator | Footprint | LibRef | Quantity
470p | | C1, C7 | CH0805C | Capacitor | 2
1uF | | C2, C8, C15 | CH0805C | Capacitor | 3
100n | | C3, C4, C5, C6, C14, C17, C18, C19, C20, C28, C29, C30, C31, C32, C33, C34, C35, C36, C37 | CH0805C | Capacitor | 19
10p | | C21 | CH1206ATC | Capacitor | 1
22p | | C22 | CH1206ATC | Capacitor | 1
47p | | C23 | CH1206ATC | Capacitor | 1
100p | | C24 | CH1206ATC | Capacitor | 1
220p | | C25 | CH1206ATC | Capacitor | 1
470p | | C26 | CH1206ATC | Capacitor | 1
1000p | | C27 | CH1206ATC | Capacitor | 1
AMS1117-5v | LDO | D1 | SOT223 | NCP1117LPST50T3G | 1
BLM21 | | FB1, FB2, FB3 | CH0805L | FB-1 | 3
HK4100F | | K1, K2, K3, K5, K13, K14, K15 | NK4100F | NK4100F | 7
G6S-2-DC12 | | K4, K16 | G6S-2-DC12 | G6S-2-12VDC | 2
HF49FD | | K6, K7, K8, K9, K10, K11, K12 | HF49FD | HF49FD 012-1H12 | 7
0.05uH | | L1 | DR1 | Inductor ring | 1
0.1uH | | L2 | DR1 | Inductor ring | 1
0.22uH | | L3 | DR1 | Inductor ring | 1
0.45uH | | L4 | T68-0 | Inductor ring | 1
1uH | | L5 | T68-0 | Inductor ring | 1
2.2uH | | L6 | T68-0 | Inductor ring | 1
4.4uH | | L7 | T68-0 | Inductor ring | 1
4.7K | | R1, R2, R3, R4, R6, R8, R10, R12, R16, R18, R21, R23, R25, R29, R31, R35 | CH0805R | Resistor | 16
30k | | R5, R7, R9, R11, R14, R17, R19, R22, R24, R27, R30, R32, R34, R36 | CH0805R | Resistor | 14
1k | | R13, R20, R26, R33 | CAT16 | CAT10-0804 | 4
STPIC6C595TTR | | U1, U2 | 16-TSOP | STPIC6C595TTR | 2
LED BLUE | | VD1, VD2, VD3, VD4, VD5, VD6, VD7, VD8, VD9, VD10, VD11, VD12, VD13, VD14, VD15, VD16 | LED: 0805B | LED_single | 16
1N4148W | | VD17, VD18, VD19, VD20, VD21, VD22, VD23, VD24, VD25, VD26, VD27, VD28, VD29, VD30, VD31, VD32 | SOD123 | Diod | 16
IRLML9301 | Mosfet | VT1, VT2, VT3, VT4, VT5, VT6, VT7, VT8, VT9, VT10, VT11, VT12, VT13, VT14 | SOT23_132 | IRLML9301 | 14
MainBoard | 2*5 Pin | X1 | CON: BH-10 | IDC10 | 1
IN_TUNER | RF | X2 | CON: SMA | SMA | 1
ANT1 | RF | X3 | CON: SMA | SMA | 1
ANT2 | RF | X4 | CON: SMA | SMA | 1

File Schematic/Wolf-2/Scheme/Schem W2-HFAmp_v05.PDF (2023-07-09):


Инв. № подл. Инв. № дубл. Подп. и дата Взам. инв. № Подп. и дата

Wolf2 - HF Amp - Control | Лист1

Изм . | Лист | № докум . | Подп . | Да т а


Инв. № подл. Инв. № дубл. Подп. и дата Взам. инв. № Подп. и дата

Wolf2 - HF Amp - Amp

Изм. | Лист | № докум. | Подп. | Дата


+LPF_ | 9

Инв. № подл. Инв. № дубл. Подп. и дата Взам. инв. № Подп. и дата

+LPF_ | 9 | | 43

100n GNDGN 9 | 43

W2 - HF AMP - LPF | Лист3

Изм . | № докум . | Подп . | Да т а


Comment | Description | Designator | Footprint | LibRef | Quantity
2000 uF 25v | | C1 | D13C5H20 | AlumCap | | 1
470p | | C2, C8, C13 | CH0805C | Capacitor | | 3
1uF | | C3, C9, C14, C46, C49 | CH0805C | Capacitor | | 5
100n | | C4, C5, C6, C7, C10, C11, C12, C19, C24, C31, C32, C33, C34, C35, C37, C38, C39, C44, C45, C47, C48, C67, C75, C82, C88, C94, C101, C107 | CH0805C | Capacitor | 28
10n | | C15, C29 | CH1210C | Capacitor | | 2
68p | | C16, C28 | CH0805C | Capacitor | | 2
4.7n | | C17 | CH0805C | Capacitor | | 1
1n | | C18, C23 | CH1210C | Capacitor | | 2
15n | | C20, C25 | CH1206C | Capacitor | | 2
100p* | | C21 | CH1210C | Capacitor | | 1
200p* | | C22 | CH1812C | Capacitor | | 1
27p | | C26 | CH0805C | Capacitor | | 1
2.2uF | | C27 | CH1206C | Capacitor | | 1
1n5 | | C30 | CH1206C | Capacitor | | 1
1n | | C36 | CH0805C | Capacitor | | 1
15n | | C40, C41, C42, C43 | CH0805C | Capacitor | | 4
68p* | | C50, C57 | CH1206ATC | Capacitor | | 2
100n | | C51, C58 | CH1210C | Capacitor | | 2
100p | | C52 | CH1812C | Capacitor | | 1
470p* | | C53 | CH1812C | Capacitor | | 1
470p | | C54 | CH1206C | Capacitor | | 1
10n | | C55 | CH1206C | Capacitor | | 1
100n | | C56, C59, C60, C73, C74, C81 | CH1206C | Capacitor | | 6
1n | | C61 | CH1206C | Capacitor | | 1
10p | | C62, C63 | CH1206ATC | Capacitor | | 2
22p | | C64, C66, C68, C69 | CH1206ATC | Capacitor | | 4
47p | | C65 | CH1206ATC | Capacitor | | 1
68p | | C70, C72, C83, C84 | CH1206ATC | Capacitor | | 4
120p | | C71 | CH1206ATC | Capacitor | | 1
33p | | C76, C77 | CH1206ATC | Capacitor | | 2
100p | | C78, C80, C89, C90 | CH1206ATC | Capacitor | | 4
200p | | C79 | CH1206ATC | Capacitor | | 1
180p | | C85, C87 | CH1206ATC | Capacitor | | 2
390p | | C86, C91, C93 | CH1206ATC | Capacitor | | 3
680p | | C92, C97, C100 | CH1206ATC | Capacitor | | 3
150p | | C95, C96 | CH1206ATC | Capacitor | | 2
1n | | C98, C104, C105, C106 | CH1206ATC | Capacitor | | 4
200pF | | C99 | CH1206ATC | Capacitor | | 1
220p | | C102, C103 | CH1206ATC | Capacitor | | 2
BAV99 | | D1 | SOT23_132 | BAV99 | | 1
SN74LS145DR | | DA1 | 16-SOP | SN74LS145N | | 1
BLM21 | | FB1, FB2 | CH0805L | FB-1 | | 2
Jumper_2 | Jumper | JMP1, JMP2 | CON: JUMPER_2 | Jumper_2 | | 2
G6S-2-DC12 | | K1, K2, K3, K4, K5, K6, K7, K8, K9, K10, K11, K12, K13, K14, K15 | G6S-2-DC12 | G6S-2-12VDC | 15
0,022uH | | L1 | CH1210L | Inductor-2 | | 1
10uH | | L2, L3 | IND: R24 | Inductor ring | | 2
0.06uH | | L4, L5 | DR1 | Inductor ring | | 2
0.15uH | | L6, L7 | DR1 | Inductor ring | | 2
0.3uH | | L8, L9 | T68-0 | Inductor ring | | 2
0.6uH | | L10, L11 | T68-0 | Inductor ring | | 2
1.15uH | | L12, L13 | T68-0 | Inductor ring | | 2
2.3uH | | L14, L15 | T68-0 | Inductor ring | | 2
4.5uH | | L16, L17 | T68-0 | Inductor ring | | 2
4.7K | | R1, R4, R9, R12, R15, R18, R21, R24 | CH0805R | Resistor | | 8
3K | | R2, R6, R10, R13, R16, R19, R22 | CH0805R | Resistor | | 7
30k | | R3, R7, R11, R14, R17, R20, R23 | CH0805R | Resistor | | 7
560 | | R5 | CAT16 | CAT10-0804 | | 1
1K KTY81/110 | | R8 | CON: PBS-2 | NTC | | 1
2K | | R25, R47 | CH2512R | Resistor | | 2
4.7 | | R26, R27, R42, R44, R50, R51, R54, R69, R71, R72 | CH2512R | Resistor | 10
100 | | R28, R43, R59, R61 | CH0805R | Resistor | | 4
47 | | R29, R31, R41, R45 | CH0805R | Resistor | | 4
750* | | R30, R37 | CH1206R | Resistor | | 2
10 | | R32, R75, R76 | CH0805R | Resistor | | 3
68 | | R33 | CH0805R | Resistor | | 1
1K | | R34, R36 | CH0805R | Resistor | | 2
100 | | R35 | CH2512R | Resistor | | 1
10K NTC | | R38 | CON: PBS-2 | NTC | | 1
91 | | R39, R40 | CH0805R | Resistor | | 2
10K | | R46, R55, R56, R57, R58 | RES: 3296W | ADJ resistor | | 5
330 | | R48, R49 | CH0805R | Resistor | | 2
750 | | R52, R53 | CH0805R | Resistor | | 2
620 | | R60, R62 | CH0805R | Resistor | | 2
22 | | R63, R67, R68, R70 | CH2512R | Resistor | | 4
1.5k | | R64, R65, R66 | R-DIP | Resistor | | 3
51 | | R73, R74 | CH1206R | Resistor | | 2
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

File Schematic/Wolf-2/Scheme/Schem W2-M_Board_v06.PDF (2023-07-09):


Инв. № подл. Инв. № дубл. Подп. и дата Взам. инв. № Подп. и дата Перв. примен. Справ. №

Конт. | Цепь

JTAG_9 | 7 | 8

24
25
26

Т.контр. | | Лист | Листов 7
* | | Wolf Teams

Н.контр.

Утв. | UA3REO


Инв. № подл. Инв. № дубл. Подп. и дата Взам. инв. № Подп. и дата Перв. примен. Справ. №

Column I/O 72 Column I/O 71 VCCINT 70 Column I/O 69 Column I/O 68 Column I/O 67 Column I/O 66 Column I/O VREFB4N0 65 Column I/O 64 GND 63 VCCIO4 62 VCCINT 61 Column I/O 60 Column I/O 59 Column I/O 58 GND 57 VCCIO4 56 Dedicated Clock 55 Dedicated Clock 54 Dedicated Clock 53 Dedicated Clock 52 Column I/O 51 Column I/O 50 Column I/O 49 GND 48 VCCIO3 47 Column I/O VREFB3N0 46 VCCINT 45 Column I/O 44 Column I/O 43 Column I/O 42 GND 41 VCCIO3 40 Column I/O 39 VCCINT 38 VCCD_PLL1 37

Wolf2 MainBoard FPGA

* | Лит. | Масса | Масштаб

Изм. | Лист | № докум. | Подп. | Дата

Разраб. | | RU4PN

Пров. | | UA3REO


Инв. № подл. Инв. № дубл. Подп. и дата Взам. инв. № Подп. и дата Перв. примен. Справ. №

+3V3ATT C61 +3V3RF

ADJ/GND 1

Wolf2 MainBoard Power

* | Лит. | Масса | Масштаб

Изм. | Лист | № докум. | Подп. | Дата

Разраб. | | RU4PN

Пров. | | UA3REO


Инв. № подл. Инв. № дубл. Подп. и дата Взам. инв. № Подп. и дата Перв. примен. Справ. №

Vdd 15 | 4 3

Vdd 16 | 4 4

Vdd 17 | 4 5

U12 LTC6400IU V+ V+ I N | VOCM O U T O U T F O U T O U T F V-V-V-

Wolf2 MainBoard ADC

* | Лит . | Масса | Масшта б

. Лист Р азра б . | R U 4 P N

Изм . | № докум . | Подп . | Да т а

Пров . | UA3REO

Т .контр | | | | Лист | Листов

Н .контр .

Утв .


Инв. № подл. Инв. № дубл. Подп. и дата Взам. инв. № Подп. и дата Перв. примен. Справ. №

Wolf2 MainBoard DAC

* | Лит . | Масса | Масшта б

. Лист Р азра б . | R U 4 P N

Изм . | № докум . | Подп . | Да т а

Пров . | UA3REO

Т .контр | | | | Лист | Листов

Н .контр .

Утв .


Инв. № подл. Инв. № дубл. Подп. и дата Взам. инв. № Подп. и дата Перв. примен. Справ. №

Wolf2 MainBoard RF

* | Лит. | Масса | Масштаб

Изм. | Лист | № докум. | Подп. | Дата

Разраб. | | RU4PN

Пров. | | UA3REO


30k

Инв. № подл. Инв. № дубл. Подп. и дата Взам. инв. № Подп. и дата Перв. примен. Справ. №

. Лист Р азра б . | R U 4 P N

Изм . | № докум . | Подп . | Да т а

Пров . | UA3REO

Т .контр | | | | Лист | Листов

Н .контр .

Утв .

Comment | Description | Designator | Footprint | LibRef | Quantity
100n | [NoValue], CAP_0805
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

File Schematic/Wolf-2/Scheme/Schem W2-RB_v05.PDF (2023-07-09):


Инв. № подл. Инв. № дубл. Подп. и дата Взам. инв. № Подп. и дата Перв. примен. Справ. №

Конт. | Цепь | Цепь | Конт.

Конт. | Цепь

R_BOARD - Connectors

* | Лит. | Масса | Масштаб

Изм. | Лист | № докум. | Подп. | Дата

Разраб. | | RU4PN

Пров. | | *

Т.контр. | | | | | Лист | Листов 3
* | | | | | Wolf-2

Н.контр.

Утв. | UA3REO


Инв. № подл. Инв. № дубл. Подп. и дата Взам. инв. № Подп. и дата Перв. примен. Справ. №

Конт. | Цепь

Alert 3

SCL 5

R_BOARD - Power

* | Лит. | Масса | Масштаб

Изм. | Лист | № докум. | Подп. | Дата


Инв. № подл. Инв. № дубл. Подп. и дата Взам. инв. № Подп. и дата Перв. примен. Справ. №

InR 9

AGND 8

R_BOARD - Audio

* | Лит. | Масса | Масштаб

Изм. | Лист | № докум. | Подп. | Дата

Разраб. | | RU4PN

Пров. | | *

Line # | Name | Description | Designator | Quantity | Manufacturer 1 | Manufacturer Part Number 1 | Manufacturer Lifecycle 1 | Supplier 1 | Supplier Part Number 1 | Supplier Unit Price 1 | Supplier Subtotal 1
| 1000uF 25v | | C1, C14, C19 | 3
| 100n | | C2, C3, C4, C6, C7, C8, C10, C12, C13, C20, C21, C25 | 12
| 1uF | | C5, C15, C18, C23, C24 | 5
| 10uF | | C9 | 1
| 22uF 25V | | C11 | 1
| 10uF 16v | | C16 | 1
| 100uF 16v | | C17 | 1
| 100uF 16v | | C22 | 1
| AMS1117-3.3v | LDO | D1 | 1
| INA226 | | DA1 | 1
| BLM21 | | FB1, FB2, FB3, FB4 | 4
| PJ-307 | KEY | J1 | 1
| PJ-307 | LIN | J2 | 1
| PJ-307 | OUT_SPEAKERS | J3 | 1
| PJ-307 | PTT_IN | J4 | 1
| PJ-307 | TX | J5 | 1
| HF49FD | | K1 | 1
| 5.6k | | R1, R20 | 2
| 24R | | R2, R3, R4, R5 | 4
| 1M / 0 | | R6 | 1
| NONE / 24R | | R7, R8 | 2
| 4x0.1R | | R9 | 1
| 0 | | R10, R11 | 2
| 22R | | R12, R13 | 2
| 10k | | R14, R15, R16, R17, R30, R31 | 6
| 39k | | R18 | 1
| 1k | | R19 | 1
| 30k | | R21, R24, R37, R38 | 4
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

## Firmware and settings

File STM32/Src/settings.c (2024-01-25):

#include "settings.h"
#include "atu.h"
#include "audio_filters.h"
#include "bands.h"
#include "fpga.h"
#include "front_unit.h"
#include "functions.h"
#include "hardware.h"
#include "lcd.h"
#include "main.h"
#include "trx_manager.h"
#include <assert.h>
#include <stdio.h>
#include <stdlib.h>

// W25Q16
IRAM2 static uint8_t Write_Enable = W25Q16_COMMAND_Write_Enable;
IRAM2 static uint8_t Power_Down = W25Q16_COMMAND_Power_Down;
IRAM2 static uint8_t Get_Status = W25Q16_COMMAND_GetStatus;
IRAM2 static uint8_t Power_Up = W25Q16_COMMAND_Power_Up;

IRAM2 static uint8_t CmdAddress[4];
IRAM2_ON_F407 struct TRX_SETTINGS TRX;
IRAM2_ON_F407 struct TRX_CALIBRATE CALIBRATE = {0};
IRAM2_ON_F407 struct TRX_WIFI WIFI = {0};
bool EEPROM_Enabled = true;

#define MAX_CLONE_SIZE_SETTINGS sizeof(CALIBRATE) > sizeof(TRX) ? sizeof(CALIBRATE) : sizeof(TRX)
#define MAX_CLONE_SIZE sizeof(ATU_MEMORY_TYPE) > MAX_CLONE_SIZE_SETTINGS ? sizeof(ATU_MEMORY_TYPE) : MAX_CLONE_SIZE_SETTINGS

static_assert(sizeof(TRX) < W25Q16_SECTOR_SIZE, "TRX Data structure doesn't match page size");
static_assert(sizeof(CALIBRATE) < W25Q16_SECTOR_SIZE, "CALIBRATE Data structure doesn't match page size");
static_assert(sizeof(ATU_MEMORY_TYPE) < W25Q16_SECTOR_SIZE, "ATU_MEMORY_TYPE Data structure doesn't match page size");

IRAM2 static uint8_t verify_clone[MAX_CLONE_SIZE] = {0};

volatile bool NeedSaveSettings = false;
volatile bool NeedSaveCalibration = false;
volatile bool NeedSaveWiFi = false;
volatile bool EEPROM_Busy = false;
VFO *CurrentVFO = &TRX.VFO_A;
VFO *SecondaryVFO = &TRX.VFO_B;

static void LoadSettingsFromEEPROM(void);
static bool EEPROM_Sector_Erase(uint8_t sector, bool force);
static bool EEPROM_Write_Data(uint8_t *Buffer, uint16_t size, uint8_t sector, bool verify, bool force);
static bool EEPROM_Read_Data(uint8_t *Buffer, uint16_t size, uint8_t sector, bool verif, bool force);
static void EEPROM_PowerDown(void);
static void EEPROM_PowerUp(void);
static void EEPROM_WaitWrite(void);
static uint8_t calculateCSUM(void);
static uint8_t calculateCSUM_EEPROM(void);
static uint8_t calculateCSUM_WIFI(void);

const char *MODE_DESCR[TRX_MODE_COUNT] = {
    "LSB", "USB", "CW", "NFM", "WFM", "AM", "SAM", "AM-L", "AM-U", "DIGL", "DIGU", "IQ", "LOOP", "RTTY",
};

void LoadSettings(bool clear) {
	BKPSRAM_Enable();
	memcpy(&TRX, BACKUP_SRAM_BANK_ADDR, sizeof(TRX));
	// Check, the data in the backup sram is correct, otherwise we use the second bank
	if (TRX.ENDBit != 100 || TRX.flash_id != SETT_VERSION || TRX.csum != calculateCSUM()) {
		println("[ERR] BACKUP SRAM data incorrect");

		LoadSettingsFromEEPROM();
		if (TRX.ENDBit != 100 || TRX.flash_id != SETT_VERSION || TRX.csum != calculateCSUM()) {
			println("[ERR] EEPROM Settings data incorrect");
		} else {
			println("[OK] Settings data succesfully loaded from EEPROM");
		}
	} else {
		println("[OK] Settings data succesfully loaded from BACKUP SRAM");
	}
	BKPSRAM_Disable();
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

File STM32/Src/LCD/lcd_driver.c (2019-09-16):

//Header files
#include "lcd_driver.h"
#include "fonts.h"
#include "../settings.h"
#include "../functions.h"

extern DMA_HandleTypeDef hdma_memtomem_dma2_stream5;
extern SRAM_HandleTypeDef hsram1;
//static uint8_t rotationNum = 1;
static bool _cp437 = false;
uint32_t LCD_FSMC_COMM_ADDR = 0;
uint32_t LCD_FSMC_DATA_ADDR = 0;
static uint16_t text_cursor_y = 0;
static uint16_t text_cursor_x = 0;
static bool wrap = false;

//***** Functions prototypes *****//
//1. Write Command to LCD
void LCDDriver_SendCommand(uint16_t com)
{
	*(__IO uint16_t *)(LCD_FSMC_COMM_ADDR) = com;
}

//2. Write data to LCD
void LCDDriver_SendData(uint16_t data)
{
	*(__IO uint16_t *)(LCD_FSMC_DATA_ADDR) = data;
}

//3. Set cursor position
void LCDDriver_SetCursorAreaPosition(uint16_t x1, uint16_t y1, uint16_t x2, uint16_t y2)
{
#ifdef ILI9341
	LCDDriver_SendCommand(LCD_COMMAND_COLUMN_ADDR);
	LCDDriver_SendData(x1 >> 8);
	LCDDriver_SendData(x1 & 0xFF);
	LCDDriver_SendData(x2 >> 8);
	LCDDriver_SendData(x2 & 0xFF);
	LCDDriver_SendCommand(LCD_COMMAND_PAGE_ADDR);
	LCDDriver_SendData(y1 >> 8);
	LCDDriver_SendData(y1 & 0xFF);
	LCDDriver_SendData(y2 >> 8);
	LCDDriver_SendData(y2 & 0xFF);
	LCDDriver_SendCommand(LCD_COMMAND_GRAM);
#endif
#ifdef ILI9325
	LCDDriver_SendCommand(LCD_COMMAND_Horizontal_Address_Start_Position);
	LCDDriver_SendData(y1);
	LCDDriver_SendCommand(LCD_COMMAND_Horizontal_Address_End_Position);
	LCDDriver_SendData(y2);
	LCDDriver_SendCommand(LCD_COMMAND_Vertical_Address_Start_Position);
	LCDDriver_SendData(LCD_WIDTH - x2 - 1);
	LCDDriver_SendCommand(LCD_COMMAND_Vertical_Address_End_Position);
	LCDDriver_SendData(LCD_WIDTH - x1 - 1);
	LCDDriver_SetCursorPosition(x1, y1);
#endif
}

void LCDDriver_SetCursorPosition(uint16_t x, uint16_t y)
{
#ifdef ILI9341
	LCDDriver_SendCommand(LCD_COMMAND_COLUMN_ADDR);
	LCDDriver_SendData(x >> 8);
	LCDDriver_SendData(x & 0xFF);
	LCDDriver_SendData(x >> 8);
	LCDDriver_SendData(x & 0xFF);
	LCDDriver_SendCommand(LCD_COMMAND_PAGE_ADDR);
	LCDDriver_SendData(y >> 8);
	LCDDriver_SendData(y & 0xFF);
	LCDDriver_SendData(y >> 8);
	LCDDriver_SendData(y & 0xFF);
	LCDDriver_SendCommand(LCD_COMMAND_GRAM);
	text_cursor_y = y;
#endif
#ifdef ILI9325
	LCDDriver_SendCommand(LCD_COMMAND_Vertical_GRAM_Address_Set);
	LCDDriver_SendData(LCD_WIDTH - x - 1);
	LCDDriver_SendCommand(LCD_COMMAND_Horizontal_GRAM_Address_Set);
	LCDDriver_SendData(y);
	LCDDriver_SendCommand(LCD_COMMAND_Write_Data_to_GRAM);
#endif
	text_cursor_x = x;
}
uint16_t LCDDriver_GetCurrentXOffset(void)
{
	return text_cursor_x;
}
//4. Initialise function
void LCDDriver_Init(void)
{
	if (hsram1.Init.NSBank == FSMC_NORSRAM_BANK1) LCD_FSMC_COMM_ADDR = 0x60000000;
	if (hsram1.Init.NSBank == FSMC_NORSRAM_BANK2) LCD_FSMC_COMM_ADDR = 0x6a000000;
	if (hsram1.Init.NSBank == FSMC_NORSRAM_BANK3) LCD_FSMC_COMM_ADDR = 0x6b000000;
	if (hsram1.Init.NSBank == FSMC_NORSRAM_BANK4) LCD_FSMC_COMM_ADDR = 0x6c000000;
	LCD_FSMC_DATA_ADDR = LCD_FSMC_COMM_ADDR + (1 << (FSMC_REGISTER_SELECT + 1));

#ifdef ILI9341
	LCDDriver_SendCommand(LCD_COMMAND_RESET); // software reset comand
	HAL_Delay(100);
	LCDDriver_SendCommand(LCD_COMMAND_DISPLAY_OFF); // display off
	//------------power control------------------------------
	LCDDriver_SendCommand(LCD_COMMAND_POWER1); // power control
	LCDDriver_SendData(0x09); // GVDD = 3.3v
	LCDDriver_SendCommand(LCD_COMMAND_POWER2); // power control
	LCDDriver_SendData(0x10); // AVDD=VCIx2, VGH=VCIx7, VGL=-VCIx4
	//--------------VCOM-------------------------------------
	LCDDriver_SendCommand(LCD_COMMAND_VCOM1); // vcom control
	LCDDriver_SendData(0x18); // Set the VCOMH voltage (0x18 = 3.3v)
	LCDDriver_SendData(0x3e); // Set the VCOML voltage (0x3E = -0.950v)
	LCDDriver_SendCommand(LCD_COMMAND_VCOM2); // vcom control
	LCDDriver_SendData(0xbe);
	//------------memory access control------------------------
	LCDDriver_SendCommand(LCD_COMMAND_MAC); // memory access control
	LCDDriver_SendData(0x48);
	LCDDriver_SendCommand(LCD_COMMAND_PIXEL_FORMAT); // pixel format set
	LCDDriver_SendData(0x55); // 16bit /pixel
	LCDDriver_SendCommand(LCD_COMMAND_FRC);
	LCDDriver_SendData(0);
	LCDDriver_SendData(0x1F);
	//-------------ddram ----------------------------
	LCDDriver_SendCommand(LCD_COMMAND_COLUMN_ADDR); // column set
	LCDDriver_SendData(0x00); // x0_HIGH---0
	LCDDriver_SendData(0x00); // x0_LOW----0
	LCDDriver_SendData(0x00); // x1_HIGH---240
	LCDDriver_SendData(0xEF); // x1_LOW----240
	LCDDriver_SendCommand(LCD_COMMAND_PAGE_ADDR); // page address set
	LCDDriver_SendData(0x00); // y0_HIGH---0
	LCDDriver_SendData(0x00); // y0_LOW----0
	LCDDriver_SendData(0x01); // y1_HIGH---320
	LCDDriver_SendData(0x3F); // y1_LOW----320
	LCDDriver_SendCommand(LCD_COMMAND_TEARING_OFF); // tearing effect off
	LCDDriver_SendCommand(LCD_COMMAND_Entry_Mode_Set); // entry mode set
	// Deep Standby Mode: OFF
	// Set the output level of gate driver G1-G320: Normal display
	// Low voltage detection: Disable
	LCDDriver_SendData(0x07);
	//-----------------display------------------------
	LCDDriver_SendCommand(LCD_COMMAND_DFC); // display function control
	//Set the scan mode in non-display area
	//Determine source/VCOM output in a non-display area in the partial display mode
	LCDDriver_SendData(0x0a);
	//Select whether the liquid crystal type is normally white type or normally black type
	//Sets the direction of scan by the gate driver in the range determined by SCN and NL
	//Select the shift direction of outputs from the source driver
	//Sets the gate driver pin arrangement in combination with the GS bit to select the optimal scan mode for the module
	//Specify the scan cycle interval of gate driver in non-display area when PTG to select interval scan
	LCDDriver_SendData(0x82);
	// Sets the number of lines to drive the LCD at an interval of 8 lines
	LCDDriver_SendData(0x27);
	LCDDriver_SendData(0x00); // clock divisor
	LCDDriver_SendCommand(LCD_COMMAND_SLEEP_OUT); // sleep out
	HAL_Delay(100);
	LCDDriver_SendCommand(LCD_COMMAND_DISPLAY_ON); // display on
	HAL_Delay(100);
	LCDDriver_SendCommand(LCD_COMMAND_GRAM); // memory write
	HAL_Delay(5);
#endif
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

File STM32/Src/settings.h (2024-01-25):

#ifndef SETTINGS_h
#define SETTINGS_h

#include "bands.h"
#include "functions.h"
#include "hardware.h"
#include <stdbool.h>
#include <stdint.h>
#include <stdio.h>

#define STM32_VERSION_STR "9.3.1" // current STM32 version

#if defined(FRONTPANEL_LITE)
#define FPGA_VERSION_STR "8.0.0" // needed FPGA version Wolf-Lite
#else
#define FPGA_VERSION_STR "8.2.0" // needed FPGA version Wolf/Wolf-2/Wolf-X1
#endif

#define SETT_VERSION 149        // Settings config version
#define CALIB_VERSION 91        // Calibration config version
#define WIFI_SETTINGS_VERSION 5 // WiFi config version

#define TRX_SAMPLERATE 48000                 // audio stream sampling rate during processing and TX (NOT RX!)
#define MAX_TX_AMPLITUDE_MULT 0.85f          // Maximum amplitude when transmitting to FPGA
#define AGC_CLIPPING 6.0f                    // Limit over target in AGC, dB
#define TOUCHPAD_DELAY 200                   // Anti-bounce time for pressing the touchpad
#define AUTOGAIN_TARGET_AMPLITUDE 20000.0f   // target autocorrector amplitude
#define AUTOGAIN_MAX_AMPLITUDE 30000.0f      // maximum autocorrector amplitude
#define AUTOGAIN_CORRECTOR_WAITSTEP 5        // waiting for the averaging of the results when the auto-corrector of the input circuits is running
#define KEY_HOLD_TIME 500                    // time of long pressing of the keyboard button for triggering, ms
#define SHOW_LOGO true                       // Show logo on boot (from images.h)
#define POWERDOWN_TIMEOUT 1000               // time of pressing the shutdown button, for operation, ms
#define POWERDOWN_FORCE_TIMEOUT 2000         // force time
#define USB_RESTART_TIMEOUT 5000             // time after which USB restart occurs if there are no packets
#define SNTP_SYNC_INTERVAL (60 * 2)          // Time synchronization interval via NTP, sec
#define SCANNER_NOSIGNAL_TIME 50             // time to continue sweeping if signal too low
#define SCANNER_NOSIGNAL_TIME_MEM 500        // time to continue sweeping if signal too low (MEM channels scan mode)
#define SCANNER_SIGNAL_TIME_FM 5000          // time to continue sweeping if signal founded for FM
#define SCANNER_SIGNAL_TIME_OTHER 1000       // time to continue sweeping if signal founded for SSB
#define SCANNER_FREQ_STEP_WFM 100000         // step for freq scanner for WFM
#define SCANNER_FREQ_STEP_NFM 25000          // step for freq scanner for NFM
#define SCANNER_FREQ_STEP_OTHER 500          // step for freq scanner for SSB
#define ENCODER_MIN_RATE_ACCELERATION 2.0f   // encoder enable rounding if lower than value
#define DXCLUSTER_UPDATE_TIME (1000 * 60)    // interval to get cluster info, 1min
#define WOLF_CLUSTER_UPDATE_TIME (1000 * 30) // interval to get WOLF cluster info, 30sec
#define SAT_UPDATE_TIME (1000 * 1)           // interval to calculate SAT info, 1sec
#define NORMAL_SWR_SAVED 1.5f                // ATU SWR target for saved settings
#define NORMAL_SWR_TUNE 1.2f                 // ATU SWR target for new tune
#define IDLE_LCD_BRIGHTNESS 5                // Low brightness for IDLE mode (dimmer)
#define CW_ADD_GAIN_IF 18.0f                 // additional IF gain in CW
#define TX_LPF_TIMEOUT (180 * 1000)          // TX LPF On Timeout, millisec (3 min)
#define SWR_PROTECTOR_MAX_POWER 20.0f        // drop down to PWR %, if SWR high
#define FREE_TUNE_CENTER_ON_IDLE_SEC 20      // center spectrum on idle while in free tune mode

#define FULL_DUPLEX TRX.Full_Duplex             // Enable duplex RX and TX
#define SHOW_RX_FFT_ON_TX FULL_DUPLEX           // Show RX FFT channel on TX
#define LISTEN_RX_AUDIO_ON_TX SHOW_RX_FFT_ON_TX // Process audio RX channel for TX mode

#define CODEC_BITS_FULL_SCALE 4294967296 // maximum signal amplitude in the bus // powf (2, FPGA_BUS_BITS)
#define USB_DEBUG_ENABLED true           // allow using USB as a console
#define SWD_DEBUG_ENABLED false          // enable SWD as a console
#define LCD_DEBUG_ENABLED false          // enable LCD as a console

#define AUTOGAINER_TAGET (ADC_FULL_SCALE / 3)
#define AUTOGAINER_HYSTERESIS (ADC_FULL_SCALE / 13)

#define MAX_WIFIPASS_LENGTH 32
#define MAX_CALLSIGN_LENGTH 16
#define MAX_CW_MACROS_LENGTH 61
#define MAX_CW_MACROS_NAME_LENGTH 6
#define ALLQSO_TOKEN_SIZE 16

#if defined(FRONTPANEL_MINI)
#define MAX_CHANNEL_MEMORY_NAME_LENGTH 6
#else
#define MAX_CHANNEL_MEMORY_NAME_LENGTH 10
#endif

#define SAT_NAME_MAXLEN 20
#define SAT_TLE_MAXCOUNT 28
#define SAT_TLE_LINE_MAXLEN 70
#define SAT_QTH_LINE_MAXLEN 12

#define ATU_MAX_FREQ_KHZ 60000
#define ATU_MEM_STEP_MIN_KHZ 50
#define ATU_MEM_COUNT (ATU_MAX_FREQ_KHZ / ATU_MEM_STEP_MIN_KHZ) // 1200 positions * 3byte = 3600 bytes for each ANT
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

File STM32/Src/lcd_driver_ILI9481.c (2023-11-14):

#include "settings.h"
#if (defined(LCD_ILI9481) || defined(LCD_ILI9481_IPS) || defined(LCD_HX8357B) || defined(LCD_HX8357C) || defined(LCD_ILI9486) || defined(LCD_ST7796S))

// Header files
#include "fonts.h"
#include "functions.h"
#include "lcd_driver.h"
#include "lcd_driver_ILI9481.h"
#include "main.h"

//***** Functions prototypes *****//
static inline void LCDDriver_SetCursorPosition(uint16_t x, uint16_t y);
inline void LCDDriver_SetCursorAreaPosition(uint16_t x1, uint16_t y1, uint16_t x2, uint16_t y2);

// Write command to LCD
inline void LCDDriver_SendCommand(uint16_t com) { *(__IO uint16_t *)((uint32_t)(LCD_FSMC_COMM_ADDR)) = com; }

// Write data to LCD
inline void LCDDriver_SendData(uint16_t data) { *(__IO uint16_t *)((uint32_t)(LCD_FSMC_DATA_ADDR)) = data; }

// Write data to LCD
inline void LCDDriver_SendData16(uint16_t data) { *(__IO uint16_t *)((uint32_t)(LCD_FSMC_DATA_ADDR)) = data; }

// Write pair command-data
inline void LCDDriver_writeReg(uint16_t reg, uint16_t val) {
	LCDDriver_SendCommand(reg);
	LCDDriver_SendData(val);
}

// Read command from LCD
inline uint16_t LCDDriver_ReadStatus(void) { return *(__IO uint16_t *)((uint32_t)(LCD_FSMC_COMM_ADDR)); }
// Read data from LCD
inline uint16_t LCDDriver_ReadData(void) { return *(__IO uint16_t *)((uint32_t)(LCD_FSMC_DATA_ADDR)); }

// Read Register
inline uint16_t LCDDriver_readReg(uint16_t reg) {
	LCDDriver_SendCommand(reg);
	return LCDDriver_ReadData();
}

// Initialise function
void LCDDriver_Init(void) {
#if (defined(LCD_ILI9481) || defined(LCD_ILI9481_IPS) || defined(LCD_HX8357B) || defined(LCD_ST7796S))
#define ILI9481_COMM_DELAY 20

	LCDDriver_SendCommand(LCD_COMMAND_SOFT_RESET); // 0x01
	HAL_Delay(ILI9481_COMM_DELAY);

	LCDDriver_SendCommand(LCD_COMMAND_EXIT_SLEEP_MODE); // 0x11
	HAL_Delay(ILI9481_COMM_DELAY);

	LCDDriver_SendCommand(LCD_COMMAND_NORMAL_MODE_ON); // 0x13

#if (defined(LCD_ILI9481) || defined(LCD_HX8357B))
	LCDDriver_SendCommand(LCD_COMMAND_POWER_SETTING); //(0xD0);
	LCDDriver_SendData(0x07);
	LCDDriver_SendData(0x42);
	LCDDriver_SendData(0x18);

	LCDDriver_SendCommand(LCD_COMMAND_VCOM); //(0xD1);
	LCDDriver_SendData(0x00);
	LCDDriver_SendData(0x07);
	LCDDriver_SendData(0x10);

	LCDDriver_SendCommand(LCD_COMMAND_NORMAL_PWR_WR); //(0xD2);
	LCDDriver_SendData(0x01);
	LCDDriver_SendData(0x02);
	HAL_Delay(ILI9481_COMM_DELAY);

#if (defined(LCD_HX8357B))
	LCDDriver_SendCommand(LCD_COMMAND_PANEL_DRV_CTL); //(0xC0);
	LCDDriver_SendData(0x10);
	LCDDriver_SendData(0x3B);
	LCDDriver_SendData(0x00);
	LCDDriver_SendData(0x02);
	LCDDriver_SendData(0x11);
	HAL_Delay(ILI9481_COMM_DELAY);
#endif

	LCDDriver_SendCommand(LCD_COMMAND_FR_SET); //(0xC5);
	LCDDriver_SendData(0x03);
	HAL_Delay(ILI9481_COMM_DELAY);

	LCDDriver_SendCommand(LCD_COMMAND_GAMMAWR); //(0xC8);
	LCDDriver_SendData(0x00);
	LCDDriver_SendData(0x32);
	LCDDriver_SendData(0x36);
	LCDDriver_SendData(0x45);
	LCDDriver_SendData(0x06);
	LCDDriver_SendData(0x16);
	LCDDriver_SendData(0x37);
	LCDDriver_SendData(0x75);
	LCDDriver_SendData(0x77);
	LCDDriver_SendData(0x54);
	LCDDriver_SendData(0x0C);
	LCDDriver_SendData(0x00);
	HAL_Delay(ILI9481_COMM_DELAY);
#endif

#if (defined(LCD_ILI9481_IPS))
	LCDDriver_SendCommand(LCD_COMMAND_POWER_SETTING); //(0xD0);
	LCDDriver_SendData(0x07);
	LCDDriver_SendData(0x42);
	LCDDriver_SendData(0x17);

	LCDDriver_SendCommand(LCD_COMMAND_VCOM); //(0xD1);
	LCDDriver_SendData(0x00);
	LCDDriver_SendData(0x1C);
	LCDDriver_SendData(0x1F);

	LCDDriver_SendCommand(LCD_COMMAND_NORMAL_PWR_WR); //(0xD2);
	LCDDriver_SendData(0x01);
	LCDDriver_SendData(0x11);
	HAL_Delay(ILI9481_COMM_DELAY);

	LCDDriver_SendCommand(LCD_COMMAND_PANEL_DRV_CTL); //(0xC0);
	LCDDriver_SendData(0x10);
	LCDDriver_SendData(0x3B);
	LCDDriver_SendData(0x00);
	LCDDriver_SendData(0x02);
	LCDDriver_SendData(0x11);
	HAL_Delay(ILI9481_COMM_DELAY);

	LCDDriver_SendCommand(LCD_COMMAND_FR_SET); //(0xC5);
	LCDDriver_SendData(0x03);
	HAL_Delay(ILI9481_COMM_DELAY);

	LCDDriver_SendCommand(LCD_COMMAND_GAMMAWR); //(0xC8);
	LCDDriver_SendData(0x00);
	LCDDriver_SendData(0x32);
	LCDDriver_SendData(0x36);
	LCDDriver_SendData(0x45);
	LCDDriver_SendData(0x06);
	LCDDriver_SendData(0x16);
	LCDDriver_SendData(0x37);
	LCDDriver_SendData(0x75);
	LCDDriver_SendData(0x77);
	LCDDriver_SendData(0x54);
	LCDDriver_SendData(0x0C);
	LCDDriver_SendData(0x00);
	HAL_Delay(ILI9481_COMM_DELAY);

	LCDDriver_SendCommand(0xB0);
	LCDDriver_SendData(0x00); // CommandAccessProtect
	LCDDriver_SendCommand(0xE4);
	LCDDriver_SendData(0xA0);
	LCDDriver_SendCommand(0xF0);
	LCDDriver_SendData(0x01);
#endif

	LCDDriver_SendCommand(LCD_COMMAND_MADCTL); //(0x36);
	LCDDriver_SendData(LCD_PARAM_MADCTL_BGR);
	HAL_Delay(ILI9481_COMM_DELAY);

	LCDDriver_SendCommand(LCD_COMMAND_PIXEL_FORMAT); //(0x3A);
	LCDDriver_SendData(0x55);
	HAL_Delay(ILI9481_COMM_DELAY);

	LCDDriver_SendCommand(LCD_COMMAND_COLUMN_ADDR); //(0x2A);
	LCDDriver_SendData(0x00);
	LCDDriver_SendData(0x00);
	LCDDriver_SendData(0x01);
	LCDDriver_SendData(0x3F);
	HAL_Delay(ILI9481_COMM_DELAY);

	LCDDriver_SendCommand(LCD_COMMAND_PAGE_ADDR); //(0x2B);
	LCDDriver_SendData(0x00);
	LCDDriver_SendData(0x00);
	LCDDriver_SendData(0x01);
	LCDDriver_SendData(0xDF);
	HAL_Delay(ILI9481_COMM_DELAY);

#if defined(LCD_HX8357B) || defined(LCD_ILI9481_IPS)
	LCDDriver_SendCommand(LCD_COMMAND_COLOR_INVERSION_ON); //(0x21);
	HAL_Delay(ILI9481_COMM_DELAY);
#endif

	LCDDriver_SendCommand(LCD_COMMAND_IDLE_OFF); //(0x38);
	HAL_Delay(ILI9481_COMM_DELAY);

	LCDDriver_SendCommand(LCD_COMMAND_DISPLAY_ON); //(0x29);
	HAL_Delay(ILI9481_COMM_DELAY);
#endif
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

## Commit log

2022-07-06 Add test W-Lite FPGA FW
    [rx_ciccomp_param.txt, tx_ciccomp_param.txt]
2022-07-16 Restruct folders
    [40x40x10 DC Fan.SLDPRT, AD8307_Add_on_v3.PcbDoc, AD8307_Add_on_v3.PrjPcb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]
2022-07-16 Add X1 files
    [20mm_Main_Encoder.stl, 20mm_Sec_Encoder.stl, BOM-MAIN_V0.3.xlsx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]
2022-07-16 Add W-Lite files
    [16-SOIC_MCP3008-I_SL.x_t, BAT__CH224-2032_POWER_BAT.x_t, BUT__6x6_SMD_Tactile_switches.x_t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]
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2022-07-17 Add VOX to func buttons
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2022-07-25 W-Lite update
    [tx_ciccomp_param.txt]
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2022-08-01 Change func buttons layout
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2022-08-03 Update analog meter for low power
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2022-08-09 Add new PCB link
2022-08-09 Samplex switch fix
2022-08-09 Refactoring ENC2 func buttons
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2022-08-10 W-Lite Func buttons fix
2022-08-16 W-Lite LCD Update fix
    [lcd.c]
2022-08-17 Wolf-Mini proto
    [rx_ciccomp_param.txt, tx_ciccomp_param.txt]
2022-08-18 ADC fix
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2022-08-20 extend VCXO correction range
    [sd.c]
2022-08-31 Low step encoder fix
    [trx_manager.c]
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2022-09-19 FFT Lens 7inch fix
2022-09-27 VCXO Correction and DAC update
    [DAC_freq.xlsx, tx_ciccomp_param.txt]
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2022-09-30 Tune power adjusting fix
    [audio_processor.c, settings.h]
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2022-10-01 Add snap button
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2022-10-15 Power meter calibration assistant
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2022-10-16 Capacitor polarity fix
    [ADC.SchDoc, DAC.SchDoc, MOTHERBOARD.PrjPcb]
2022-10-16 Update DAC regulator
    [POWER.SchDoc]
2022-10-16 Update USB insulator
    [CONNECTIONS.SchDoc]
2022-10-16 Update generated files
    [BOM-MOTHERBOARD-RA9UCN-mod-rev30.csv, BOM-MOTHERBOARD-rev32.csv, CLOCK_GENERATOR.SchDoc]
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2022-10-20 Update motherboard
    [BOM-MOTHERBOARD-rev32.csv, CONNECTIONS.SchDoc, MOTHERBOARD.PrjPcb]
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2022-10-23 Update BOM
    [BOM-MOTHERBOARD-rev32.csv, BOM-MOTHERBOARD-rev32.xlsx]
2022-10-23 Add RU4PN QRP Gerbers
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2022-10-26 Bottom buttons function status
2022-10-26 not-resettable wifi area in eeprom
    [sd.c, settings.c, settings.h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]
2022-10-29 SD's without multiple read fix
    [settings.c]
2022-10-31 Extend bottom buttons zone
2022-11-01 New RU4PN QRP Board
2022-11-01 Save data from fast SQL regulator
2022-11-01 Mode button fix
2022-11-01 Show ESP version error
    [settings.c, wifi.c]
2022-11-02 CN Theme VFO-B fix
    [settings.c]
2022-11-02 LCD ENC2 mode fix
    [lcd.c]
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2022-11-09 CESSB button handler fix
    [settings.c, trx_manager.c]
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2022-11-10 Motherboard rev33
    [ADC.SchDoc, AUDIO CODEC.SchDoc, BOM-MOTHERBOARD-rev32.xlsx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]
2022-11-16 ADD W-lite Case STL
    [BOT-LITE.STL, Front Lite V1.STL, Front Lite V2.STL]
2022-11-21 Per band power saving
2022-11-22 Button borders fix
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2023-01-09 LCD wake up fix
    [lcd.c]
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2023-01-14 Update freq
    [tx_ciccomp_param.txt]
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2023-01-19 Do not reset RIT/XIT
    [trx_manager.c]
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2023-01-29 VCXO Corrector TX contol
    [sd.c, settings.c, settings.h]
2023-01-29 Add Wolf-Lite-2 FPGA firmware
    [rx_ciccomp_param.txt, tx_ciccomp_param.txt]
2023-01-29 Revert "W-Mini buttons update"
    This reverts commit 592683cf93a296edf82ec806421388a51b44311c.
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2023-02-05 Calibrations fix
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2023-02-07 Samplerate fix
2023-02-15 Add RF-UNIT-BIG-RU4PN-rev5.4 board
    [PCB.pcbdoc, Sheet.schdoc]
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2023-02-19 Add Wolf-adapter board
    [ADAPTER_WOLF.SchDoc, Bill of Materials-WOLF-Adapter-rev1.1.xls, WOLF-Adapter.PcbLib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]
2023-02-20 Update wolf-adapter
    [ADAPTER_WOLF.SchDoc, WOLF-Adapter_V2.PcbDoc]
2023-02-22 Update RF-UNIT-BIG-RU4PN board
    [BOM-RF-UNIT-BIG-RU4PN-rev5.5.xls]
2023-02-24 Update assembly file
    [MOTHERBOARD.PrjPcb]
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2023-03-10 fix set freq step calc in slow mode
    [settings.c, settings.h, trx_manager.c]
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2023-03-17 Add External PA contol board
    [SBORKA_WL.SchDoc, WL-ADC.SchDoc, WL-AUDIO.SchDoc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]
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2023-03-19 Add wolf-2 boards
    [Codec.SchDoc, Conn.SchDoc, Control.SchDoc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]
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2023-03-23 Update Wolf-2 schematic
    [Power.SchDoc, RB_Audio.SchDoc, R_BOARD.PrjPcb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]
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2023-03-25 I2C fix
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2023-03-26 Hide error on inited
    [settings.c]
2023-03-30 Update wolf-2 boards
    [MB_Conn.SchDoc, MB_Control.SchDoc, Registr.xlsx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]
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2023-04-02 Add Front panel 3D model
    [верхняя планка волк7_1.stl, верхняя планка волк7_2.stl, верхняя планка волк7_3.stl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]
2023-04-02 Panel update
    [кнопка_низ_7.stl]
2023-04-11 BW trapez style fix
    [lcd.c]
2023-04-12 Add ALC inverted logic
    [sd.c, settings.c, settings.h]
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2023-04-19 Default layout bug fix
    [lcd.c]
2023-04-19 Settings memory map fix
    [settings.h]
2023-04-20 Bus interface update
    [rx_ciccomp_param.txt, tx_ciccomp_param.txt]
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2023-04-22 Update DAC filter
    [BOM-MOTHERBOARD-rev33.xls, BOM-MOTHERBOARD-rev33.xlsx, DAC.SchDoc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]
2023-04-28 mistake in a word
    [settings.c, wifi.c]
2023-04-28 FT8 sequence with skip first tx
    [sd.c]
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2023-05-09 DAC PLL update
    [DAC_freq.xlsx, tx_ciccomp_param.txt]
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2023-05-12 Add external PLL board
    [BOM_WOLF_PLL.xlsx]
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2023-05-15 Fix ADC raw data
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2023-05-28 Sensors fix
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2023-07-09 W-Mini bottom menu redraw fix
    [lcd.c]
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2023-07-09 Fix power limiting
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2023-07-13 RU4PN board fix
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2023-07-30 Fix snap with zero bins
    [settings.h]
2023-07-30 DPD fix on Lite
    [settings.h]
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2023-09-09 System menu pages count fix
    [settings.h]
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2023-09-11 DAC PLL frequency switch by band
    [DAC_freq.xlsx, tx_ciccomp_param.txt]
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2023-09-14 Fix DAC Shift setting
    [settings.h]
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2023-09-18 Add USB IQ swap
    [audio_processor.c, sd.c, settings.c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]
2023-09-27 Clean projects
    [rx_ciccomp_param.txt, tx_ciccomp_param.txt]
2023-09-27 SWR protector CW fix
    [trx_manager.c]
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2023-09-27 Wolf-2 FAN fix
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2023-09-28 Save RX LPF filter settings separately per band
2023-10-08 VFO-B BW show fixes
    [settings.h, trx_manager.c]
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2023-10-09 Add vertical Ttouchpad flip
    [sd.c, settings.c, settings.h]
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2023-10-12 Allow USB Debug print on CAT port for W-Lite
2023-10-12 Fix W-Lite self test
    [settings.h]
2023-10-15 Исправил вывод RX-TX-TU, чтобы из под новой надписи не торчала старая. Перед выводом TX-TU вывожу надпись RX цветом фона (затираю ее)
    [lcd.c]
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2023-10-16 Изменил латинскую букву T, сделал ее пошире, чтобы избежать дефектов при отображении RX-TX В связи с изменением шрифта убрал ранее введеное стирание знакоместа под надписью RX
2023-10-16 Update screen_layout_480x320.cpp
    Увеличил ширину блока вывода моды, чтобы не оставался на экране кончик надписи RTTY
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2023-10-18 Сделан режим контур и контур градиент.
    Контур не закончен.
2023-10-18 File manager closing fix
    [filemanager.c]
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2023-10-20 Изменение редактирования даты и времени. Устранение ошибочного инкремента времени при входе в процедуру
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2023-10-20 RF unit import fix
    [sd.c, settings.h]
2023-10-21 Bug fixes & code format
    [lcd.c, settings.c]
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2023-10-21 Упорядочена работа большого и малого валкодера в меню. Малый валкодер - навигация по меню и выбор редактируемого параметра. Больной валкодер - изменение этого параметра.
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2023-10-25 Мелкие исправления внешнего вида Волк Лайт
    [lcd.c]
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2023-10-31 Изменил название клавишь работы с памятью на M>VFO и VFO>M Thanks Dire Wolf
2023-10-31 Исправлена индикация MUTE при долгом нажатии на клавишу MUTE
    [lcd.c]
2023-10-31 Добавлена индикация SPLIT Режим SPLIT отключается при смене диапазона. Thanks Дмитрий.
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2023-11-04 Вернул в карусель клавиши
    Вернул в карусель клавиши BAND+ ,BAND- и NB
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2023-11-08 Настройка Noise Blanker
    NB_FIR_SIZE 128
    NB_order 4
    [audio_processor.c]
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2023-11-15 Подвинул индикатор ширины полосы пропускания и подпись под ним.
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2023-11-18 W-Mini new FPGA pinout
    [rx_ciccomp_param.txt, tx_ciccomp_param.txt]
2023-11-18 Исправление команды САТ NR
    [trx_manager.c]
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2023-11-18 Wolf-Mini FPGA updates
    [rx_ciccomp_param.txt, tx_ciccomp_param.txt]
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2023-11-28 Update mic resistor
    [AUDIO CODEC.SchDoc, MOTHERBOARD.PrjPcb]
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2023-12-04 Изменение интерфейса Волк Мини Добавлена работа с каналами памяти, новые клавиши для памяти
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2023-12-11 W-Lite PCB labels fix
    [Wolf-Lite.PrjPcb]
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2024-01-10 Update boards
    [ADC.SchDoc, AUDIO CODEC.SchDoc, CONNECTIONS.SchDoc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]
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2024-01-21 Экспериментальная УКВ плата
    [WL_1.2G.SchDoc, WL_144.SchDoc, WL_430.SchDoc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]
2024-01-22 Update VHF board
    [WL_BPF.SchDoc, WL_PGA_ATT.SchDoc, WL_VHF.PrjPcb]
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2024-01-22 Memory button handler fix
    [lcd.c]
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2024-01-23 Изменено название VD1, VD2
    [WL-Power.SchDoc, Wolf-Lite.PrjPcb]
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
